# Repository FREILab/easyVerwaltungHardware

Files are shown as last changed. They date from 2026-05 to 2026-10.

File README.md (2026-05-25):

# easyVerwaltung Hardware

Firmware und Dokumentation für die **easyVerwaltung**-Hardware des FREILab. Das System steuert Maschinenzugang, Nutzungsprotokollierung und Sicherheit via RFID-Authentifizierung gegen das easyVerwaltung-Backend.

---

## Hardware-Übersicht

### RFID-Box — Maschinenfreigabe

| Projekt | Hardware | API | Status |
|---|---|---|---|
| [RFID_BOX_legacy](firmware/projects/RFID_BOX_legacy/) | ESP32 Dev1 | Legacy | Stabil — [v1.0.0](https://github.com/FREILab/easyVerwaltungHardware/releases/tag/rfid-box-legacy%2Fv1.0.0) |
| [RFID_BOX_easyVerwaltung](firmware/projects/RFID_BOX_easyVerwaltung/) | ESP32 Dev1 | easyVerwaltung | Getestet — Server noch nicht in Production |

### Tür-Steuerung

| Projekt | Hardware | API | Status |
|---|---|---|---|
| [DOOR_legacy](firmware/projects/DOOR_legacy/) | Arduino UNO R4 WiFi | Legacy | Scheduled for Deletion |
| [DOOR_legacy_ESPArdu](firmware/projects/DOOR_legacy_ESPArdu/) | RobotDyn UNO+WiFi R3 (ATmega328P + ESP8266) | Legacy | Stabil — [v1.0.0](https://github.com/FREILab/easyVerwaltungHardware/releases/tag/door-legacy-espardu%2Fv1.0.0) |
| [DOOR_easyVerwaltung](firmware/projects/DOOR_easyVerwaltung/) | Arduino UNO R4 WiFi | easyVerwaltung | In Entwicklung |

### Lasersaur HMI

| Projekt | Hardware | API | Status |
|---|---|---|---|
| [LASERSAUR_HMI_legacy](firmware/projects/LASERSAUR_HMI_legacy/) | Arduino Mega + Ethernet-Shield | Legacy | Stabil (nicht mit neuem Server getestet) — wird durch ESPArdu ersetzt |
| [LASERSAUR_HMI_ESPArdu](firmware/projects/LASERSAUR_HMI_ESPArdu/) | Mega2560 WiFi R3 (ATmega2560 + ESP8266) | Legacy | Implementiert, noch nicht getestet |
| [LASERSAUR_HMI_easyVerwaltung](firmware/projects/LASERSAUR_HMI_easyVerwaltung/) | Arduino Giga R1 | easyVerwaltung | In Entwicklung |

### Machine Node

| Projekt | Hardware | API | Status |
|---|---|---|---|
| [MachineNode_legacy](firmware/projects/MachineNode_legacy/) | ESP32-S3-WROOM-1-N16R8 | Legacy | Stabil |
| [MachineNode_easyVerwaltung](firmware/projects/MachineNode_easyVerwaltung/) | ESP32-S3-WROOM-1-N16R8 | easyVerwaltung | Geplant |

---

## Repository-Struktur

```
firmware/
  projects/          # Firmware-Targets (je ein PlatformIO-Projekt)
  shared/
    easyAPI/         # Gemeinsame Backend-Kommunikation (HTTP/JSON)
```

Jedes Projekt in `projects/` enthält eine eigene `README.md` mit Hardware-Details, DIP-Belegung, Flash-Anleitung und Debugging-Hinweisen.

---

## Einrichtung

### Voraussetzungen

- Python ≥ 3.8
- PlatformIO Core (`pip install platformio`)

### Credentials

Jedes Projekt benötigt eine `platformio.secrets.ini` (nicht in Git). Vorlage liegt als `.example`-Datei bei:

```bash
cp platformio.secrets.ini.example platformio.secrets.ini
# Datei befüllen, dann:
pio run
```

Details zu den Feldern stehen in der jeweiligen Projekt-README.

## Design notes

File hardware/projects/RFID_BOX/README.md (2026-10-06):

# Machine Node / RFID_BOX

> **Sicherheit geht vor Kosten, Baugröße und Bauteilzahl.** Das Gerät
> schaltet Netzspannung in einer Werkstatt, in der ungeschulte Personen
> daneben stehen. Wo Ziele kollidieren, gewinnt die Sicherheit.
>
> Vier Festlegungen sind bindend und werden nicht aufgeweicht:
>
> - Die Barriere Netz ↔ SELV beträgt **8 mm Luft- und Kriechstrecke** und
>   wird nicht auf den Normwert von 5 mm reduziert. Maßgeblich sind die
>   Bauteile, die sie queren, nicht das Minimum der Norm.
> - Bauteile über der Barriere brauchen **verstärkte oder doppelte
>   Isolierung** bei 250 V Arbeitsspannung. Eine hohe Prüfspannung in kV
>   allein genügt nicht — sie sagt über die Isolationsklasse nichts aus.
> - **Ein Einzelfehler darf nicht nach außen wirken.** Neue Schaltungsteile
>   werden gegen die [FMEA](#fmea) geprüft, bevor sie ins Layout gehen.
> - **Beim geöffneten Gerät ist nichts Netzführendes berührbar.** Feste
>   Abdeckplatten über dem I/O-Board geben nur die Feldterminals und den
>   Sicherungshalter frei. MCU- und RFID-Board führen kein 230 V und dürfen
>   angefasst werden. Siehe [Aufbau](#aufbau).
>
> Die Auslegung dazu steht in
> [Leiterbahnbreiten und Abstände](#leiterbahnbreiten-und-abstände).

## Einleitung

Dies ist der **RFID Node**: ein kompaktes Steuergerät, das elektrische
Geräte und Maschinen in der Werkstatt (z.B. Standfräse, Drehmaschine, FKS)
per RFID-Karte freischaltet. Er prüft die RFID-Karte einer Nutzerin oder
eines Nutzers gegen easyVerwaltung, gibt bei gültiger Berechtigung die
Maschine frei und schaltet sie beim Stopp oder bei Kartenentzug wieder ab.

Technisch ist der Node als Stack aus mehreren kompakten Platinen aufgebaut
(Netzteil/Schaltausgang, Controller mit Bedienoberfläche, RFID-Frontend),
ergänzt um optionale Erweiterungsboards für Maschinen mit zusätzlichem
Bedarf (z.B. NAMUR-I/O oder eine Notaus-/Bremsschleife). Die konkrete
Aufteilung und Auslegung folgt in den weiteren Kapiteln dieses Dokuments.

Die Anforderungen, aus denen diese Auslegung abgeleitet ist, stehen separat
in [Anforderungen.md](Anforderungen.md).

## Aufbau

Das Gehäuse ist 3D-gedruckt und staubdicht ausgeführt. Display und LED-Ring
sind von aussen sichtbar und durch eine Plexiglasscheibe geschützt; der
LED-Ring selbst sitzt dabei innerhalb des Gehäuses. Der Stopp-Knopf ist von
aussen erreichbar.

Alle Kabel werden einseitig über Kabeldurchführungen ins Gehäuse geführt, von
links nach rechts:

1. Netz-Eingang 230 V
2. Schaltausgang: geschaltete 230 V oder Steuerleitung für ein externes
   Schütz
3. Optionale Notaus-Schleife
4. Optionales Extension-I/O (NAMUR oder Digital-I/O)

Nicht verwendete Durchführungen werden verschlossen.

Die Boards werden über Board-to-Board-Stecker als Stack gesteckt und
geklipst — keine Kabelverbindungen zwischen den Platinen.

### Berührschutz

Das Gerät wird im Servicefall geöffnet, während es unter Umständen noch am
Netz hängt. Deshalb:

- Über dem I/O-Board sitzen **fest installierte, 3D-gedruckte
  Abdeckplatten**. Sie geben nur die Feldterminals und den Sicherungshalter
  frei — beide sind berührsichere Bauformen (WAGO Hebelklemme, WR-FSH mit
  Shocksafe PC2/IP20). Alles andere Netzführende bleibt abgedeckt.
- Die Platten sind kein Deckel, der beim Öffnen mitkommt: sie bleiben am
  Board bzw. am Gehäuseunterteil und lassen sich nur mit Werkzeug lösen.
- **MCU- und RFID-Board führen kein 230 V** und dürfen im geöffneten Zustand
  berührt werden. Das ist eine bindende Randbedingung, keine Momentaufnahme
  — es darf kein netzführendes Netz auf diese Boards wandern.

Zusätzlich werden alle Boards **lackiert** (Schutzlack), um den IP-Schutz
über die Lebensdauer zu stützen: Sägemehl und Feuchtigkeit sollen auf
Dauer keine Kriechpfade bilden. Vom Lack ausgenommen bleiben Feldterminals,
Sicherungskontakte und die Board-to-Board-Stecker.

Der Lack ersetzt keine Abstände: Kriech- und Luftstrecken werden weiterhin
nach [Leiterbahnbreiten und Abstände](#leiterbahnbreiten-und-abstände)
bemessen, als wäre kein Lack vorhanden.

## Elektronik

Das Gerät ist als Platinenstack aufgebaut:

- **Oberste PCB (RFID-Board):** RFID-Antenne, ggf. Display und LED-Ring.
- **Mittlere PCB (MCU-Board):** Mikrocontroller (ESP32), Buzzer und
  Peripherie.
- **Unterste PCB (I/O-Board):** 230-V-Netz und Schaltausgang, dazu die
  Extension-Header für das E-Stop Extension Board und das Extension Board.
  Hiervon gibt es **zwei getrennte Boards mit eigenem Layout**, von denen
  pro Gerät genau eines bestückt wird:
  - **I/O-Board 230V** — Lastrelais und Lastmessung zum direkten Schalten
    von Lasten bis 8 A.
  - **I/O-Board 24V** — potentialfreier Kontakt für ein externes Schütz.
    Ohne Lastpfad und Lastmessung; dadurch deutlich einfacher,
    rund 33 € günstiger und ohne Bedarf an 70 µm Kupfer.

  Beide haben denselben Formfaktor und denselben Board-to-Board-Stecker zum
  MCU-Board.

## Architektur

Neben dem festen Dreier-Stack (I/O-, MCU-, RFID-Board) gibt es zwei
optionale, steckbare Erweiterungsboards, die auf das I/O-Board gesteckt
werden:

- **Extension Board:** generisches Zusatzboard mit zwei Bestückvarianten —
  **NAMUR** (zwei optoisolierte NAMUR-Ausgänge, ein galvanisch getrennter
  NAMUR-Eingang) oder **Digital-I/O** (einfache digitale Ein-/Ausgänge, noch
  nicht spezifiziert). Ein Node trägt höchstens eine Variante.
- **E-Stop Extension Board:** einfaches Relais (24 V / 100 mA), dessen Kontakt
  in die Notaus-/Interlock-Schleife bzw. Bremsversorgung der Maschine
  eingeschleift wird. Fail-safe: stromlos = Notaus-Schleife unterbrochen;
  öffnet bei Stopp/Kartenentzug sofort, während die Hauptversorgung erst
  nach der Nachlaufzeit trennt (Details siehe
  [Anforderungen.md](Anforderungen.md)).

## Blockdiagramm

```mermaid
flowchart TB
    subgraph IO["I/O-Board — eines von beiden"]
        direction LR
        NETZ([Terminal: Netz-Eingang 230V])
        OUT([Terminal: Schaltausgang])
        REL["Lastrelais 8A<br/>(I/O-Board 230V)"]
        POTFREI["Potentialfreier Kontakt 24V 100mA<br/>(I/O-Board 24V)"]
        MESS["Lastmessung<br/>(nur I/O-Board 230V)"]

        NETZ --> MESS --> REL --> OUT
        NETZ --> POTFREI --> OUT

        subgraph ESTOP["E-Stop Extension Board (optional)"]
            direction LR
            K3[Notaus-Kontakt 24V 100mA]
            ESTOP_T([Terminal: Notaus-Schleife])
            K3 --- ESTOP_T
        end

        subgraph EXT["Extension Board (optional)"]
            direction LR
            EXTIO[NAMUR ODER Digital-I/O]
            IO_T([Terminal: Extension-I/O])
            EXTIO --- IO_T
        end
        
    end

    subgraph MCU["MCU-Board"]
        direction LR
        ESP[ESP32]
        BUZ[Buzzer]
        STOP[Stopp-Taster]
        USB([USB-C: Erstprogrammierung/Debug])

        ESP ~~~ USB
        BUZ ~~~ STOP

        ESP --- USB
    end

    subgraph RFID["RFID-Board"]
        direction LR
        NFC[NFC-Controller PN532]
        ANT[RFID-Antenne]
        DISP["Display (ggf.)"]
        RING["LED-Ring (ggf.)"]

        NFC --- ANT

        DISP ~~~ RING
    end

    RFID --- MCU
    MCU --- IO

    classDef term230 fill:#1565c0,color:#fff,stroke:#0d47a1
    classDef termSELV fill:#90caf9,color:#000,stroke:#1565c0
    classDef part230 fill:#ff9800,color:#000,stroke:#e65100
    classDef partSELV fill:#81c784,color:#000,stroke:#2e7d32

    class NETZ,OUT term230
    class ESTOP_T,IO_T,USB termSELV
    class REL,MESS part230
    class POTFREI,K3,EXTIO,ESP,BUZ,STOP,NFC,ANT,DISP,RING partSELV
```

Die Form kennzeichnet die Art des Elements, die Farbe die Spannungsebene:

- Formen: abgerundet = Terminal/Steckverbinder, eckig = Funktionsblock; als
  "(optional)" markierte Boards sind steckbare Erweiterungen im I/O-Board.
- Farben: blau = 230-V-Terminal, hellblau = Kleinspannungs-Terminal,
  orange = 230-V-führender Schaltungsteil, grün = Kleinspannungs-
  Schaltungsteil.

## Power Distribution

Die gesamte Versorgung kommt aus dem Netz-Eingang 230 V auf dem I/O-Board
und teilt sich dort in zwei Pfade:

- **Lastpfad (nur I/O-Board 230V):** Netz-Eingang → Ausgangssicherung (F300)
  → Lastrelais (K300) → Schaltausgang. Der Shunt (R300) liegt im
  **N-Rückweg**, vor dem Relais, damit die Messung unabhängig vom
  Schaltzustand versorgt und betriebsbereit bleibt.
- **Steuerpfad:** Netz-Eingang → Sicherung Steuerzweig (F302) →
  Gleichtaktdrossel (L300) → Y-Kondensatorpaar (C309, C310, Mittelabgriff
  an PE) → isoliertes AC/DC-Wandlermodul Mean Well IRM-10-24 (U301, 24 V,
  isoliert) → Regler auf 5 V (U306, Modul mit Unterspannungs- und
  Kurzschlussschutz) → 3,3 V auf dem MCU-Board für ESP32 und
  NFC-Controller. Die 24-V-Schiene aus dem IRM-10-24 versorgt zusätzlich
  die Lastrelais-Spule. LED-Ring und Buzzer laufen direkt auf 5 V.
- **ISO-Insel:** Die Lastmessung liegt auf Netzpotential. Versorgung und
  UART laufen über den Digitalisolator U300 (ISOW7721) mit integriertem
  DC-DC-Wandler, gespeist aus der SELV-Seite. Die Insel führt damit keinen
  eigenen Netzzweig. PGA-Einstellung von U302: Gain 16 am Stromkanal,
  Gain 1 am Spannungskanal. Über `ISO_EN` (U300 Pin 5, Pull-up R318 nach VDD)
  nimmt die Firmware der Insel die Versorgung und startet U302 damit neu.
  Details siehe [Leiterbahnbreiten und Abstände](#leiterbahnbreiten-und-abstände).

Die Erweiterungsboards (Extension Board, E-Stop Extension Board) werden über
den Stack aus dem Steuerpfad versorgt; ihre Feldseite (NAMUR-Kanäle,
Notaus-Schleife) bleibt galvanisch getrennt und wird extern gespeist.

Die Lastausgangssicherung (F300) ist gesockelt und nach dem Öffnen des
Gehäuses ohne Löten tauschbar; eine Ersatzsicherung wird im Gehäuse
mitgeführt. Die Gerätesicherung (F302) ist als dokumentierte Ausnahme fest
verlötet (siehe [Anforderungen.md](Anforderungen.md), S5).

Am Netz-Eingang liegen RV300 als Überspannungsschutz und C300 als
X2-Kondensator, beide als Parallelelemente gegen den Netzknoten. Das
Gleichtaktfilter aus L300 und C309/C310 sitzt im Steuerzweig direkt vor
U301, also an der Störquelle; damit sind Netz-Eingang und Schaltausgang
gleichermaßen abgedeckt. Der Lastpfad trägt kein Filterbauteil.

Eine Kontakt-Schutzbeschaltung am Lastrelais gibt es nicht: der Node ist
Lastschalter, das Entkoppeln der Lastgeräte vom Netz ist nicht seine Aufgabe.
Eine Einschaltstrombegrenzung im Lastpfad gibt es bewusst nicht: den Anlauf
tragen die träge Ausgangssicherung F300 und das Einschaltvermögen von K300
(30 A, AgCdO-Kontakte). Das Lastrelais (K300) trennt L und
N gemeinsam (2-polig), da die
N/L-Zuordnung an der Werkstatt-Steckdose nicht garantiert eindeutig ist.
PE wird unverändert vom
Netz-Eingang zum Schaltausgang durchgeschleift und trägt zusätzlich den
Mittelabgriff von C309/C310; da das Gehäuse aus Kunststoff besteht, gibt es
keine Verbindung zu einer Gehäusemasse.

```mermaid
flowchart TB
    NETZ([Netz-Eingang<br/>230V 8A])
    EMV["EMV-Maßnahmen<br/>Überspannungsschutz + X2-Kondensator"]
    FLAST["Ausgangssicherung F300<br/>230V 10A träge"]
    MESS["Lastmessung<br/>Shunt im N-Rückweg"]
    REL["Lastrelais<br/>Spule 24V / Kontakt 230V 8A"]
    OUT([Schaltausgang <br/>230V 8A])
    PE([PE / Schutzleiter<br/>durchgeschleift])

    FSTEUER["Sicherung F302<br/>Steuerzweig<br/>230V 500mA"]
    FILT["EMV-Filter<br/>Gleichtaktdrossel + Y-Kondensatoren"]
    ACDC["AC/DC-Wandler<br/>Mean Well IRM-10-24<br/>→ 24V, isoliert"]
    REG5V["Regler 5V<br/>(Modul mit UV-/Kurzschlussschutz)"]
    V5[5V: LED-Ring, Buzzer, Erweiterungsboards]
    V33[3V3-Regler]
    LOGIK[ESP32, NFC-Controller]
    ISO["Digitalisolator<br/>mit isoliertem DC-DC<br/>→ 3V3, netzbezogen"]

    NETZ -->|"[PIN_L]"| EMV
    EMV -->|"[PIN_L]"| FLAST
    FLAST -->|"[PIN_FUSED_L]"| REL
    NETZ -->|"[PIN_N]"| MESS
    MESS --> REL
    REL -->|"[PIN_*_SWITCHED]"| OUT
    EMV -->|"[PIN_L]"| FSTEUER
    FSTEUER --> FILT
    FILT -->|"[PIN_CTRL_L/N]"| ACDC
    FILT -.- PE
    ACDC -->|"[+24V]"| REG5V
    ACDC -->|"[+24V]"| REL
    REG5V -->|"[+5V]"| V5
    REG5V -->|"[+5V]"| V33
    V33 -->|"[+3V3]"| LOGIK
    V33 -->|"[+3V3]"| ISO
    ISO -->|"[+3V3_ISO]"| MESS
    NETZ -->|"[PIN_PE]"| PE
    PE -->|"[PIN_PE]"| OUT

    linkStyle 0,1,6 stroke:#b71c1c,stroke-width:2px
    linkStyle 2,3,4 stroke:#e53935,stroke-width:2px
    linkStyle 5 stroke:#ef6c00,stroke-width:2px
    linkStyle 9 stroke:#757575,stroke-width:1.5px,stroke-dasharray:3 3
    linkStyle 7 stroke:#f4511e,stroke-width:2px
    linkStyle 8 stroke:#c62828,stroke-width:2px
    linkStyle 10,11 stroke:#fdd835,stroke-width:2px
    linkStyle 12,13 stroke:#2e7d32,stroke-width:2px
    linkStyle 14,15 stroke:#00897b,stroke-width:2px
    linkStyle 16 stroke:#8e24aa,stroke-width:2px
    linkStyle 17,18 stroke:#43a047,stroke-width:2px

    classDef term230 fill:#1565c0,color:#fff,stroke:#0d47a1
    classDef part230 fill:#ff9800,color:#000,stroke:#e65100
    classDef partSELV fill:#81c784,color:#000,stroke:#2e7d32
    classDef pe fill:#e8f5e9,color:#1b5e20,stroke:#43a047

    class NETZ,OUT term230
    class EMV,FLAST,MESS,REL,FSTEUER,FILT part230
    class ACDC,REG5V,V5,V33,LOGIK,ISO partSELV
    class PE pe
```

| Netz | Bedeutung |
|---|---|
| `[PIN_L]` | Netzknoten, ungesichert; hier liegen RV300 und C300 parallel |
| `[PIN_FUSED_L]` | Lastpfad nach Ausgangssicherung, bis zum Lastrelais |
| `[PIN_N]` | N-Rückweg vom Eingangsterminal bis zum Shunt; das Stück Shunt → Lastrelais trägt kein eigenes Label |
| `[PIN_L_SWITCHED]`, `[PIN_N_SWITCHED]` | Geschaltete Phase und geschalteter N hinter dem Lastrelais |
| `[PIN_CTRL_L]`, `[PIN_CTRL_N]` | Steuerzweig nach L300, speist U301; hier liegt das Y-Paar C309/C310 gegen PE. Das Stück F302 → L300 trägt kein eigenes Label |
| `[+24V]` | Geregelte 24-V-Schiene aus dem AC/DC-Wandler IRM-10-24 (U301), versorgt die Lastrelais-Spule und den Eingang des 5V-Reglers |
| `[+5V]` | 5-V-Schiene (Schutz durch integrierten Modulschutz des Reglers) |
| `[+3V3_ISO]` | Netzbezogene 3,3-V-Versorgung der Lastmessung (U302) aus dem Digitalisolator (U300) |
| `[GND_ISO]` | Messreferenz der ISO-Insel, hart am Shunt-Knoten |
| `[GND2_ISO]` | Rückweg des isolierten DC-DC-Wandlers, von `GND_ISO` durch einen Ferrit getrennt |
| `[+3V3]` | Logikversorgung |
| `[PIN_PE]` | Schutzleiter, unverändert durchgeschleift, trägt den Mittelabgriff von C309/C310, kein Bezug zum Kunststoffgehäuse |

Bemessung des Gleichtaktfilters: im Gleichtakt liegen die Y-Kondensatoren
parallel, `C_CM = 2 · Cy`, und mit `f₀ = 1 / (2π · √(L · C))` steigt die
Dämpfung oberhalb f₀ mit 40 dB/Dekade. Auslegungspunkt ist 150 kHz, Ziel
20 dB. Gerechnet wird mit dem Toleranz-Worst-Case der Drossel (−30 %) und
dem Temperaturgang des Y5U-Dielektrikums, nicht mit den Nennwerten.

Drei Grenzen der Auslegung:

- Der Mittelabgriff nach PE ist zwingend — ohne ihn hat der
  Gleichtaktstrom im Kunststoffgehäuse keinen Rückweg, und die Drossel
  wirkt nur noch über ihre Streuinduktivität.
- Cy ist nach oben durch den Ableitstrom begrenzt; mehrere Nodes hängen am
  selben FI-Kreis.
- L nominal im Fenster 3–10 mH: nach unten setzt die Eckfrequenz die
  Grenze, nach oben die Eigenresonanz der Drossel.

Zwei Abschnitte tragen im Schaltplan kein eigenes Netzlabel: F302 → L300 und
Shunt → Lastrelais.

## Signalfluss

Analog zur Power Distribution beginnt auch der Signalfluss am Eingang
(RFID-Karte) und endet am Schaltausgang — hier geht es aber nicht um die
Leistungs-, sondern um die Steuersignale, die entscheiden, ob der
Schaltausgang aktiv ist.

Der Stopp-Taster wirkt auf den ESP32 (Firmware-Status `STOPPED`); dieser
schaltet, falls bestückt, das E-Stop Relais aus. Es gibt keinen separaten
hardwareseitigen Bypass am E-Stop Relais, der unabhängig von der Firmware
wirkt. Der Relaistreiber der Hauptversorgung bekommt **keinen** direkten
Hardware-Interlock vom Stopp-Taster: die Hauptversorgung wird
ausschliesslich vom ESP32 nach Ablauf der Nachlaufzeit abgeschaltet (siehe
Power Distribution und Anforderungen.md). Das Enable bleibt vollständig auf
der SELV-Seite: die Relaisspule hängt an der 24-V-Schiene aus dem isolierten
IRM-10-24 und wird von **zwei Schaltern in Reihe** geführt — einem
Low-Side-NMOS (Q300) und einem High-Side-PMOS (Q301) an getrennten GPIOs.
Beide gehen im Ruhezustand über Pulldown bzw. Pull-up sicher auf, und ein
durchlegierter Schalter lässt sich über den anderen noch abschalten (siehe
FMEA). Die Isolationsbarriere quert nur die UART der Lastmessung, über den
Digitalisolator U300 — er führt zugleich die Versorgung der Insel
hinüber.

```mermaid
flowchart TB
    Antenne([RFID-Antenne])
    NFC["NFC-Controller PN532<br/>[3V3]"]
    ESP["ESP32<br/>[3V3]"]
    STOP["Stopp-Taster<br/>[3V3]"]
    TREIBER["Relaistreiber<br/>Low-Side NMOS + High-Side PMOS<br/>Gate [3V3] / Spule [24V]"]
    REL["Lastrelais<br/>Spule [24V] / Kontakt [230V]"]
    OUT([Terminal: Schaltausgang])

    MESS["Lastmessung<br/>Steuerseite<br/>Signal [3V3_ISO], netzbezogen"]
    OPTO_FB["Digitalisolator<br/>UART und Versorgung der Insel"]

    EXT["Extension Board<br/>[5V]"]
    ESTOP["E-Stop Relais<br/>[5V]"]
    OLED["OLED (ggf.)<br/>[3V3]"]

    Antenne -->|RF-Feld| NFC
    NFC -->|SPI| ESP
    ESP -->|Enable| TREIBER
    TREIBER -->|Ansteuerung| REL
    REL --> OUT

    STOP -->|I/O| ESP

    MESS <-->|UART| OPTO_FB
    OPTO_FB <-->|UART, isoliert| ESP

    ESP -->|I/O| EXT
    ESP -->|Enable| ESTOP
    ESP -->|I2C| OLED

    classDef term230 fill:#1565c0,color:#fff,stroke:#0d47a1
    classDef part230 fill:#ff9800,color:#000,stroke:#e65100
    classDef partSELV fill:#81c784,color:#000,stroke:#2e7d32
    classDef iso fill:#fff,color:#000,stroke:#6a1b9a,stroke-width:3px
    classDef touch230 fill:#fdd835,color:#000,stroke:#f57f17

    class OUT term230
    class REL part230
    class Antenne,NFC,ESP,STOP,EXT,ESTOP,OLED,TREIBER partSELV
    class MESS touch230
    class OPTO_FB iso
```

Formen und Farben wie im Blockdiagramm (abgerundet = Terminal/Eingabe,
eckig = Funktionsblock); zusätzlich: weiss mit violettem Rahmen =
Optokoppler / Isolationsbarriere, gelb = Signalpegel isoliert/SELV, aber
das Bauteil selbst berührt die 230-V-Seite (z.B. Lastmessung). Die
Spannungsangabe `[…]` in den Blöcken zeigt den jeweiligen Signalpegel,
analog zu den Netznamen im Power-Distribution-Diagramm.

## Bauteilauswahl

Bereits festgelegte Bauteile für die in den vorherigen Kapiteln gezeigten
Funktionsblöcke. Preise sind Einzelstückpreise, sofern nicht anders
angegeben (z.B. "@10 Stk"); wo kein Distributorpreis vorliegt, ist der Wert
geschätzt (·). Lieferant/Bestellnummer sind nur eingetragen, wo bereits
konkret geprüft; "*offen*" heisst nicht unbekannt/unmöglich, sondern noch
nicht recherchiert.

Die Liste umfasst beide I/O-Boards. Nur auf dem **I/O-Board 230V** sitzen
K300, U302, R300, der Digitalisolator U300 mit seinen Ferriten und
Abblockkondensatoren sowie F301 mit Halter F300 und Ersatzsicherung —
zusammen rund 40 €. Nur auf dem **I/O-Board 24V** sitzen K2 und seine Polyfuse,
zusammen rund 2 €. Alles Übrige ist auf beiden Boards identisch oder gehört
zu MCU- und RFID-Board.

### ICs & Module

| Funktion | Hersteller / Teilenummer | Beschreibung | Lieferant / Bestellnummer | Preis |
|---|---|---|---|---:|
| Mikrocontroller | Espressif<br>ESP32-S3-WROOM-1-N16R8 | MCU-Modul mit WLAN/BLE, 16MB Flash, 8MB PSRAM | Mouser<br>356-ESP32S3WRM1N16R8 | 4,82 € @25 Stk |
| Leistungsmessung (U302) | Microchip<br>MCP39F511A-E/MQ | AC/DC-Energiemess-IC, UART-Schnittstelle, 28-QFN | Digikey<br>MCP39F511A-E/MQ-ND | 2,5684 € @25 Stk |
| RFID-Controller | NXP<br>PN5321A3HN/C106 | NFC-Frontend-IC (ISO14443), SPI-Schnittstelle | Mouser<br>771-PN5321A3HN10 | 11,25 € @1 Stk |
| AC/DC-Wandler 24V (Steuerpfad, U301) | Mean Well<br>IRM-10-24 | 10W isoliert, 24V/0,42A, 4,2kVac I/P-O/P, Isolationsklasse II, PCB-Mount | Digikey<br>1866-3030-ND | 5,650 € @25 Stk |
| Regler 5V (Steuerpfad, U306) | RECOM<br>R-78K5.0-2.0 | DC/DC-Wandler 24V→5V, 2A, SIP3/TO-220-kompatibel | Digikey<br>945-R-78K5.0-2.0-ND | 4,71 € @25 Stk |
| 3V3-Regler (nicht isoliert, ESP32/NFC) | Diodes<br>AP2114H-3.3TRG1 | LDO 3,3V/1A, SOT-223-3, Ruhestrom 65µA, Dropout 450mV @1A, PSRR 65dB, Fold-back-Strombegrenzung, θJA 128°C/W | Digikey<br>AP2114H-3.3TRG1DICT-ND | 0,1652 € @25 Stk |
| Digitalisolator + isolierter DC-DC (U300) | Texas Instruments<br>ISOW7721DFMR | 2 Kanäle (1 hin, 1 zurück), integrierter DC-DC 3,3V/60mA, verstärkte Isolierung VDE 0884-17, Luft-/Kriechstrecke >8mm, SOIC-20 wide | Digikey<br>296-ISOW7721DFMRCT-ND | 5,4308 € @25 Stk |
| Relaistreiber Low-Side (Q300) | Nexperia<br>2N7002NXAKR | NMOS 60V/190mA, SOT-23, Rds(on) 4,5Ω max @Vgs 10V; in der Spulenrückleitung nach GND | Digikey<br>1727-8643-1-ND | 0,0522 € @50 Stk |
| Relaistreiber High-Side (Q301) | Nexperia<br>BSS84AK,215 | PMOS 50V/180mA, SOT-23, Rds(on) 7,5Ω max @Vgs −10V, Vgs ±20V; in der 24V-Zuleitung der Spule — redundanter zweiter Schalter (siehe FMEA) | Digikey<br>1727-1144-1-ND | 0,063 € @50 Stk |
| Pegelwandler High-Side (Q302) | Nexperia<br>2N7002NXAKR | zieht den Fusspunkt des Gate-Teilers von Q301 nach GND, Drain sieht 24V | Digikey<br>1727-8643-1-ND | 0,0522 € @50 Stk |
| Freilaufdiode Relaisspule (D305) | onsemi<br>BAS16LT1G | 100V/200mA, SOT-23, VF ~1,1V @76mA; über der Spule, wirkt unabhängig davon welcher Schalter öffnet | Digikey<br>BAS16LT1GOSCT-ND | 0,0408 € @50 Stk |
| Pegelwandler LED-Ring (3V3→5V) | diverse<br>74AHCT125 | Quad-Buffer/Levelshifter 3,3V→5V | *offen* | ca. 0,30 € · |

### Widerstände

| Funktion | Hersteller / Teilenummer | Beschreibung | Lieferant / Bestellnummer | Preis |
|---|---|---|---|---:|
| Shunt (Leistungsmessung, R300) | Bourns<br>CRF2010-FZ-R002ELF | 2mOhm ±1%, ±50ppm/°C, 1,5W, 2010, Metallband, therm. EMK <3µV/°C, <5nH | Mouser<br>652-CRF2010FZR002ELF | 0,28 € @25 Stk |
| Relaistreiber (R312–R318) | *offen* | 0603, 1%: R313/R314 je 47k (Gate-Teiler Q301), R312/R315 je 1k (Gate-Vorwiderstände), R316/R317 je 47k (Gate-Pulldowns Q300 und Q302), R318 47k (Pull-up ISO_EN an U300 Pin 5) | *offen* | ca. 0,07 € · |

### Kondensatoren

| Funktion | Hersteller / Teilenummer | Beschreibung | Lieferant / Bestellnummer | Preis |
|---|---|---|---|---:|
| X2-Kondensator (EMV, C300) | Würth Elektronik<br>890334023023CS | Funkentstörkondensator X2 (MKP), 100nF, 310VAC/560VDC, Rastermaß 10mm | Digikey<br>732-5733-ND | 0,35 € @1 Stk |
| Y-Kondensatoren (EMV, C309/C310) | Vishay BCcomponents<br>VY2472M49Y5US63L7 | Funkentstörkondensator Y2 (Keramikscheibe), 4,7nF ±20%, X1 440VAC / Y2 300VAC, Y5U, ⌀12,5×5,0mm, Rastermaß 7,5mm, IEC 60384-14 / VDE / UL, 2× je Board | Digikey<br>VY2472M49Y5US63L7-ND | 0,208 € @50 Stk |
| Ausgangs-Stützkondensator (U301) | Murata<br>GCM155R71H104KE02J | 100nF/50V, 0805 (C301) | Mouser<br>81-GCM155R71H104KE2J | 0,021 € @10 Stk |
| Ausgangs-Elko (U301) | Würth Elektronik<br>860010673012 | 47µF/50V (C302) | Mouser<br>710-860010673012 | 0,129 € @1 Stk |
| Ausgangs-MLCC (U306) | Murata<br>GRM21BR71A106KA73K | 10µF/10V, 0805 (C303); derselbe Typ auch als Ein- und Ausgangskondensator des 3V3-Reglers (min. 4,7µF gefordert, Derating bei 5V prüfen) | Mouser<br>81-GRM21BR71A106KA3K | 0,04 € @10 Stk |
| Abblockung Isolator (C304–C308, C311–C317) | *offen* | je Versorgungspin 10nF + 1µF + 10µF, vier Gruppen für VIO, VDD, VISOIN, VISOOUT; die 10nF < 1mm vom Pin, Baugröße 0603 (kleinste auf dem Board verwendete) | *offen* | ca. 0,30 € · |

### Induktivitäten

| Funktion | Hersteller / Teilenummer | Beschreibung | Lieferant / Bestellnummer | Preis |
|---|---|---|---|---:|
| Gleichtaktdrossel (EMV, L300) | TE Connectivity Schaffner<br>RN102-1-02-3M0 | Stromkompensierte Drossel, 3,0mH, 1A @40°C, 300VAC, DCR 210mΩ, Hipot 1500VAC/60s, IEC/EN 60938-1 + UL 1283, ENEC/VDE, UL 94 V-0, Körper 10×10×9mm, Rastermaß 4mm, bedrahtet | Digikey<br>817-2084-ND | 1,662 € @10 Stk |
| Ferrite Isolator (FB303, FB304, FB306, FB307) | Murata<br>BLM15EX331SN1D | 330 Ohm @100MHz, 0402 — Typ vom Isolator-Datenblatt vorgegeben; an VISOOUT→VISOIN, GND2_ISO→GND_ISO sowie in den Zuleitungen VIO und VDD | Digikey<br>490-18371-1-ND | 0,089 € @25 Stk |
| Ferrite Messabgriffe (FB300–FB302) | Bourns<br>MH2029-601Y | 600 Ohm @100MHz, 0805 — im Abgriff des HV-Teilers und in den beiden Shunt-Sense-Leitungen | Mouser<br>652-MH2029-601Y | 0,05 € @25 Stk |

### Relais & Schutzbeschaltung

| Funktion | Hersteller / Teilenummer | Beschreibung | Lieferant / Bestellnummer | Preis |
|---|---|---|---|---:|
| Lastrelais (K300) | TE Connectivity<br>T92S11D12-24 (9-1393211-0) | 2-polig (N+L), 2 Form C, AgCdO, 30A/40A NO, verstärkte Isolation Spule/Kontakt 8mm/9,5mm/4kVrms, Höhe 30,7mm | Digikey<br>PB352-ND | 27,46 € @30 Stk |
| Potentialfreier Kontakt (K2) | Omron<br>G5V-1-2 DC24 | 100mA/24V, Spule 24V | Digikey<br>Z11621-ND | 1,9556 € @25 Stk |
| Polyfuse (K2) | Yageo<br>SMD1812B020TF-J | PTC-Rückstellsicherung, Hold 0,2A, Trip 0,4A, 60V, SMD | Mouser<br>603-SMD1812B020TF-J | 0,095 € @10 Stk |
| E-Stop-Relais (K3) | Omron<br>G5V-1-2 DC24 | 100mA/24V, Spule 24V | Digikey<br>Z11621-ND | 1,9556 € @25 Stk |
| Polyfuse (K3) | Yageo<br>SMD1812B020TF-J | PTC-Rückstellsicherung, Hold 0,2A, Trip 0,4A, 60V, SMD | Mouser<br>603-SMD1812B020TF-J | 0,095 € @10 Stk |
| Überspannungsschutz (EMV, RV300) | TDK<br>B72210S0271K101 (SIOV-S10K275) | Metalloxid-Varistor, 275VAC/430V, 2500A Stoßstrom, bedrahtet Ø12,5mm | Digikey<br>495-3786-ND | 0,186 € @25 Stk |
| Gerätesicherung (F302) | Bel Fuse<br>MRT 500-BULK | 500mA/250VAC träge, IEC 60127-3 Sheet 4, Schmelz-I²t 1,5A²s, ENEC/cULus/CCC, THT radial RM 5,08mm, fest verlötet (Abweichung von S5, siehe Anforderungen.md) | Digikey<br>5923-MRT500-BULK-ND | 0,402 € @10 Stk |
| Lastausgangssicherung (F301, Einsatz in Halter F300) | Schurter<br>0034.3127 (FST 5x20) | 10A/250V träge | Digikey<br>486-1226-ND | 0,414 € @50 Stk |
| Sicherungshalter (F300) | Würth<br>WR-FSH 696309001002 | VDE 10A, Berührschutz Shocksafe PC2/IP20, THT stehend | Digikey<br>732-11383-ND | 1,30 € @10 Stk |
| Ersatzsicherung (im Gehäuse) | Schurter<br>0034.3127 (FST 5x20) | Reserve wie F301, im Gehäuse mitgeführt | Digikey<br>486-1226-ND | 0,414 € @50 Stk |

### Steckverbinder & Bedienelemente

| Funktion | Hersteller / Teilenummer | Beschreibung | Lieferant / Bestellnummer | Preis |
|---|---|---|---|---:|
| Netz-Eingang / Schaltausgang (Terminal, J300) | WAGO<br>2604-1103 | 3-pol. Hebelklemme, Rastermaß 5mm | Digikey<br>2946-2604-1103-ND | 2,95 € @50 Stk |
| USB-C-Buchse (Service) | *offen*<br>USB4105-GF-A | THT | *offen* | ca. 0,30 € · |
| Stopp-Taster | *offen* | Panelmontage, IP65, 12mm | *offen* | ca. 1,50 € · |

### Anzeige & Akustik

| Funktion | Hersteller / Teilenummer | Beschreibung | Lieferant / Bestellnummer | Preis |
|---|---|---|---|---:|
| OLED | Displaytech<br>DT010ATFT | 1" IPS-LCD mit integriertem Controller, I2C-Ansteuerung | Mouser<br>758-DT010ATFT | 10,92 € @10 Stk |
| LED-Ring | Inolux<br>IN-PI20TATPRPGPB | 12x, 2020-Gehäuse, adressierbar über Single-Wire-Protokoll (WS2812B-kompatibel) | Digikey<br>1830-IN-PI20TATPRPGPBCT-ND | 0,2225 € @100 Stk |
| Buzzer | TDK<br>PS1240P02BT | Piezo-Buzzer ohne Oszillator, Pin-Terminal (THT), externe Ansteuerung (Resonanz ~4kHz) | Digikey<br>445-2525-1-ND | 0,3844 € @25 Stk |

### Sonstige

| Funktion | Hersteller / Teilenummer | Beschreibung | Lieferant / Bestellnummer | Preis |
|---|---|---|---|---:|
| Extension Board (NAMUR/Digital-I/O) | *offen (eigenes Board, kein Einzelbauteil)* | | | — |

**Summe: ca. 89,00 €** (1× je Zeile über alle Kategorien, ohne Mengen und
ohne Extension Board). Die Summe zählt jede Zeile einfach (auch wo "/Stk"
steht, z.B. LED-Ring, Sicherungen); sie berücksichtigt keine tatsächlich
benötigten Stückzahlen pro Board (z.B. 12× LED, mehrere
Sicherungen/Terminals) und ist daher kein vollständiger BOM-Preis, sondern
ein grober erster Anhaltspunkt.

## Leiterbahnbreiten und Abstände

### 1. Fertigungsbasis

| Board | Lagen | Kupfer |
|---|---|---|
| I/O-Board 230V | 2 | **70 µm (2 oz)** |
| I/O-Board 24V | 2 | 35 µm |
| MCU-Board | **4** | 35 µm außen, 17,5 µm innen |
| RFID-Board | 2 | 35 µm |

Nur das I/O-Board 230V braucht 70 µm: dort läuft der 8-A-Lastpfad. Auf dem
I/O-Board 24V fliesst nur der Eigenverbrauch des Geräts.

Alle FR4, 1,6 mm. Fertigungsuntergrenzen: 0,2 mm Bahn/Abstand, 0,3 mm
Bohrung, 0,5 mm Via, 0,5 mm Kupfer zur Boardkante, 1,0 mm Fräsnut.

Ein Punkt, der leicht übersehen wird: die Innenlagen sind nur 17,5 µm, und
IPC-2221 rechnet für sie mit halbem Faktor (k = 0,024). Eine Innenlagenbahn
braucht damit rund das Fünffache der Außenlagenbreite — 2 A dort 6,2 mm
statt 1,2 mm.

### 2. Leiterbahnbreiten

Grundlage IPC-2221 für Außenlagen, `A = (I / (k · ΔT^0,44))^(1/0,725)` mit
k = 0,048 (außen) bzw. 0,024 (innen), **ΔT = 5 K**. Unterhalb von ~2 A sind
die Breiten nicht thermisch bestimmt, sondern durch Spannungsabfall und
mechanische Robustheit — die Spalte "rechnerisch" liegt dort deutlich unter
dem Designwert.

Via-Größen als Referenz, Restring ≥ 0,125 mm je Seite. Belastbarkeit nach
derselben Formel über den Barrel-Querschnitt `A = π · d · t`, t = 20 µm
Galvanik:

| Bohrung | Pad | Aspect Ratio | Barrel-Querschnitt | je Via @ ΔT 5 K | Verwendung |
|---:|---:|---:|---:|---:|---|
| **⌀0,2 mm** | 0,45 mm | 8:1 | 0,013 mm² | 0,8 A | enge Bereiche mit Kleinstströmen |
| **⌀0,3 mm** | 0,6 mm | 5,3:1 | 0,019 mm² | 1,1 A | Signale, GND-Stitching |
| **⌀0,6 mm** | 1,0 mm | 2,7:1 | 0,038 mm² | 1,9 A | Versorgungsschienen |
| **⌀1,0 mm** | 1,4 mm | 1,6:1 | 0,063 mm² | 2,7 A | Lastpfad |

Stückzahlen in den Tabellen mit Faktor 0,7 für eng gesetzte Via-Felder
gerechnet.

#### 2.1 I/O-Board 230V — 2 Lagen, 70 µm

**P:** = Primärseite, Netzpotential · **S:** = Sekundärseite, SELV. Innerhalb
jeder Gruppe von hoher zu niedriger Spannung; die ISO-Insel schliesst die
P-Gruppe ab, weil sie trotz 3,3-V-Pegeln zur Primärseite gehört.

| Klasse | Netze | Bemessung | Rechnerisch | Breite | Vias |
|---|---|---|---:|---:|---|
| **P:** 230 V Lastpfad | `PIN_L`, `PIN_N`, `PIN_FUSED_L`, `PIN_L_SWITCHED`, `PIN_N_SWITCHED` | 8 A → ≥ 0,28 mm² | 4,03 mm | **4,0 mm** / Polygon | kein Lagenwechsel; unvermeidbar: **5 × ⌀1,0 mm** oder **8 × ⌀0,6 mm** |
| **P:** PE | `PIN_PE` | 8 A → ≥ 0,28 mm² | 4,03 mm | **4,0 mm** | wie Lastpfad; die Stichleitung zum Y-Paar ist kurz und direkt zum PE-Terminal zu führen, nicht über den Lastpfad |
| **P:** 230 V Steuerzweig | F302 → L300 (ohne Label), `PIN_CTRL_L/N` (L300 → U301, mit C309/C310 gegen PE) | ≤ 500 mA (F302; real ~50 mA) | 0,09 mm | **1,0 mm** | **1 × ⌀0,6 mm** |
| **P:** Signale ISO-Insel | `+3V3_ISO` (U300 → U302), `GND_ISO`, `GND2_ISO`, UART U302 ↔ U300, Shunt-Sense von R300 | ≤ 20 mA | < 0,05 mm | **0,4 mm** | **1 × ⌀0,2 mm** |
| **P:** GND ISO-Insel | `GND_ISO` | — | — | eigene Massefläche | Stitching ⌀0,2 mm |
| **S:** 24 V | `+24V` (Spule K300, Eingang U306) | ≤ 500 mA | 0,09 mm | **0,8 mm** | **1 × ⌀0,6 mm** |
| **S:** 5 V | `+5V` (Erzeugung + Weitergabe in den Stack) | ≤ 2 A | 0,59 mm | **1,0 mm** | **2 × ⌀0,6 mm** |
| **S:** 3,3 V | `+3V3` (U307 → Stack und U300) | ~285 mA Mittel, ~630 mA Spitze | 0,12 mm | **0,5 mm** | **1 × ⌀0,3 mm** |
| **S:** Signale | Enable zum Relaistreiber, `ISO_EN`, UART von U300, Stack-Signale | < 100 mA | < 0,05 mm | **0,3 mm** | **1 × ⌀0,3 mm** |
| **S:** GND | `GND` | — | — | Massefläche | Stitching ⌀0,3 mm, Raster ≤ 10 mm |

- Lastpfad als Polygon, ohne Lagenwechsel. Untergrenze an unvermeidbaren
  Engstellen 2,65 mm (ΔT 10 K); Bauteilpads ausgenommen (R300 als 2010
  schnürt auf ~2,5 mm ein und liegt damit auf der 10-K-Schwelle).
- R300 in Kelvin-Anbindung, Sense-Abgriffe direkt an den Pads.
- Die Netzklassen im KiCad-Projekt tragen noch keine Breiten und Abstände;
  eine Klasse `3V3` fehlt, `+3V3` hängt derzeit in `Signals`.

#### 2.2 I/O-Board 24V — 2 Lagen, 35 µm

Ohne Lastpfad und Lastmessung. Der Netz-Eingang speist nur
noch den Steuerzweig, also den Eigenverbrauch des Geräts — es gibt auf
diesem Board nirgends 8 A. Das EMV-Filter aus L300 und C309/C310 sitzt wie
beim I/O-Board 230V vor U301 und wird unverändert übernommen; RV300 und
C300 bleiben am Eingang. **F:** = Feldseite, extern gespeist.

| Klasse | Netze | Bemessung | Rechnerisch | Breite | Vias |
|---|---|---|---:|---:|---|
| **P:** 230 V Eingang + Steuerzweig | `PIN_L`, `PIN_N`, `PIN_CTRL_L/N` | ≤ 500 mA (F302; real ~50 mA) | 0,13 mm | **1,0 mm** | **1 × ⌀0,6 mm** |
| **P:** PE | `PIN_PE` | kein Laststrom, endet am Eingangsterminal, trägt den Mittelabgriff von C309/C310 | — | **1,0 mm** | — |
| **S:** 24 V | `+24V` (Spule K2, Eingang U306) | ≤ 500 mA | 0,13 mm | **0,8 mm** | **1 × ⌀0,6 mm** |
| **S:** 5 V | `+5V` (Erzeugung + Weitergabe in den Stack) | ≤ 2 A | 1,19 mm | **1,3 mm** | **2 × ⌀0,6 mm** |
| **S:** Signale | Enable zum Relaistreiber, Stack-Signale | < 100 mA | < 0,05 mm | **0,3 mm** | **1 × ⌀0,3 mm** |
| **S:** GND | `GND` | — | — | Massefläche | Stitching ⌀0,3 mm, Raster ≤ 10 mm |
| **F:** Kontakt K2 | `C`, `NO`, `NC` zum Feldterminal | ≤ 100 mA, extern gespeist | < 0,05 mm | **0,5 mm** | **1 × ⌀0,3 mm** |

- Die Barriere Netz ↔ SELV gilt unverändert mit 8 mm, auch ohne Lastpfad.
  Sie verläuft hier nur um den Eingangsbereich und U301 herum.
- Keine ISO-Insel: `GND_ISO` und die Messdomäne entfallen komplett.
- Der Relaistreiber ist wie beim I/O-Board 230V redundant aus Q300 und Q301
  aufgebaut, nur mit der kleineren Spule von K2.

#### 2.3 MCU-Board — 4 Lagen, 35 µm außen / 17,5 µm innen

Lagenaufbau: **L1** Signal + Bauteile · **L2** GND durchgehend ·
**L3** Flächen `+3V3` / `+5V` · **L4** Signal + Stack-Stecker.

| Klasse | Netze | Bemessung | Rechnerisch (L1/L4) | Breite | Vias |
|---|---|---|---:|---:|---|
| 5 V | `+5V` (LED-Ring, Buzzer, Weitergabe) | ≤ 2 A | 1,19 mm | **1,3 mm** | **2 × ⌀0,6 mm** |
| 3,3 V | `+3V3` (ESP32-S3, OLED, PN532 über Stack, U300) | ~285 mA Mittel, ~630 mA Spitze | 0,46 mm | **0,5 mm** | **2 × ⌀0,3 mm** |
| LED-Daten | Single-Wire nach 74AHCT125, 5 V | < 100 mA | < 0,05 mm | **0,25 mm** | **1 × ⌀0,3 mm** |
| Signale | SPI, I2C, UART, GPIO, Stopp-Taster | < 100 mA | < 0,05 mm | **0,25 mm** | **1 × ⌀0,3 mm** |
| USB D+/D− | Service-Buchse J4 | Full Speed | impedanzbestimmt | **0,25 mm**, eng gekoppelt | **keine** im Paar |
| GND | `GND` | — | — | durchgehende Lage L2 | Stitching ⌀0,3 mm, ≤ 5 mm am Modulrand |

- Strom auf L2/L3 nur als Fläche, nie als Bahn (2 A bräuchten dort 6,2 mm).
- L2 nicht aufschneiden; Signalwechsel L1↔L4 mit GND-Via daneben.
- Antennen-Keepout des WROOM-Moduls gilt auf **allen vier** Lagen.
- **Kupferfläche am Tab des 3V3-Reglers**, mindestens 100 mm². Der Tab liegt
  auf VOUT, die Fläche ist also die 3,3-V-Fläche. Ohne sie erreicht die
  Sperrschicht bei Lastspitzen die Abschaltschwelle.

Stromabschätzung der 3,3-V-Schiene — Grundlage für die Bemessung oben:

| Verbraucher | Mittel | Spitze | Grundlage |
|---|---:|---:|---|
| ESP32-S3-WROOM-1 | 120 mA | 400 mA | Schätzung, WLAN assoziiert / TX-Burst |
| PN5321 inkl. Antennentreiber | 80 mA | 120 mA | Schätzung, hängt an der Antennengüte |
| OLED inkl. Backlight | 30 mA | 30 mA | Schätzung |
| ISOW7721 (U300) | 44 mA | 67 mA | Datenblatt 5.10, interpoliert für 17 mA Insellast |
| Pull-ups, Sonstiges | 10 mA | 10 mA | Schätzung |
| **Summe** | **~285 mA** | **~630 mA** | |
- USB ist Full Speed, keine Impedanzkontrolle nötig: symmetrisch, < 50 mm,
  durchgehend über L2, keine Stubs.

#### 2.4 RFID-Board — 2 Lagen, 35 µm

| Klasse | Netze | Bemessung | Rechnerisch | Breite | Vias |
|---|---|---|---:|---:|---|
| 3,3 V | `+3V3` (PN5321) | ≤ 300 mA | 0,09 mm | **0,5 mm** | **1 × ⌀0,6 mm** |
| Antennentreiber | TX1/TX2 → Matching → Antenne | HF, ~200 mA | — | **≥ 0,8 mm**, symmetrisch | **keine**; unvermeidbar: 2 × ⌀0,6 mm parallel |
| Antennenschleife | — | HF | — | nach Antennenauslegung, typ. 0,5–1,5 mm | **keine** |
| Signale | SPI zum Stack, IRQ, RST | < 100 mA | < 0,05 mm | **0,25 mm** | **1 × ⌀0,3 mm** |
| GND | `GND` | — | — | Massefläche, **unter der Antenne ausgespart** | Stitching ⌀0,3 mm, nicht unter der Antenne |

- Kein Kupfer unter der Antennenschleife, auf beiden Lagen.
- TX1/TX2 symmetrisch und gleich lang, Matching dicht am PN5321, keine Vias
  im TX-Pfad.
- Antennenabstimmung gilt erst am vollständigen Stack — das MCU-Board sitzt
  direkt darunter.

### 3. Domänen und Abstände

Betrifft nur das I/O-Board; MCU- und RFID-Board liegen vollständig in SELV
(0,2 mm durchgehend). Vier Domänen:

- **NETZ** — alles vor/hinter dem Relais auf Netzpotential (beide Pole, PE).
  PE ist über die Y-Kondensatoren C309/C310 gewollt mit dem Steuerzweig
  gekoppelt; die Kondensatoren tragen als einzige Bauteile Netzpotential
  gegen PE und sind deshalb zwingend Y2-Klasse.
- **ISO-Insel** — `+3V3_ISO`, `GND_ISO`, `GND2_ISO`, die UART zur Seite 2
  von U300 und der Shunt-Sense. „ISO" heisst isoliert **gegen SELV**, nicht
  berührsicher: die Insel hängt über R300 am Lastpfad und bekommt deshalb
  keine SELV-Abstände. Einen eigenen Netzzweig führt sie nicht mehr —
  Versorgung und UART kommen über U300 aus der SELV-Seite.
  `GND2_ISO` ist der Rückweg des isolierten Wandlers, `GND_ISO` die
  Messreferenz am Shunt; ein Ferrit trennt beide innerhalb der Insel.
- **SELV** — 24 V / 5 V / 3,3 V / alle Logiksignale, Relaistreiber, gesamtes
  MCU- und RFID-Board.
- **FELD** — extern gespeiste Seite der Erweiterungsboards (NAMUR-Kanäle,
  Notaus-Schleife), galvanisch getrennt laut X2 und BR1.

Normbasis: IEC 60664-1, 250 V AC Arbeitsspannung, Überspannungskategorie II,
Verschmutzungsgrad 2 (zulässig, weil das IP64-Gehäuse staubdicht ist),
Werkstoffgruppe IIIa.

Abstandsmatrix (Luft- **und** Kriechstrecke, Designwerte):

| | NETZ gl. Pol | NETZ Gegenpol | ISO-Insel | SELV | FELD |
|---|---:|---:|---:|---:|---:|
| **NETZ gl. Pol** | 0,5 mm | 3,0 mm | 0,5 mm | 8,0 mm | 8,0 mm |
| **NETZ Gegenpol** | | 0,5 mm | 3,0 mm | 8,0 mm | 8,0 mm |
| **ISO-Insel** | | | 0,3 mm | 8,0 mm | 8,0 mm |
| **SELV** | | | | 0,2 mm | 2,0 mm |

- Die 8,0 mm liegen bewusst über der Norm (3,0 / 5,0 mm) und kommen von den
  Bauteilen: K300 8 mm / 9,5 mm / 4 kVrms, U300 (ISOW7721) > 8 mm Luft- und
  Kriechstrecke mit einem auf 8,1 mm ausgelegten Land Pattern. Nicht auf
  5 mm reduzieren.
- L300 trennt die beiden Wicklungen bauteilseitig nur über das Rastermaß
  von 4,0 mm ±0,5. Das erfüllt die 3,0 mm für NETZ Gegenpol, lässt aber
  wenig Spielraum — bei einem Typwechsel gegenprüfen.
- `GND_ISO` und `GND` sind getrennte Flächen; ihre gegenüberliegenden Kanten
  sind die längste Strecke der Barriere und brauchen einen definierten
  Umriss statt freier Füllung.
- Die ISO-Insel wird komplett von der Barriere umschlossen, auch wo auf ihr
  nur 3,3 V liegen.
- Netzkupfer inkl. ISO-Insel ≥ 2,0 mm zu Kante, Bohrungen, Fräsungen;
  SELV ≥ 0,5 mm.
- Lötstopplack, Bestückungsdruck und Schutzlack zählen nicht zur
  Kriechstrecke. Der Schutzlack würde erst nach einer Qualifizierung gemäß
  IEC 60664-3 anrechenbar; die ist hier nicht vorgesehen.
- Fräsnuten ≥ 1,0 mm breit, sonst bei Verschmutzungsgrad 2 als überbrückt
  gewertet.
- Keine Vias in der Barriere — die 8 mm gelten auf beiden Lagen.
- Die 8 mm gelten auch vertikal gegen die Unterseite des MCU-Boards:
  entweder Stackhöhe ≥ 8 mm oder Netzzone dort kupferfrei. Randbedingung für
  den Board-to-Board-Stecker.
- **Kein Kupfer im Umkreis von 4 mm um VISOOUT und GND2 von U300** (Vorgabe
  des Datenblatts, Bedingung für CISPR 32 Class B).
- `GND2_ISO` (Rückweg des Wandlers) und `GND_ISO` (Messreferenz) über einen
  Ferrit trennen, damit der getaktete Strom nicht über die Referenz des
  2-mΩ-Shunts läuft; `GND_ISO` in Kelvin-Anbindung hart am Shunt-Knoten.

## TODO

- RV300 liegt vor F300 und F302 und ist damit ungesichert. Ein Varistor am
  Lebensdauerende versagt niederohmig; vorgelagert wirkt nur der
  Leitungsschutzschalter im Werkstattverteiler. Thermisch geschützten
  Varistor (ThermoFuse) prüfen. Vorbestehend, nicht durch die Verlegung des
  EMV-Filters verursacht.
- **Auftrennbare Netzbrücken** an ausgewählten Stellen der Niederspannung
  vorsehen, damit sich Zweige zur Inbetriebnahme einzeln zuschalten lassen.
- **Testpunkte** für die Inbetriebnahme vorsehen. In der Netzdomäne und auf
  der ISO-Insel nur berührgeschützt zugänglich (U8, U9).

## FMEA

Betrachtet werden Einzelfehler, die nach aussen wirken — Brandgefahr,
Netzspannung auf berührbaren Teilen oder ein Schaltausgang, der sich nicht
mehr abschalten lässt. Reiner Funktionsverlust ohne Gefährdung ist nicht
aufgeführt.

| Bauteil | Fehlerart | Auswirkung ohne Maßnahme | Maßnahme |
|---|---|---|---|
| C309/C310 (Y2) | Kurzschluss | Netzspannung auf PE → FI löst aus, Gerät und Maschine sind freigeschaltet | Y2-Klasse: für Netz gegen PE zugelassen (IEC 60384-14) und bauartbedingt offen versagend. Keine berührbaren Teile betroffen, da PE geerdet ist |
| U300 (ISOW7721) | Isolationsdurchschlag | Netzpotential auf der SELV-Seite | verstärkte Isolierung (VDE 0884-17, 5 kVrms nach UL 1577) **und** 8 mm Barriere auf der Leiterplatte — zwei unabhängige Ebenen |
| Relaistreiber | ein Schalter durchlegiert | Relais dauerhaft angezogen, Firmware kann nicht mehr abschalten | **Zwei Schalter in Reihe in der Spule:** High-Side-PMOS (Q301) und Low-Side-NMOS (Q300), an getrennten GPIOs. Ein durchlegierter Schalter lässt sich über den anderen abschalten |
| Relaistreiber | beide Schalter durchlegiert | wie oben | Doppelfehler, nicht abgedeckt — Erkennung über die Lastmessung |
| K300 | Kontakt verschweisst | Schaltausgang bleibt aktiv | Lastmessung als Plausibilitätsprüfung: Strom bei kommandiertem AUS ist ein Fehler. Abschalten nicht möglich, siehe unten |
| Gate-Pulldown/Pull-up | offen | Gate floatet bei Reset/Boot, Relaiszustand undefiniert | Pulldown R316 an Q300 und R317 an Q302, Pull-up R313 an Q301, alle nahe am Gate; Prüfpunkt im Abnahmetest |

Die Erkennung über die Lastmessung funktioniert, weil R300 **vor** dem
Relais sitzt und in Reihe dazu liegt: bei offenem Relais fliesst kein Strom.
Ein gemessener Strom im Zustand AUS ist damit eindeutig ein Fehler.

Beim Treiber kann die Firmware darauf reagieren — sie öffnet den jeweils
anderen Schalter, und das Relais fällt ab. Beim verschweissten Kontakt kann
sie nur melden: K300 lässt sich dann nur extern freischalten. Ein zweites
Lastrelais in Reihe wäre die Lösung, ist aber auf 100x100 mm nicht
unterzubringen und steht zurück — wie der fehlende Hardware-Bypass am
E-Stop-Relais (BR3).

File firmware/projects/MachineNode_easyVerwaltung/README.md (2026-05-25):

# Machine Node — easyVerwaltung

ESP32-S3-Firmware für NFC-basierte Maschinenfreigabe mit easyVerwaltung-Backend-Integration.

> **Status: Geplant.** Basis ist `MachineNode_legacy` — Legacy-API wird durch den easyVerwaltung-Login-Contract ersetzt.

## Hardware

| Komponente | Detail |
|---|---|
| Mikrocontroller | ESP32-S3-WROOM-1-N16R8 (16 MB Flash) |
| NFC-Leser | Adafruit PN532 (SPI) |
| Ausgabe | Relais (Maschinenfreigabe), LEDs |
| Stromsensor (onboard) | Für kleine Lasten (z.B. 3D-Drucker) — direkt auf der Platine |
| Stromsensor (extern) | Interface für Remote-Sensor — für 400V-Geräte (Drehstrom) |

### Stromsensor-Varianten

Der Node erfasst Maschinenstunden über Strommessung. Je nach Maschinentyp kommt eine von zwei Varianten zum Einsatz:

- **Onboard** (kleine Lasten, 230V, z.B. 3D-Drucker): Stromsensor direkt auf der Platine integriert.
- **Extern** (400V-Geräte, Drehstrom): Steckbares Interface für einen externen Stromsensor (z.B. Stromwandler), der an der Maschine montiert wird und per Kabel zum Node führt.

## Funktion

Das Gerät liest NFC-Karten und fragt beim easyVerwaltung-Server an, ob der Nutzer die Maschine benutzen darf. Die Freigabe erfolgt über ein Relais. Zwei Betriebsmodi (pro Gerät zur Build-Zeit festgelegt):

- **Heartbeat-Modus** (`auth_permanent`): Karte muss dauerhaft aufliegen, Session wird periodisch verlängert.
- **Einmal-Modus** (`auth_onetime`): Einmalige Anmeldung, Maschine läuft bis zum manuellen Stop.

## Abgrenzung

Nachfolge von `MachineNode_legacy` (alte API). Im Unterschied zu `RFID_BOX_easyVerwaltung` verwendet der Machine Node einen **PN532-NFC-Leser** statt MFRC522 und läuft auf dem **ESP32-S3** statt dem klassischen ESP32.

## Konfiguration

Credentials kommen aus `platformio.secrets.ini` (nicht in Git):

```ini
[secrets]
wifi_ssid     = ...
wifi_password = ...
server_ip     = dashboard.intern
auth_token    = ...
```

## API

Kommuniziert über `shared/easyAPI` mit dem easyVerwaltung-Backend:

- `POST /api/service/health` — Startup-Check
- `POST /api/service/machine/login` — Kartenanmeldung
- `POST /api/service/machine/heartbeat` — Session-Verlängerung (nur `auth_permanent`)

## Abhängigkeiten

- `adafruit/Adafruit PN532`
- `thijse/ArduinoLog`
- `shared/easyAPI` (lokal, transport-agnostisch)

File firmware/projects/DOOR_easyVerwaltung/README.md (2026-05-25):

# DOOR — easyVerwaltung

Arduino-Firmware für RFID-gesteuerte Türverriegelung mit easyVerwaltung-Backend-Integration.

> **Status: In Entwicklung.** Basis ist `DOOR_legacy` — die Legacy-API wird durch den easyVerwaltung-Login-Contract ersetzt.

## Hardware

| Komponente | Detail |
|---|---|
| Mikrocontroller | Arduino UNO R4 WiFi |
| RFID-Leser | MFRC522 (SPI) |
| Antrieb | Schrittmotor via A4988/DRV8825 |
| Shift-Register | 74HC595 — LEDs, Buzzer, Motor-Enable |
| Sensoren | Reed-Kontakt, Endschalter |

## Konfiguration

Credentials kommen aus `platformio.secrets.ini` (nicht in Git):

```ini
[secrets]
wifi_ssid     = ...
wifi_password = ...
server_ip     = dashboard.intern
auth_token    = ...
```

## Flashen

```bash
# Erstmaliges Flashen per USB
pio run -e door_01_usb --target upload

# OTA (danach immer so, kein USB nötig)
pio run -e door_01_ota --target upload
```

OTA läuft via mDNS-Hostname `tuer-01.local`. Für Tür 02: `door_02_*`.

## Debugging

```bash
# Serial Monitor (USB, 115200 Baud)
pio device monitor -e door_01_usb
```

## API

Wird kommunizieren über `shared/easyAPI` mit:

- `POST /api/service/health`
- `POST /api/service/machine/login`
- `POST /api/service/machine/heartbeat`

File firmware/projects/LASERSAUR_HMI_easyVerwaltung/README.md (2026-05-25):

# LASERSAUR HMI — easyVerwaltung

Arduino-Firmware für das HMI-Board des Lasersaur-Laserplotters mit easyVerwaltung-Backend-Integration.

> **Status: In Entwicklung.** Basis ist `LASERSAUR_HMI_legacy` — Ethernet-Shield entfällt, WiFi (Giga R1 onboard), API wird auf den easyVerwaltung-Contract migriert.

## Hardware

| Komponente | Detail |
|---|---|
| Mikrocontroller | Arduino Giga R1 (onboard WiFi) |
| Temperatursensoren | MCP9808 (I2C, 4×) |
| Drucksensoren | MPL3115A2 (I2C) |
| Display | LCD 20×4 via I2C-Mux (LiquidCrystal_I2C) |
| Netzwerk | WiFi (onboard, kein Shield) |

## Abgrenzung

Dieses Projekt ist die Nachfolge von `LASERSAUR_HMI_legacy` (Mega + Ethernet-Shield, statische IP). Wesentliche Änderungen:

- Ethernet → WiFi (onboard Giga R1)
- Statische IP → DHCP + mDNS (`lasersaur-hmi.local`)
- Alte HTTP-POST-API → easyVerwaltung-Contract
- ArduinoJson v5 → v7

## Konfiguration

Credentials kommen aus `platformio.secrets.ini` (nicht in Git):

```ini
[secrets]
server_host   = dashboard.intern
service_token = ...
wifi_ssid     = ...
wifi_password = ...
```

Vorlage: `platformio.secrets.ini.example`

## Flashen

```bash
# Erstmaliges Flashen per USB
pio run -e lasersaur_hmi_usb --target upload

# OTA (danach immer so)
pio run -e lasersaur_hmi_ota --target upload
```

OTA läuft über mDNS-Hostname `lasersaur-hmi.local`.

## Debugging

```bash
pio device monitor -e lasersaur_hmi_usb   # Serial 115200 Baud
```

## Abhängigkeiten

- `adafruit/Adafruit MPL3115A2 Library`
- `adafruit/Adafruit MCP9808 Library`
- `marcoschwartz/LiquidCrystal_I2C`
- `bblanchon/ArduinoJson @ ^7`

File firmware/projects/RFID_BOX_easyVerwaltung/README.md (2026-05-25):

# RFID_BOX — easyVerwaltung

ESP32-Firmware für RFID-basierte Maschinenfreigabe mit easyVerwaltung-Backend-Integration.

## Hardware

| Komponente | Detail |
|---|---|
| Mikrocontroller | ESP32 Dev1 |
| RFID-Leser | MFRC522 (SPI) |
| Ausgabe | Relais (Maschinenfreigabe), 3 LEDs (rot/gelb/grün) |
| Eingabe | RFID-Karten-Button, Stop-Taster |

## Funktion

Das Gerät liest RFID-Karten und fragt beim easyVerwaltung-Server an, ob der Nutzer die Maschine benutzen darf. Die Freigabe erfolgt über ein Relais. Zwei Betriebsmodi:

- **Heartbeat-Modus** (`auth_permanent`): Karte muss dauerhaft aufliegen, Server wird alle N Sekunden (vom Server vorgegeben) erneut gefragt.
- **Einmal-Modus** (`auth_onetime`): Einmalige Anmeldung, danach läuft die Maschine bis zum manuellen Stop.

## Konfiguration

Credentials kommen aus `platformio.secrets.ini` (nicht in Git):

```ini
[secrets]
wifi_ssid     = ...
wifi_password = ...
server_ip     = dashboard.intern
auth_token    = ...
```

Maschinen-ID und -Name werden pro Environment in `platformio.ini` gesetzt.

## Flashen

```bash
# Erstmaliges Flashen per USB
pio run -e xtool_usb --target upload

# OTA-Update (kein USB nötig)
pio run -e xtool_ota --target upload
```

OTA läuft via mDNS-Hostname (z.B. `xtool-01.local`). Für andere Geräte: `<machine>_usb` / `<machine>_ota`.

## Debugging

```bash
# Serial Monitor (USB, 115200 Baud)
pio device monitor -e xtool_usb
```

Kein Telnet — Serial Monitor nur per USB.

## API

Kommuniziert über `shared/easyAPI` mit dem easyVerwaltung-Backend:

- `POST /api/service/health` — Startup-Check
- `POST /api/service/machine/login` — Kartenanmeldung
- `POST /api/service/machine/heartbeat` — Session-Verlängerung

## Abhängigkeiten

- `miguelbalboa/MFRC522`
- `thijse/ArduinoLog`
- `shared/easyAPI` (lokal, transport-agnostisch)

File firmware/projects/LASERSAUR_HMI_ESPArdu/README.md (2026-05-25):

# LASERSAUR_HMI_ESPArdu

Lasersaur HMI-Firmware für **Mega2560 WiFi R3** (ATmega2560 + ESP8266 auf einer Platine).

Architektur: **ATmega2560 = Gehirn** (Sensoren, Display, Relais, Fehlerlogik), **ESP8266 = WiFi-Modem** (HTTP POST, Telnet-Debug, OTA).

Portierung von `LASERSAUR_HMI_legacy` (Mega2560 + Ethernet-Shield).

---

## Hardware

- **Board:** Mega2560 WiFi R3 (ATmega2560 + ESP8266, USB-TTL CH340)
- **Schalter 2** muss einmalig physisch auf **RXD3/TXD3** gestellt werden  
  → verbindet ESP8266 mit ATmega Serial3 (Pins 14/15) statt Serial0

## DIP-Schalter

| Modus | 1 | 2 | 3 | 4 | 5 | 6 | 7 |
|---|---|---|---|---|---|---|---|
| **Normalbetrieb** | EIN | EIN | EIN | EIN | AUS | AUS | AUS |
| ATmega flashen | AUS | AUS | EIN | EIN | AUS | AUS | AUS |
| ESP flashen | AUS | AUS | AUS | AUS | EIN | EIN | EIN |

Im Normalbetrieb: Serial0 → USB-Debug, Serial3 → ESP — kein Konflikt.

---

## Einrichtung

**1. Secrets anlegen (nicht in Git):**

```bash
cp include/secret.h.example include/secret.h
cp platformio.secrets.ini.example platformio.secrets.ini
```

`include/secret.h` → WiFi-SSID und Passwort eintragen  
`platformio.secrets.ini` → Server-Host und Auth-Token eintragen

**2. ATmega flashen** (DIP 3+4 ON):
```bash
pio run -e laser_hmi_atmega_usb --target upload
```

**3. ESP flashen** (DIP 5+6+7 ON, einmalig):
```bash
pio run -e laser_hmi_esp_usb --target upload
```

**4. DIP auf Normalbetrieb** (1+2+3+4 ON)

**ESP danach per OTA updaten** (kein DIP-Wechsel nötig):
```bash
pio run -e laser_hmi_esp_ota --target upload
```

---

## Debugging

- **ATmega:** Serial Monitor 115200 Baud (`pio device monitor -e laser_hmi_atmega_usb`)
- **ESP:** Telnet auf `laser-hmi.local` Port 23 (`pio device monitor -e laser_hmi_esp_ota`)

---

## Protokoll ATmega ↔ ESP (Serial3, 9600 Baud)

| Richtung | Nachricht | Bedeutung |
|---|---|---|
| ATmega → ESP | `POST:{json}\n` | HTTP POST ausführen |
| ATmega → ESP | `PONG\n` | Heartbeat-Antwort |
| ESP → ATmega | `ACK:200\n` | POST erfolgreich |
| ESP → ATmega | `NACK:WIFI\n` | Kein WiFi |
| ESP → ATmega | `NACK:503\n` | Server nicht erreichbar |
| ESP → ATmega | `NACK:TIMEOUT\n` | Keine Antwort vom Server |
| ESP → ATmega | `PING\n` | Heartbeat (alle 5 s) |

---

## Pin-Mapping ATmega2560

| Pin | Signal | Richtung |
|-----|---|---|
| 2 | Kompressor-Relais | Output |
| 3 | Treiber-Relais | Output |
| 4 | Kompressor-Taster | Input |
| 5 | Abluft-Sensor | Input |
| 6 | Switch Enable | Output |
| 7 | Wasserpfad Enable | Output |
| 8 | Wasserfluss RPM (ICP) | Input |
| 9 | RFID Enable | Input |
| 13 | Status-LED (OnBoard) | Output |
| 14/15 | Serial3 → ESP8266 | UART |
| 20/21 | I2C (SDA/SCL) | I2C |
| 62 (A8) | EEPROM Reset | Input |
| A1 | Wassertemperatur After | ADC |
| A2 | Wassertemperatur Before | ADC |
| A3 | Linsentemperatur | ADC |

**I2C-Mux TCA9548A (0x70):**

| Kanal | Gerät |
|---|---|
| 0 | MPL3115A2 Drucksensor 1 |
| 1 | MPL3115A2 Drucksensor 2 |
| 2 | MCP9808 Temp CH2 |
| 3 | MCP9808 Temp CH1 |
| 4 | MPL3115A2 Drucksensor 3 |
| 5 | MPL3115A2 Drucksensor 4 |
| 6 | MCP9808 Temp CH3 + CH4 |
| 7 | LCD 20×4 (0x27) |

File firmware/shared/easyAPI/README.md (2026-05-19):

# easyAPI

`shared/easyAPI` is a small embedded C library for backend communication from firmware projects. It is intended for Pico SDK-style CMake builds and remains transport-agnostic so the core request construction, JSON parsing, validation, and error mapping can be tested on a host without physical hardware.

The current API targets the easyVerwaltung machine-service contract:

- `POST /api/service/health?serviceId=...`
- `POST /api/service/machine/login`
- `POST /api/service/machine/heartbeat`

The library does not own Wi-Fi, TLS, sockets, Pico SDK initialization, RFID reading, relays, UI, logging, or local session scheduling. Those are application responsibilities.

## Public API

Public declarations live in `include/easy_api.h`.

Main types:

- `easy_api_client_t`: configured client instance.
- `easy_api_config_t`: explicit configuration for base URL, service ID, service token, timeouts, buffers, and transport callback.
- `easy_api_transport_fn`: platform callback used to execute HTTP requests.
- `easy_api_status_t`: enum-based status model.
- `easy_api_health_response_t`, `easy_api_login_response_t`, `easy_api_heartbeat_response_t`: parsed response objects.

Main functions:

- `easy_api_init(...)`
- `easy_api_health_check(...)`
- `easy_api_machine_login(...)`
- `easy_api_machine_heartbeat(...)`
- `easy_api_status_string(...)`
- `easy_api_mode_string(...)`

All public functions validate arguments. Network calls are blocking and must be bounded by `easy_api_config_t.timeout_ms`; the transport implementation is responsible for enforcing that timeout.

## Configuration

Example configuration:

```c
static char request_buffer[512];
static char response_buffer[1024];

static easy_api_status_t pico_transport(
    const easy_api_http_request_t *request,
    easy_api_http_response_t *response,
    void *user_context);

static easy_api_client_t client;

void backend_init(void) {
    easy_api_config_t config = {
        .base_url = "https://verwaltung.example.org",
        .service_id = "svc_laser_cutter_01",
        .service_token = service_token_from_secret_store,
        .timeout_ms = 5000u,
        .request_buffer = request_buffer,
        .request_buffer_size = sizeof(request_buffer),
        .response_buffer = response_buffer,
        .response_buffer_size = sizeof(response_buffer),
        .transport = pico_transport,
        .transport_context = NULL,
    };

    (void)easy_api_init(&client, &config);
}
```

Keep `service_token` secret. Do not log it. Do not log raw RFID values. Do not place tokens in URLs.

## Transport boundary

The transport callback receives a complete HTTP request description:

- method, currently `POST`
- URL
- headers, including `X-Service-Token`, `Content-Type`, and `Accept`
- JSON body and body length
- timeout in milliseconds

The callback fills:

- `response->http_status`
- `response->body`
- `response->body_len`

Return `EASY_API_ERR_TIMEOUT` for timeout, `EASY_API_ERR_NETWORK` for network/TLS failures, and `EASY_API_ERR_BUFFER_TOO_SMALL` if the response buffer cannot hold the body.

This keeps Pico SDK, lwIP, TLS, Arduino HTTP clients, or any other network implementation outside the reusable core.

## Pico SDK integration

From a Pico SDK CMake project, add the module and link it:

```cmake
add_subdirectory(${CMAKE_CURRENT_LIST_DIR}/../../shared/easyAPI easyAPI_build)

target_link_libraries(my_firmware_target
    PRIVATE
        easyAPI::easyAPI
        pico_stdlib
        pico_cyw43_arch_lwip_threadsafe_background
)
```

Only the application transport should link Pico networking libraries. `easyAPI` itself links no Pico SDK libraries.

## Examples

Example programs live under `examples/` and use mocked transports, so they can run on a host without Pico hardware. They demonstrate API usage only. Real firmware still owns Wi-Fi, TLS, RFID, relays, display, and scheduling. Shared demo values are defined in `examples/easy_api_example_config.h`:

```c
#define EASY_API_EXAMPLE_SERVICE_TOKEN "demo-service-token-aa00"
#define EASY_API_EXAMPLE_SERVICE_ID    "svc_inst_001"
#define EASY_API_EXAMPLE_RFID          "CARD-1001"
#define EASY_API_EXAMPLE_PIN           "1234"
```

The demo token, RFID, and PIN are intentionally hard-coded only in examples. Production firmware must load them from protected runtime configuration and must not log raw token or RFID values.

| Example | Purpose |
| --- | --- |
| `basic_health_check` | Startup presence check against `/api/service/health`. |
| `login_single_mode` | One-shot authorization flow with optional PIN. |
| `login_heartbeat_mode` | Login plus repeated heartbeat calls using backend-owned session data. |
| `full_machine_flow` | Minimal fail-closed state-machine example for an embedded machine controller. |
| `service_layer_mocked_flow` | Non-blocking service-layer login flow with a mocked executor. |

Build examples on a host:

```bash
cd firmware/shared/easyAPI
cmake -S . -B build-examples -DEASY_API_BUILD_EXAMPLES=ON
cmake --build build-examples
./build-examples/easyAPI_example_basic_health_check
./build-examples/easyAPI_example_login_single_mode
./build-examples/easyAPI_example_login_heartbeat_mode
./build-examples/easyAPI_example_full_machine_flow
./build-examples/easyAPI_example_service_layer_mocked_flow
```

Typical heartbeat login usage:

```c
easy_api_login_response_t login;
easy_api_status_t status = easy_api_machine_login(
    &client,
    EASY_API_EXAMPLE_RFID,
    EASY_API_MODE_HEARTBEAT,
    EASY_API_EXAMPLE_PIN,
    &login);

if (status == EASY_API_OK && login.authorized) {
    // Store login.session_id only in volatile local session state.
    // Schedule the next heartbeat using login.heartbeat_interval_seconds.
} else {
    // Fail closed. Do not start local machine access.
}
```

Heartbeat:

```c
easy_api_heartbeat_response_t heartbeat;
easy_api_status_t status = easy_api_machine_heartbeat(
    &client,
    session_id,
    current_rfid,
    &heartbeat);

if (status != EASY_API_OK) {
    // End local access and clear volatile session state.
}
```

## Build

Host build of the module:

```bash
cd firmware/shared/easyAPI
cmake -S . -B build
cmake --build build
```

## Tests

The tests are host-based and use a mocked transport. They do not require Pico hardware.

```bash
cd firmware/shared/easyAPI
cmake -S . -B build-tests -DEASY_API_BUILD_TESTS=ON
cmake --build build-tests
ctest --test-dir build-tests --output-on-failure
```

Covered scenarios include:

- health check success and inactive service
- authorized single login
- authorized heartbeat login
- denied login
- heartbeat accepted and rejected
- invalid arguments
- timeout and network errors
- HTTP error envelope parsing
- malformed or incomplete JSON
- request-buffer-too-small handling
- JSON string escaping

## Coverage

With GCC or Clang and `gcov`/`lcov` installed:

```bash
cd firmware/shared/easyAPI
cmake -S . -B build-coverage -DEASY_API_BUILD_TESTS=ON -DEASY_API_ENABLE_COVERAGE=ON -DCMAKE_BUILD_TYPE=Debug
cmake --build build-coverage
ctest --test-dir build-coverage --output-on-failure
lcov --capture --directory build-coverage --output-file build-coverage/coverage.info
lcov --remove build-coverage/coverage.info '*/tests/*' --output-file build-coverage/coverage.filtered.info
genhtml build-coverage/coverage.filtered.info --output-directory build-coverage/html
```

A simpler line-coverage check with `gcovr`:

```bash
gcovr -r . build-coverage --filter 'src/easy_api.c' --html --html-details -o build-coverage/coverage.html
```

The included tests are designed to exceed 90% line coverage for `src/easy_api.c` when run with standard GCC/Clang coverage tooling.

## Error model

`easy_api_status_t` contains:

- `EASY_API_OK`
- `EASY_API_ERR_INVALID_ARG`
- `EASY_API_ERR_TIMEOUT`
- `EASY_API_ERR_NETWORK`
- `EASY_API_ERR_HTTP_STATUS`
- `EASY_API_ERR_JSON_PARSE`
- `EASY_API_ERR_BUFFER_TOO_SMALL`
- `EASY_API_ERR_BACKEND_DENIED`
- `EASY_API_ERR_SERVICE_INACTIVE`

For non-2xx backend responses, the parsed backend error code, correlation ID, and HTTP status are stored in the response error object when present.

## Assumptions and limitations

- `easyAPI` implements the machine-service contract documented for easyVerwaltung service endpoints.
- The transport callback enforces the configured timeout.
- The library intentionally uses a small bounded parser for the known backend response fields instead of adding a JSON dependency to the reusable core.
- The parser is not a general-purpose JSON parser.
- URL encoding for `serviceId` in the health query is not implemented; use service IDs that are already URL-safe.
- TLS certificate validation, DNS, Wi-Fi state, retry/backoff policy, token rotation, and local fail-closed hardware control belong to the firmware application layer.
- Heartbeat scheduling and local session state are intentionally not hidden inside the library.

## Non-blocking Service Layer

`easy_api_service` is an optional job/event layer above the blocking easyAPI core. It is intended for firmware that has UI, RFID readers, displays, relays, watchdogs, or other work that must continue while backend communication is in progress.

The service layer itself does not open sockets or perform HTTP. Instead, it owns:

- queued job state
- bounded request copies
- deadline and timeout handling
- cancellation
- event mapping
- fail-closed result propagation

The application provides a non-blocking executor through three callbacks:

```c
easy_api_service_executor_start_fn executor_start;
easy_api_service_executor_poll_fn  executor_poll;
easy_api_service_executor_cancel_fn executor_cancel;
```

Typical executor implementations:

- RTOS worker task wrapping the blocking `easy_api_*` calls
- cooperative non-blocking HTTP transport
- host-side mock executor for tests and simulation

Do not call the blocking easyAPI core directly from UI code or from interrupt handlers. Interrupt handlers should only enqueue local events, set flags, or wake a task.

### Service Layer State Model

```text
IDLE -> QUEUED -> RUNNING -> IDLE
              \-> CANCELLING -> IDLE
```

`easy_api_service_poll()` is designed to be called from the main loop:

```c
while (1) {
    ui_update();
    rfid_update();
    machine_update();
    easy_api_service_poll(&api_service);
}
```

When a job completes, times out, fails, or is cancelled, the configured event callback receives one of:

- `EASY_API_SERVICE_EVENT_HEALTH_OK`
- `EASY_API_SERVICE_EVENT_HEALTH_FAILED`
- `EASY_API_SERVICE_EVENT_LOGIN_GRANTED`
- `EASY_API_SERVICE_EVENT_LOGIN_DENIED`
- `EASY_API_SERVICE_EVENT_HEARTBEAT_OK`
- `EASY_API_SERVICE_EVENT_HEARTBEAT_REJECTED`
- `EASY_API_SERVICE_EVENT_TIMEOUT`
- `EASY_API_SERVICE_EVENT_CANCELLED`
- `EASY_API_SERVICE_EVENT_ERROR`

### Service Layer Example

See:

```text
examples/service_layer_mocked_flow/main.c
```

This example demonstrates a non-blocking login flow with a mocked executor. In a Pico/RTOS application, replace the mock executor with a worker task or cooperative transport implementation.

### Important Limitation

The service layer can only be non-blocking if the configured executor is non-blocking. A blocking executor will still block during `executor_start()` or `executor_poll()`.

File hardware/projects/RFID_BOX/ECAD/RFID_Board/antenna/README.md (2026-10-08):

# Antennen-Footprints RFID-Board

Kandidaten für die 13,56-MHz-Leseschleife, erzeugt mit
[KiCoil](https://jaseg.de/projects/kicoil). `./generate.sh` baut alle vier neu.

## Varianten

Alle mit denselben Wicklungsparametern: **3 Windungen, 1,0 mm Leiterbreite,
0,5 mm Abstand, einlagig, 3 mm Keepout-Rand**.

| Footprint | Kontur | Induktivität |
|---|---|---:|
| `NFC_Loop_78x78_3T` | Rechteck 78 × 78, scharfe Ecken | 1,175 µH |
| `NFC_Loop_rr` | Rechteck 78 × 78, Eckradius 12 | 1,134 µH |
| `NFC_Loop_el` | Ellipse 78 × 58 | 0,756 µH |
| `NFC_Loop_st` | Racetrack 78 × 48 | 0,579 µH |

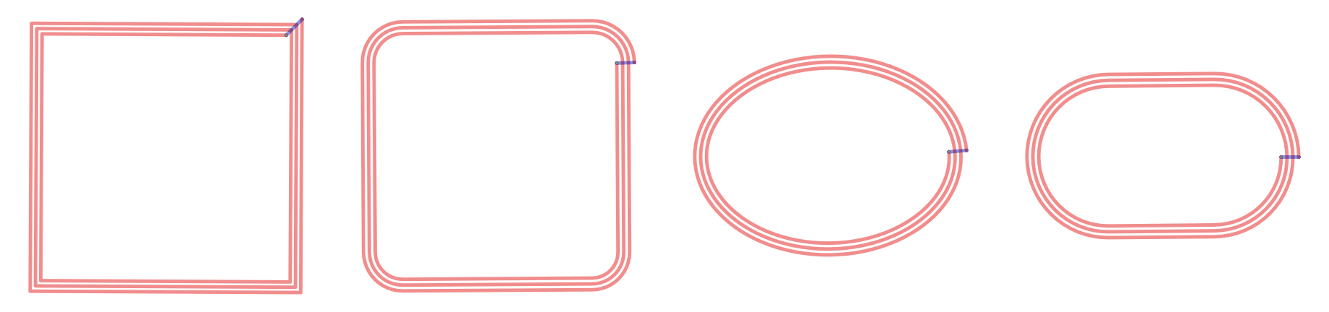
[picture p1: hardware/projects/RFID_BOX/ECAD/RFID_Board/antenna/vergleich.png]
Vergleich


Die Induktivität rechnet KiCoil selbst und schreibt sie in die
Footprint-Beschreibung. Alle vier liegen im brauchbaren Fenster für den
PN5321 (etwa 0,5 bis 3 µH). Es sind Rechenwerte — sie gelten für die freie
Platine, nicht für den fertigen Stack.

Das Außenmaß von 78 mm folgt der Karte, nicht dem Gehäuse: eine ID-1-Karte
(85,6 × 54 mm) trägt ihre Spule rund 78 × 46 mm innerhalb des Kartenrands.

## Anschlüsse

Jeder Footprint hat drei Pads:

| Pad | Art | Bedeutung |
|---|---|---|
| `1` | SMD auf F.Cu | äußeres Ende der Schleife |
| `2` | SMD auf B.Cu, **gleiche Koordinate wie Pad 1** | inneres Ende, über die Rückseite herausgeführt |
| `NC` | Durchkontaktierung | Übergang der innersten Windung auf die Rückseite |

Die Spirale läuft auf F.Cu von außen nach innen, fällt über die
Durchkontaktierung auf B.Cu und kehrt dort auf kurzem, schrägem Weg zum
Einspeisepunkt zurück. Dieser Rückweg ist das einzige Kupfer unter der
Schleife und quert die äußeren Windungen rechtwinklig.

Für das Matching heißt das: ein Zweig kommt von vorn an Pad 1, der andere von
hinten an Pad 2. Beide liegen übereinander in derselben Ecke.

## Was das Werkzeug nicht kann

KiCoils SVG-Import liest nur das erste `<path>` und versteht darin
ausschließlich `M x y L x y … Z` — keine Bögen, keine `H`/`V`-Kurzformen,
keine Kommas als Koordinatentrenner. Runde Konturen müssen vorher in
Strecken aufgelöst werden; das macht `shape_svg.py` mit einer Pfeilhöhe von
0,03 mm. `rounded-rect`, `ellipse` und `stadium` sind dort angelegt, weitere
Konturen kommen als Funktion dazu.

Die Warnung „Polygon looks not centered" beim Lauf ist ein Fehler in KiCoils
Prüfung der Bounding-Box (sie vergleicht x- mit y-Grenzen). Der berechnete
Schwerpunkt ist (0, 0), es wird nichts verschoben.

## Umgebung

KiCoil fordert Python ≥ 3.13; KiCads mitgelieferter Interpreter ist 3.9.
`generate.sh` legt deshalb beim ersten Aufruf eine eigene Umgebung unter
`~/.cache/kicoil-venv` an. Das Plugin in KiCad bleibt davon unberührt — es
erscheint erst, wenn der API-Interpreter in den Einstellungen auf
`/opt/homebrew/bin/python3.13` zeigt.

## Offen

- Abstimmung gilt erst am vollständigen Stack: das MCU-Board unter der
  Antenne verstimmt sie und entzieht ihr Energie.
- Matching nach NXP AN1445 aus gemessenem L und R, nicht aus diesen
  Rechenwerten.
- Kondensatoren als bestückbare Bank vorsehen, damit nach der ersten Messung
  umbestückt statt neu gefertigt wird.

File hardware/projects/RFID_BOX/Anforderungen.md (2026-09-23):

# Machine Node / RFID_BOX – Anforderungen

**Dokumentrevision: 1.8**

Arbeitsplanung für den kompakten Machine Node. Dieses Dokument ist die
Anforderungsbasis, aus der Schaltplan, PCB-Stack, Gehäuse und erste
Bestellung abgeleitet werden. Die konkrete technische Auslegung
(Architekturentscheidung, Blockdiagramm, Teileliste, Schnittstellen,
Layout-Regeln, Firmware-Zustände, Abnahmetests) steht in
[README.md](README.md).

## Changelog

- **1.8** – **Gerätesicherung F1 von 1 A auf 500 mA träge** reduziert. Das
  EMV-Filter sitzt jetzt im Steuerzweig statt am Netzeingang; F1 ist auf
  die dortige Gleichtaktdrossel gestaffelt, die bei 60 °C 0,87 A trägt.
  Ausserdem ist das SMD-Zielbild aufgeweicht: THT wird eingesetzt, wo die
  Bauteile es erfordern.
- **1.7** – **Die beiden Bestückvarianten des I/O-Boards werden zu zwei
  getrennten Boards** mit eigenem Layout: **I/O-Board 230V** und
  **I/O-Board 24V**. Das gemeinsame PCB ist nicht mehr haltbar — der
  8-A-Lastpfad und die 8-mm-Isolationsbarriere lassen auf 100x100 mm keinen
  Platz für einen zweiten, im jeweiligen Gerät ungenutzten Schaltpfad. Als
  eigenes Board kommt das I/O-Board 24V ohne Lastpfad, Lastmessung und
  Messnetzteil aus, spart rund 33 € Bauteile und braucht statt 70 µm nur
  35 µm Kupfer. Formfaktor und Board-to-Board-Stecker bleiben bei beiden
  identisch, damit der Rest des Stacks unverändert bleibt.
- **1.6** – **U8 (Berührschutz im geöffneten Gerät)** und **U9
  (Schutzlack)** ergänzt. Das Gerät wird im Servicefall geöffnet, während es
  noch am Netz hängen kann; feste Abdeckplatten über dem I/O-Board geben nur
  die berührsicheren Feldterminals und den Sicherungshalter frei. Dass MCU-
  und RFID-Board kein 230 V führen, ist damit eine bindende Randbedingung
  und keine Momentaufnahme mehr. Der Schutzlack stützt den IP-Schutz
  langfristig, wird aber ausdrücklich nicht auf Kriech- und Luftstrecken
  angerechnet (dafür wäre eine Qualifizierung nach IEC 60664-3 nötig).
- **1.5** – Vier Korrekturen am I/O-Board, entstanden beim Durchrechnen von
  Thermik und Isolationsbarriere für die Layout-Regeln (neues Kapitel
  „Leiterbahnbreiten und Abstände" in [README.md](README.md)). **NTC zur
  Einschaltstrombegrenzung (RT300) entfällt ersatzlos:** er lag dauerhaft im
  8-A-Lastpfad, setzte dort rund 3 W um und wurde damit zum heissesten
  Bauteil im unbelüfteten IP64-Gehäuse; begrenzt hätte er ohnehin nur kalt,
  beim schnellen Wiedereinschalten also praktisch nicht. Den Anlauf tragen
  die träge F300 und das Einschaltvermögen von K300 (30 A, AgCdO).
  **Lastmessung sitzt jetzt vor dem Relais** statt dahinter, damit sie
  unabhängig vom Schaltzustand versorgt bleibt und `LAST_AUS` gemessen statt
  aus dem Relaiszustand gefolgert wird. **Versorgung der Messinsel auf ein
  netzseitiges Kondensatornetzteil umgestellt:** die isolierten Regler U302
  (RFB-0505S) und U300 entfallen. Der RFB-0505S war mit 500 VAC nur
  funktional isoliert und damit das schwächste Glied einer sonst verstärkt
  isolierten Barriere; verstärkt isolierte 1-W-Module kosten ~16 € gegen
  ~1,50 € für das Kondensatornetzteil. **Optokoppler U304 entfällt:** die
  Relaisspule hängt an der 24-V-Schiene aus dem isolierten IRM-10-24, liegt
  also auf SELV — U304 hätte zwei SELV-Domänen getrennt. Der Relaistreiber
  wird ein Logic-Level-NMOS mit Gate-Pulldown (E2: Ausgang nach Reset AUS).
  Über die Isolationsbarriere quert damit nur noch U305.
- **1.4** – I/O-Board-Footprint auf 100x100mm optimiert: AC/AC-Trafo
  (14A-10R-24) + Gleichrichter (RTT410-13) + DC/DC-Wandler (REC6K-2424SAW)
  durch ein isoliertes AC/DC-Modul (Mean Well IRM-10-24, 10W, 4,2kVac
  I/P-O/P) ersetzt. Lastrelais Q1 von Finder 62.22 (49mm hoch, einpolig)
  auf TE Connectivity T92S11D12-24 (30,7mm hoch, 2-polig N+L) gewechselt —
  adressiert zusätzlich die nicht garantiert eindeutige N/L-Zuordnung an
  der Werkstatt-Steckdose. **S5 präzisiert:** Nur noch die
  Lastausgangssicherung F2 ist gesockelt gefordert; die Gerätesicherung F1
  (1A) ist als dokumentierte Ausnahme fest verlötet, abgesichert durch den
  vorgelagerten Leitungsschutzschalter im Werkstattverteiler. F3
  (Sekundärsicherung 24VAC) entfällt komplett, da die Trafo-Sekundärseite
  mit dem neuen AC/DC-Modul wegfällt.
- **1.3** – E4 und BR1 von 24 V DC / 1 A auf **24 V DC / 100 mA**
  reduziert: Die tatsächlich benötigte Kontaktbelastung des potentialfreien
  Ausgangs (K2) und des E-Stop-Relais (K3) liegt bei ca. 100 mA (Ansteuerung
  eines externen Schütz- bzw. Relais-Steuereingangs, keine direkte
  Leistungslast). Die Bauteilauswahl (Relaiswahl, Polyfuse-Dimensionierung)
  ist entsprechend auf 100 mA statt 1 A ausgelegt. Gehäusebeschriftung
  entsprechend angepasst. **BR3 präzisiert:** Das E-Stop-Relais öffnet
  sofort und unabhängig von der konfigurierten Nachlaufzeit, aber über den
  ESP32 — es gibt aktuell keinen zusätzlichen, von der Firmware
  unabhängigen Hardware-Bypass. Eine echte hardwareseitige (z.B.
  latchende) Lösung wäre für ein noch höheres Sicherheitsniveau denkbar,
  ist aber mit vertretbarem Aufwand aktuell nicht umsetzbar und daher
  bewusst zurückgestellt.
- **1.2** – I4 (Lastmessung) von optional auf Standard bei der Variante 230V
  umgestellt, auf Basis von Team-Feedback zur Revision 1.1: schafft die
  Grundlage für spätere nutzungsbasierte Abrechnung/Limits, macht den
  tatsächlichen Verbrauch nachvollziehbar und hilft bei der Dimensionierung
  neuer Standorte.
- **1.1** – Boards auf MCU/I/O/RFID umbenannt, UI-Peripherie (OLED, LED-Ring,
  Summer, Stopp-Taster) vom RFID- auf das MCU-Board verlagert; I/O-Board in
  zwei exklusive Bestückvarianten (230V-Direktschaltung / potentialfrei 24V
  für externes Schütz) aufgeteilt; NAMUR-I/O als Bestückvariante eines neuen,
  generischen Extension Boards ausgelagert; Sicherungen auf gesockelte,
  werkzeuglos tauschbare Bauform umgestellt. Neues, eigenständiges **E-Stop
  Extension Board** (optional) ergänzt: einfaches Relais zur Bremsversorgung
  für Maschinen, deren Bremse dauerhaft Strom zum Lösen braucht
  (power-to-release, fail-safe stromlos = Bremse aktiv); trotz des Namens
  kein zertifiziertes Not-Aus-/Not-Halt-Bauteil und unabhängig vom
  generischen Extension Board (NAMUR/Digital-I/O). Q1 (Bestückvariante 230V)
  als elektromechanisches **Relais** festgelegt statt SMD-Schalter. Neues
  Übersichts-Blockdiagramm am Anfang von "Anforderungen aus Blackbox-Sicht"
  ergänzt (Boards mit groben Inhalten, gestrichelte Linien zu den optionalen
  Erweiterungsboards). Zielschutzart von IP34 auf **IP64** angehoben: Gehäuse
  muss staubdicht sein (nicht nur Schutz gegen Fremdkörper ab 2,5 mm), da der
  Einsatzort eine Holzwerkstatt mit Sägemehl ist; U6 präzisiert, dass der
  Kartenkanal mechanisch vom staubdichten Innenraum getrennt ist (RFID-
  Erkennung ist berührungslos) und eindringender Staub nach unten ausgeführt
  statt in den Elektronikraum geleitet wird. Ausserdem "beide FKS" auf "FKS"
  korrigiert, da nur eine Maschine dieses Typs vorhanden ist. **Sicherheits-
  relevante Korrektur der Stopp-Reihenfolge:** Das E-Stop Extension Board
  (K3) unterbricht bei Stopp/Kartenentzug immer sofort die Notaus-/
  Interlock-Schleife der Maschine, unabhängig vom Nachlaufprofil — die
  Hauptversorgung (Q1/K2 auf dem I/O-Board) wird dagegen **nie** hart und
  sofort getrennt, sondern immer erst nach Ablauf der konfigurierten
  Nachlaufzeit abgeschaltet, auch nicht durch den Stopp-Taster. Die vorherige
  Fassung beschrieb das genau umgekehrt (harter Stopp-Taster öffnet die
  Versorgung sofort); dieses Verhalten hat in der Praxis bereits zu einem
  Maschinenschaden geführt, weil der Maschine dann die Energie für ihre
  eigene kontrollierte Bremsung fehlte. E6, B3, B7, Nachlaufprofile, BR2/BR3,
  Blockdiagramm, Teileliste, Layout-Regeln, Schnittstellentabelle und
  Abnahmetests (T3, T20, T21) entsprechend korrigiert. K3-Relais des E-Stop
  Extension Boards mit **24 V DC / 1 A** Kontaktbelastung spezifiziert.
  Programmierweg präzisiert: laufende Firmware-Updates primär per OTA über
  WLAN, der interne USB-C-Anschluss J4 dient nur der Erstprogrammierung und
  dem Debug/Service.
- **1.0** – Erste Fassung: kompakter Machine Node mit PCB-A (Controller),
  PCB-B (Power, inkl. 230V-Ausgang, potentialfreiem Kontakt und NAMUR-I/O)
  und PCB-C (RFID/UI) als gemeinsamem Stack.

## Ziel

Eine kompakte Box aus einem bis drei direkt übereinander montierten PCBs
(plus optionalen Erweiterungsboards), die eine Maschine per RFID freischaltet
und den Zustand der Last an die easyVerwaltung meldet.

- RFID-Anmeldung am PN532
- WLAN-Kommunikation; Firmware-Programmierung primär per OTA über WLAN, nur
  die Erstprogrammierung erfolgt über den internen USB-C-Anschluss (J4)
- sichere Freigabe einer 230-V-Last oder eines potentialfreien 24-V-Signals
  für ein externes Schütz
- Erkennung, ob die Maschine tatsächlich läuft
- definierter Aus-Zustand bei Reset oder Firmware-Fehler; Verhalten bei
  Kommunikationsverlust ist pro Maschinenprofil festgelegt
- möglichst weitgehend SMD-bestückte Funktionsboards, damit eine externe
  Bestückung einfach bleibt; THT wird dort eingesetzt, wo es die Bauteile
  erfordern
- keine interne Handverkabelung und keine handverlöteten Module
- einheitliche Board-to-Board-Stecker zwischen den Boards
- gemeinsamer Grundaufbau (I/O-Board) für zwei exklusive Schaltvarianten
  sowie ein optionales, generisches Extension Board für zusätzliche I/O

## Anforderungen aus Blackbox-Sicht

Die folgenden Anforderungen beschreiben das Verhalten und die Eigenschaften
des fertigen Geräts. Interne PCB-Aufteilung und konkrete Bauteile sind keine
Anforderungen, sondern daraus abgeleitete Designentscheidungen. Zur groben
Orientierung vorab die Boards, auf die sich die Anforderungen unten beziehen:

```mermaid
flowchart LR
    IO["I/O-Board<br/>Netzeingang, Sicherungen,<br/>230V-Relais 8A/1,84kW<br/>ODER<br/>potentialfreier Kontakt 24V 100mA"]
    MCU["MCU-Board<br/>ESP32-S3, OLED, LED-Ring,<br/>Stopp-Taster, Summer"]
    RFID["RFID-Board<br/>PN532, Antenne"]
    EXT["Extension Board (optional)<br/>NAMUR-<br/>ODER<br/>I/O-Board (3V3)"]
    ESTOP["E-Stop Extension Board (optional)"]

    IO --- MCU
    MCU --- RFID
    IO -.- EXT
    IO -.- ESTOP
```

### 1. Energie und Schalten

Es gibt **zwei getrennte I/O-Boards** mit eigenem Layout: das **I/O-Board
230V** mit Lastrelais und Lastmessung und das **I/O-Board 24V** mit
potentialfreiem Kontakt für ein externes Schütz. Pro Gerät ist genau eines
bestückt. Beide haben denselben Formfaktor, denselben Board-to-Board-Stecker
zum MCU-Board und dieselbe Versorgung aus dem Netz-Eingang; alles ab dem
Schaltpfad unterscheidet sich.

Frühere Fassungen sahen ein gemeinsames PCB mit zwei Bestückvarianten vor.
Das ist aufgegeben: der 8-A-Lastpfad und die 8-mm-Isolationsbarriere lassen
auf 100x100 mm keinen Platz für einen zweiten, ungenutzten Schaltpfad. Als
getrenntes Board kommt das I/O-Board 24V ohne Lastpfad, Lastmessung und
Messnetzteil aus, spart rund 33 € Bauteile und braucht keine 70 µm Kupfer.

| ID | Muss-Anforderung | Abnahmekriterium |
|---|---|---|
| E1 | Das Gerät wird mit 230 V AC versorgt. | Das Gerät hat einen eindeutig beschrifteten Netz-Eingang und startet nach dem Einschalten definiert. Gilt für beide I/O-Boards, auch wenn nur das I/O-Board 230V die Netzspannung weiterschaltet. |
| E2 | **I/O-Board 230V:** Das Gerät schaltet einen 230-V-Ausgang aus derselben Versorgung. | Nach Start, Reset und Fehlerzustand ist der Ausgang AUS. Bei Kommunikationsverlust gilt das konfigurierte Maschinenprofil. |
| E3 | **I/O-Board 230V:** Der 230-V-Ausgang ist für eine definierte Last abgesichert. | Die aktuelle Auslegung zielt auf 8 A Dauerlast; Sicherung, Lastrelais, Leiterbahnen, Klemmen und Thermik werden gemeinsam am Prototyp geprüft. |
| E4 | **I/O-Board 24V:** Das Gerät besitzt einen potentialfreien Schaltausgang **C / NO / NC** für **24 V DC / 100 mA**. | Ein extern eingespeistes 24-V-Signal kann mit maximal 100 mA geschaltet werden, ohne elektrische Verbindung zum Netz oder zur internen Kleinspannung. Der Kontakt erzeugt selbst keine 24-V-Versorgung. |
| E5 | Es gibt keinen Not-Aus- oder Not-Halt-Schalter am Machine Node. | Der vorhandene Stopp-Taster wird in UI, Firmware und Dokumentation eindeutig als normaler Stopp bezeichnet. |
| E6 | Ein normaler Stopp beendet die Arbeitsfreigabe und startet bei Bedarf eine Nachlaufsequenz. | Der Stopp wird sofort als `STOPPED` angezeigt und löst, falls ein E-Stop Extension Board bestückt ist, sofort dessen Notaus-Kontakt aus. Die eigentliche Versorgung (Schaltausgang des I/O-Boards) wird **nicht** hart und sofort getrennt, sondern erst nach Ablauf der je Maschinenprofil konfigurierten Nachlaufzeit abgeschaltet — auch nicht durch den Stopp-Taster. Beispiele: Laser-Abluft 60 Sekunden, Bremse 10 Sekunden für FKS. Ein vorzeitiges hartes Abschalten der Versorgung kann die Maschine an einer eigenen kontrollierten Bremsung hindern und zu Schäden führen. |
| E7 | Kommunikationsverlust hat ein definiertes, konfigurierbares Verhalten. | Eine laufende Freigabe darf je nach Maschinenprofil und Timeout weiterlaufen; eine neue Freigabe ohne Serverbestätigung ist nie möglich. |

Die früheren NAMUR-Ausgänge (vormals E8) sind kein Bestandteil des I/O-Boards
mehr; sie sind eine Bestückvariante des optionalen **Extension Board**, siehe
Abschnitt "Extension Board (optional)".

### Lastklasse des I/O-Boards 230V

Für den direkten 230-V-Ausgang wird **8 A Dauerlast bei 230 V AC** als
Auslegungsziel festgelegt. Das entspricht ungefähr 1,84 kW. 16 A ist die
übliche Nennklasse einer Schuko-Versorgung, wird für diesen kompakten Node aber
nicht als direkte Dauerlast zugesagt: Motoren können beim Einschalten ein
Mehrfaches ihres Nennstroms ziehen.

| Beispiel-Last | Typischer Betriebsbereich | Bewertung der aktuellen Auslegung |
|---|---:|---|
| 3D-Drucker | ca. 0,5-2 A | Direkt geeignet |
| Desktop-CNC | ca. 2-6 A | Direkt geeignet, Anlaufstrom prüfen |
| Standfräse, ca. 800 W | ca. 3,5 A Nennstrom, höherer Anlaufstrom | Zielanwendung, Anlaufstrom und Dauerbetrieb prüfen |
| Kleine Drehmaschine, ca. 800 W | ca. 3,5 A Nennstrom, höherer Anlaufstrom | Zielanwendung, Anlaufstrom und Dauerbetrieb prüfen |
| Kleine Bandsäge | ca. 4-8 A Nennstrom, deutlich höherer Anlaufstrom | Nur nach Prüfung, besser externes Schütz (I/O-Board 24V) |
| Kleine Kreissäge | ca. 6-10 A Nennstrom, hoher Anlaufstrom | Nicht direkt zusagen, I/O-Board 24V mit externem Schütz bevorzugt |

Die konkrete Lastklasse muss mit Typenschild, Einschaltstrom und thermischer
Prüfung des fertigen I/O-Boards bestätigt werden. Standfräsen und kleine
Drehmaschinen bis etwa 800 W sind ausdrücklich als direkte Zielanwendungen
des I/O-Boards 230V vorgesehen, sofern ihr Anlaufstrom innerhalb der geprüften
Schaltgrenze liegt. Für Lasten bis 16 A oder für Motoren mit höherem
Anlaufstrom wird die I/O-Board 24V bestückt: der Node schaltet
dann nur das Steuersignal eines externen, passend dimensionierten Schützes.

### 2. Authentifizierung und Bedienung

| ID | Muss-Anforderung | Abnahmekriterium |
|---|---|---|
| B1 | Nutzer können sich per RFID authentifizieren. | Eine gültige Karte kann lokal gelesen und eine ungültige Karte abgewiesen werden. |
| B2 | Die Freigabe wird gegen ein konfiguriertes Backend bestätigt. | Während der Übergangsphase darf das Gerät gegen easyVerwaltung oder das Legacy-System validieren. Ohne gültige Antwort des konfigurierten Systems wird keine Lastfreigabe erteilt. |
| B3 | Der Stopp-Taster ist von aussen erreichbar. | Der Taster kann ohne Gehäuseöffnung betätigt werden, beendet die Arbeitsfreigabe sofort (inkl. sofortigem Notaus-Kontakt, falls E-Stop Extension Board bestückt) und löst die konfigurierte Nachlaufsequenz aus, bevor die Versorgung tatsächlich getrennt wird. |
| B4 | Das Gerät reagiert lokal auch bei Netzwerklast. | RFID, Stopp und lokale Rückmeldung bleiben bedienbar; der Stopp hat Vorrang vor Netzwerkverarbeitung. |
| B5 | Während der Freigabe wird der Name des verantwortlichen Nutzers angezeigt. | Nach erfolgreicher Authentifizierung erscheint der Klarname, zum Beispiel „Max Mustermann“, auf dem OLED und bleibt bis zum Ende der Freigabe beziehungsweise des Nachlaufs sichtbar. |
| B6 | Das Gerät besitzt einen Always-on-Modus für eingesteckte RFID-Karten. | In diesem Modus bleibt die Maschine freigegeben, solange die autorisierte Karte im geschützten Kartenfach erkannt wird. |
| B7 | Die Kartenpräsenz wird ohne mechanischen Präsenzschalter verifiziert. | Das Gerät prüft die Karte zyklisch über den RFID-Leser; eine entfernte oder nicht mehr gültige Karte beendet die Freigabe nach der definierten Reaktionszeit und folgt derselben Sequenz wie ein Stopp (sofortiger Notaus-Kontakt, Versorgungstrennung erst nach Nachlaufzeit). |

### 3. Anzeige und Rückmeldung

| ID | Muss-Anforderung | Abnahmekriterium |
|---|---|---|
| A1 | Das Gerät besitzt einen LED-Ring mit 12 adressierbaren RGB-LEDs. | Betriebs-, Authentifizierungs-, Freigabe-, Fehler- und Stoppzustände sind am Ring unterscheidbar. |
| A2 | Das Gerät besitzt ein OLED. | Versorgung, Netzwerk, Authentifizierung, Freigabe, Stopp und Fehler können lokal angezeigt werden; die Darstellung bleibt für die montierte Orientierung lesbar. |
| A3 | Das Gerät besitzt einen Summer. | Erfolg, Warnung, Fehler und Stopp erzeugen unterscheidbare akustische Rückmeldungen. |
| A4 | Die lokale Rückmeldung ist responsiv. | Anzeige und Summer reagieren innerhalb von 100 ms auf lokale Ereignisse. |
| A5 | Die Anzeige macht die Verantwortlichkeit sichtbar. | Im aktiven Freigabezustand ist der Klarname des verantwortlichen Nutzers eindeutig und lesbar dargestellt. |
| A6 | Der Always-on-Modus zeigt eine aktive Kartenprüfung. | Der LED-Ring zeigt ein dynamisches, wiederkehrendes Muster, solange die Karte zyklisch gelesen und akzeptiert wird; ein statisches Freigabe-Licht allein ist nicht ausreichend. Das OLED zeigt zusätzlich den Always-on-Zustand und den verantwortlichen Klarnamen. |

### Nachlaufprofile

Nach dem Stopp darf ein Gerät nur dann weiterlaufen, wenn dies als Nachlauf
für das Maschinenprofil vorgesehen ist. Die eigentliche Arbeitsfreigabe ist
bereits beendet.

| Anwendung | Nachlauf | Systemanforderung |
|---|---:|---|
| Laser-Abluft | 60 Sekunden | Abluft muss unabhängig von der Laserfreigabe geschaltet werden können. |
| Bremse, FKS | 10 Sekunden | Bremsfunktion muss über den vorgesehenen Schaltkanal kontrolliert nachlaufen. |

Bei nur einem gemeinsamen Schaltausgang (230V oder potentialfrei) bleiben
alle daran angeschlossenen Verbraucher während des Nachlaufs gemeinsam
eingeschaltet. Unabhängiger Nachlauf von Abluft, Bremse und Maschine
erfordert zusätzliche Schaltkanäle oder ein externes Nachlaufrelais.

> **Wichtig, Reihenfolge bei Stopp/Kartenentzug (z.B. FKS):** Erst wird —
> falls ein E-Stop Extension Board bestückt ist — sofort (per Firmware)
> dessen Notaus-Kontakt geöffnet, der in die Notaus-/Interlock-Schleife der
> Maschine eingeschleift ist. Die Maschine leitet dadurch ihre eigene
> kontrollierte Bremsung ein. Die eigentliche Versorgung (Schaltausgang des
> I/O-Boards, z.B. der potentialfreie Kontakt zum externen 400-V-Schütz bei
> der FKS) bleibt dabei bestehen und wird erst **nach Ablauf der
> Nachlaufzeit** abgeschaltet. Diese Reihenfolge gilt sowohl bei Betätigung
> des Stopp-Tasters als auch bei Kartenentzug im Always-on-Modus. Ein zu
> frühes, hartes Trennen der Versorgung hat in der Vergangenheit zu einem
> Maschinenschaden geführt, weil der Maschine dann die Energie für ihre
> eigene kontrollierte Bremsung fehlte.

### 4. Anschlüsse und Lastmessung

| ID | Muss-Anforderung | Abnahmekriterium |
|---|---|---|
| I1 | Netz-Eingang und der jeweils bestückte Schaltausgang (230-V-Ausgang oder potentialfreier Kontakt) besitzen definierte Kabeldurchführungen. | Kabel können durch die geschützten Durchführungen in das Gehäuse geführt werden; die eigentlichen Terminals sind erst nach dem Öffnen erreichbar. |
| I2 | Federklemmen sind der bevorzugte Feldanschluss. | Betätigbare Push-in-Klemmen können mit vorgesehenen Leitern ohne Spezialwerkzeug angeschlossen werden. |
| I3 | Schraubklemmen sind als zweite Anschlussvariante möglich. | Die Alternative passt in dasselbe Anschluss- und Gehäusekonzept. |
| I4 | Bei des I/O-Boards 230V ist eine einfache Lastmessung standardmäßig vorgesehen (kein optionales Feature mehr). | Ein galvanisch getrennter Sensor erkennt `LAST_AKTIV` und `LAST_AUS`, ohne Energieabrechnung zu versprechen, und ist bei des I/O-Boards 230V regulär bestückt. Bei der I/O-Board 24V nicht relevant, da kein Lastkreis über den Node läuft. |

Diese Umstufung von optional auf Standard geht auf Team-Feedback zur
Revision 1.1 zurück: Lastmessung schafft die Grundlage für spätere
nutzungsbasierte Abrechnung/Limits, macht den tatsächlichen Verbrauch
nachvollziehbar und hilft bei der Dimensionierung neuer Standorte.

Die früheren NAMUR-Anforderungen (vormals I5/I6) sind Teil des Extension
Boards, siehe folgender Abschnitt.

### Extension Board (optional)

Zusätzliche galvanisch getrennte I/O wird nicht auf jedem Node vorgehalten,
sondern über ein **generisches, optionales Extension Board** nachgerüstet,
das per Board-to-Board-Stecker auf das I/O-Board gesteckt wird. Ein Node
trägt höchstens ein Extension Board. I/O-Board und Extension Board sind
unabhängig voneinander bestellbar und bestückbar.

| ID | Muss-Anforderung | Abnahmekriterium |
|---|---|---|
| X1 | Das Extension Board ist ein steckbares Zusatzboard mit mehreren möglichen Bestückvarianten. | Mechanisch identischer Formfaktor und Board-to-Board-Stecker für alle Varianten; ein unbestücktes I/O-Board funktioniert ohne Extension Board vollständig gemäß Abschnitt 1-4. |
| X2 | **Bestückvariante NAMUR:** Das Extension Board besitzt zwei zusätzliche galvanisch optoisolierte NAMUR-Ausgänge und einen galvanisch getrennten NAMUR-Eingang. | Jeder Ausgang arbeitet als 24-V-DC-/4-mA-Schnittstelle für sonstige Zwecke; beide Ausgänge sind voneinander und von der Gerätesteuerung galvanisch getrennt. `OUT_A+/-` und `OUT_B+/-` liefern die 24-V-DC-/4-mA-Schnittstelle; `IN_NAMUR+/-` verarbeitet ein potentialfreies externes Signal als 24-V-NAMUR-kompatible Schnittstelle. |
| X3 | **Bestückvariante Digital-I/O:** Das Extension Board kann alternativ mit einfachen digitalen Ein-/Ausgängen ohne NAMUR-Anforderung bestückt werden. | Konkrete Beschaltung, Kanalzahl und Pegel werden vor dem Schaltplan dieser Variante festgelegt; hier zunächst nur als benannte, noch nicht spezifizierte zweite Bestückoption geführt. |

Die NAMUR-Variante wird für schätzungsweise 2 von 20 Nodes benötigt und ist
deshalb bewusst nicht Teil des Standard-I/O-Boards.

### E-Stop Extension Board (optional)

Manche Maschinen (z.B. FKS) haben eine eigene Notaus-/Interlock-Schleife,
die sofort unterbrochen werden muss, damit die Maschine ihre eigene
kontrollierte Bremsung einleitet — sowie oft eine elektromagnetisch gelöste
Bremse, die dauerhaft Strom braucht, um gelöst zu bleiben ("power-to-release
Bremse"): fällt die Spannung weg, fällt die Bremse fail-safe ein. Dafür gibt
es ein **eigenständiges, optionales E-Stop Extension Board** mit einem
einfachen Relais, dessen Kontakt in die Notaus-/Interlock-Schleife der
Maschine eingeschleift wird. Es steckt unabhängig vom generischen Extension
Board (NAMUR/Digital-I/O) über einen eigenen Board-to-Board-Stecker auf den
Stack.

**Wichtig:** Das E-Stop Extension Board unterbricht bei Stopp oder
Kartenentzug immer **sofort** die Notaus-Schleife — unabhängig vom
Nachlaufprofil. Die eigentliche Versorgung der Maschine (Schaltausgang des
I/O-Boards) ist davon getrennt zu betrachten und wird immer erst **nach**
Ablauf der Nachlaufzeit abgeschaltet, siehe Warnhinweis unter
"Nachlaufprofile". Diese Trennung ist zentral: nur so hat die Maschine
während ihrer eigenen kontrollierten Bremsung noch Energie zur Verfügung.

> **Hinweis zur Namensgebung:** Trotz des Namens "E-Stop" ist dieses Modul
> **kein** zertifiziertes Not-Aus- oder Not-Halt-Bauteil im Sinne von E5. Es
> unterbricht ausschliesslich die Notaus-/Interlock-Schleife bzw. die
> Bremsversorgung der externen Maschine, nicht die Hauptversorgung selbst.

| ID | Muss-Anforderung | Abnahmekriterium |
|---|---|---|
| BR1 | Das E-Stop Extension Board schaltet ein einfaches Relais mit **24 V DC / 100 mA** Kontaktbelastung, dessen Kontakt in die Notaus-/Interlock-Schleife bzw. Bremsversorgung der externen Maschine eingeschleift wird. | Ein extern eingespeister 24-V-DC-Stromkreis kann mit maximal 100 mA über das Relais durchgeschaltet werden, galvanisch getrennt von Netz und Gerätesteuerung. |
| BR2 | Die Schaltlogik ist fail-safe: stromlos = Notaus-Schleife unterbrochen / Bremse aktiv. | Das Relais ist im Ruhezustand (Coil stromlos) offen; die Notaus-Schleife ist dann unterbrochen bzw. die Bremse fällt ein. Erst ein aktives Freigabesignal der Steuerung schliesst das Relais. |
| BR3 | Das Relais öffnet bei Stopp oder Kartenentzug immer sofort, unabhängig vom Nachlaufprofil. | Bei Stopp-Taster **und** bei Kartenentzug im Always-on-Modus öffnet das Relais sofort (<100 ms) über den ESP32, unabhängig von der konfigurierten Nachlaufzeit. Es gibt aktuell keinen zusätzlichen, von der Firmware unabhängigen Hardware-Bypass. Die Versorgung der Maschine (I/O-Board-Ausgang) folgt **nicht** diesem sofortigen Öffnen, sondern bleibt bis zum Ende der Nachlaufzeit bestehen. |
| BR4 | Das Modul ist klar als Nicht-Not-Aus-Bauteil gekennzeichnet. | Beschriftung und Dokumentation verweisen eindeutig darauf, dass dieses Relais kein Personenschutz- oder Not-Halt-Bauteil ist. |

### 5. Umwelt und Montage

| ID | Muss-Anforderung | Abnahmekriterium |
|---|---|---|
| U1 | Das Gerät ist staubdicht und bietet Schutz gegen Berührung und Spritzwasser. | Zielgehäuse IP64: vollständig staubdicht (kein Eindringen von Staub, relevant für den Einsatz in der Holzwerkstatt) und Schutz gegen Spritzwasser aus allen Richtungen. Das Gehäuse ist nicht für Strahlwasser ausgelegt. |
| U2 | Das Gerät kann aufrecht, liegend oder in einem beliebigen Winkel dazwischen montiert werden. | Die Elektronik arbeitet in jeder vorgesehenen Einbaulage; die OLED-Anzeige wird über das Montageprofil so ausgerichtet, dass Texte lesbar bleiben. |
| U3 | Das Gerät ist kompakt und besteht aus einem bis vier PCBs (I/O-Board, MCU-Board, RFID-Board, optional Extension Board). | Die Standardbauweise bleibt als Stack realisierbar; MCU und RFID dürfen für eine kompakte Variante zu einem Board zusammengelegt werden. |
| U4 | Die interne Montage ist weitgehend schraubenlos. | Ausser den äusseren Gehäuseschrauben werden PCBs, Frontfenster und Führungen gesteckt oder geklipst. |
| U5 | Das Gehäuse trägt eindeutige Sicherheitshinweise und elektrische Kennwerte. | Die Hinweise sind dauerhaft lesbar, von aussen sichtbar und ohne Gehäuseöffnung verständlich. |
| U6 | Der Kartenkanal für eingesteckte RFID-Karten ist mechanisch vom staubdichten Geräteinnenraum getrennt. | Da die RFID-Erkennung berührungslos erfolgt, muss der Kartenkanal nicht selbst staubdicht sein: Staub/Sägemehl darf in den Kanal eindringen, wird aber nach unten ausgeführt (Drainage) statt sich anzusammeln oder in den Elektronikraum vorzudringen. Die Karte kann eingeführt und entnommen werden, ohne einen offenen Taster oder eine Öffnung in den staubdichten Innenraum zu benötigen. |
| U7 | Das Gehäuse muss von allen Seiten ausser der Display-Front befestigbar sein. | Je nach Einbausituation ist eine Verschraubung von hinten, seitlich, unten oder oben möglich, ohne den PCB-Stack zu verändern oder die Display-Front zu verdecken. |
| U8 | Im geöffneten Gerät ist kein netzführendes Teil berührbar. | Fest installierte, nur mit Werkzeug lösbare Abdeckplatten über dem I/O-Board geben ausschliesslich die Feldterminals und den Sicherungshalter frei; beide sind berührsichere Bauformen. MCU- und RFID-Board führen kein 230 V und dürfen berührt werden. Gilt auch dann, wenn das Gerät beim Öffnen noch am Netz hängt. |
| U9 | Die Boards sind gegen Staub und Feuchtigkeit beschichtet. | Alle Boards sind lackiert; Feldterminals, Sicherungskontakte und Board-to-Board-Stecker bleiben ausgespart. Der Lack stützt den IP-Schutz über die Lebensdauer, wird aber nicht auf Kriech- und Luftstrecken angerechnet. |

### 6. Service und Fertigung

| ID | Muss-Anforderung | Abnahmekriterium |
|---|---|---|
| S1 | Die Feldterminals sind nach dem Öffnen mit normalem Werkzeug erreichbar. | Nach dem Lösen der äusseren Gehäuseschrauben sind die Terminals sichtbar und bedienbar, ohne den Stack zu zerlegen. |
| S2 | Die interne Verdrahtung ist minimal. | Keine losen Litzen, keine Handverkabelung und keine handverlöteten Module im Serienaufbau. |
| S3 | Die Schaltfunktion des I/O-Boards ist wartbar. | Das I/O-Board kann ohne Löten getauscht werden; alternativ ist sein kompletter Austausch wirtschaftlich vorgesehen. |
| S4 | Die Baugruppe ist für SMD-Fertigung geeignet. | Bestückung, elektrische Prüfung und Service sind mit geringem Handarbeitsanteil möglich. |
| S5 | Die Lastausgangssicherung ist gesockelt und ohne Löten tauschbar. | F2 steckt in einem Sicherungshalter statt fest verlötet zu sein; nach dem Öffnen des Gehäuses lässt sich F2 mit normalem Werkzeug aus dem Sockel entnehmen und ersetzen, eine Ersatzsicherung wird im Gehäuse mitgeführt. **Dokumentierte Ausnahme:** Die Gerätesicherung F1 (500mA träge, interner Kurzschlussschutz) ist fest verlötet, nicht gesockelt — ein vorgelagerter Leitungsschutzschalter im Werkstattverteiler deckt den Netzkurzschlussfall ab, F1 schützt nur gegen interne Gerätefehler und muss im Feld praktisch nie getauscht werden. |

### Verbindliche Gehäusebeschriftung

Die Beschriftung muss dauerhaft, kontrastreich und abriebfest ausgeführt werden.
Sie darf nicht nur auf einem abnehmbaren Deckel stehen, wenn dadurch die
elektrischen Grenzwerte am Gerät fehlen. Die Beschriftung richtet sich nach
der tatsächlich bestückten I/O-Board-Variante und danach, ob ein Extension
Board bestückt ist.

Mindestens erforderlich:

- **„Bedienung nur nach Einweisung“**
- **„Achtung: 230 V AC“**
- **I/O-Board 230V:** „Direkter 230-V-Ausgang: max. 8 A Dauerlast / ca. 1,84 kW“
  und „Motoren und hohe Einschaltströme nur nach Prüfung oder über externes
  Schütz“
- **I/O-Board 24V:** „Potentialfreier Kontakt: max. 24 V DC / 100 mA“
- **Nur wenn Extension Board Variante NAMUR bestückt ist:**
  „OUT_A+/- / OUT_B+/-: je 24 V DC / 4 mA, optoisolierte NAMUR-Ausgänge“ und
  „IN_NAMUR+/-: galvanisch getrennter 24-V-NAMUR-Eingang“
- **Nur wenn E-Stop Extension Board bestückt ist:** „J18: max. 24 V DC / 100 mA,
  kein Not-Aus/Not-Halt-Bauteil, unterbricht sofort die Notaus-/Interlock-
  Schleife bzw. Bremsversorgung der Maschine; die Hauptversorgung trennt
  erst nach der konfigurierten Nachlaufzeit“
- eindeutige Kennzeichnung von **Netz-Eingang** und der tatsächlich bestückten
  Anschlüsse (**230-V-Ausgang** oder **C / NO / NC**, ggf. **OUT_A**, **OUT_B**,
  **IN_NAMUR** und/oder **J18 Bremsrelais** bei bestückten Erweiterungsboards)
- Hinweis, dass der Stopp-Taster **kein Not-Aus und kein Not-Halt** ist

Die Kennzeichnung wird zusätzlich in der Montage- und Bedienungsdokumentation
übernommen. Angaben zu Spannung, Leistung und Stromstärke müssen auch bei
montiertem Gerät lesbar bleiben.

Es gibt am Machine Node ausdrücklich **keinen Not-Aus- oder Not-Halt-Schalter**.
Der Stopp-Taster ist eine normale Bedienfunktion zum Beenden der Freigabe und
kein Personenschutz. Anforderungen an einen Not-Halt der angeschlossenen
Maschine liegen ausserhalb dieses Geräts und müssen separat gelöst werden.

> **Sicherheit:** Netzspannung darf nur von qualifizierten Personen geplant,
> aufgebaut, gemessen und in Betrieb genommen werden. Für Motoren,
> Frequenzumrichter oder Drehstrom ist eine externe Schütz-/Sensorlösung
> vorzusehen (I/O-Board 24V). Das Lastrelais auf der Platine
> ist kein universeller Motorschalter und keine Personenschutzfunktion.

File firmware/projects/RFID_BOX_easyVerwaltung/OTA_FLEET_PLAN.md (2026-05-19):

# OTA + Fleet Plan

Quelle: OTA/Fleet-Konzept fuer RFIDBOX_PoC.

## Workspace-Bezug
- Workspace-Root: /Users/marius/Github/easyVerwaltungHardware/firmware/projects/RFIDBOX_PoC
- Hauptdatei derzeit: src/main.cpp
- Ziel: Einheitliches Fleet-Deployment-Prinzip fuer RFIDBOX-Knoten.

## Kernziele
- Einheitlicher OTA-Workflow fuer alle RFIDBOX-Nodes
- Per-Device-Config persistent speichern (statt Build-spezifischer Firmware)
- Einmalig-Provisioning neuer Geraete ueber AP-Webinterface
- Zentrale Firmware-Ablage mit Versionierung und Kanalmodell (stable/beta)
- Selektive Updates pro Geraet + Flottenupdate
- Direkte Entwicklung aus VS Code weiterhin moeglich

## Hardware-Generationen
- RFIDBOX v0.1: ESP32 (aktuell)
- RFIDBOX v1.x: zukunftige Revisionen

## Aktueller Stand (2026-05-19, rfid-box/v0.1.0)
- easyAPI integriert: Login (single mode), Heartbeat, Health-Check implementiert
- Erster erfolgreicher Login-Durchlauf auf metal-mill-01 gegen svc_inst_006
- RFID-Lesen, Relay-Schaltung und Kartenziehen-Abmeldung funktionieren
- OTA-Infrastruktur vorbereitet (ArduinoOTA, Hostname per Environment)
- Firmware wird lokal gebaut und per USB/OTA deployed
- Noch kein zentrales Manifest-gesteuertes Pull-OTA aktiv
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

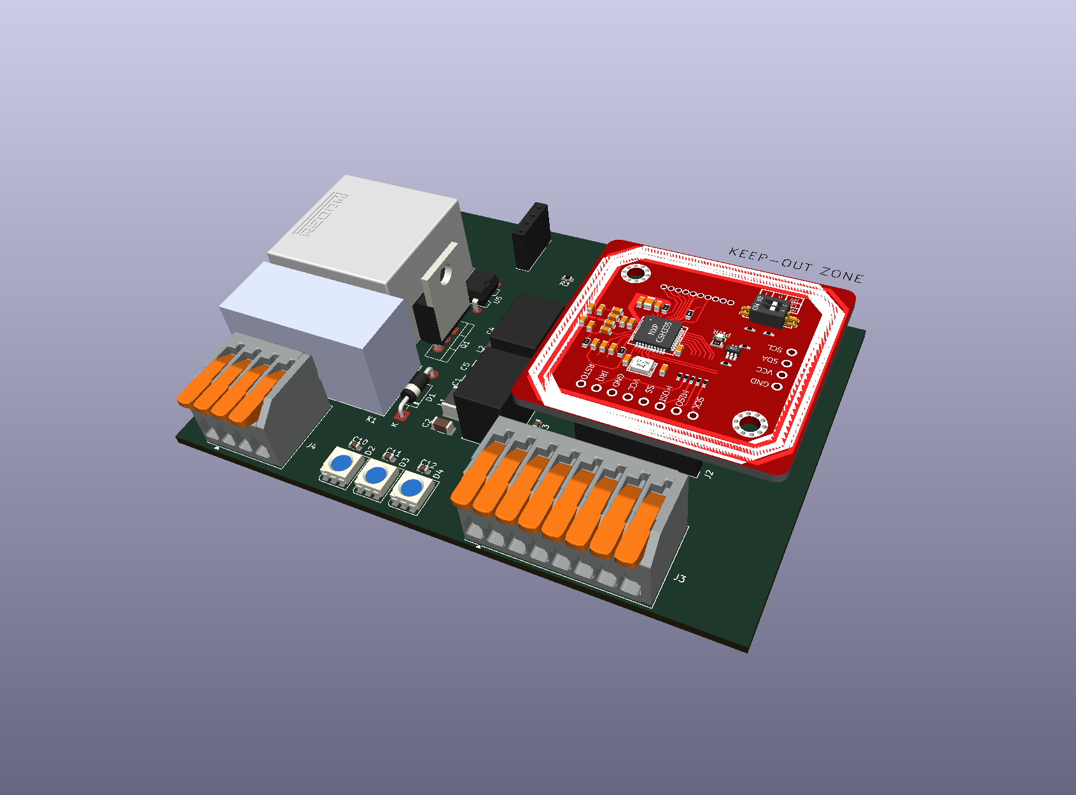
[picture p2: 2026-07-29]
hardware/projects/MicBac/PROJ-FRL-RIFD_Box/Electro/Renders/PNG-FRL-RFiD_Box.png

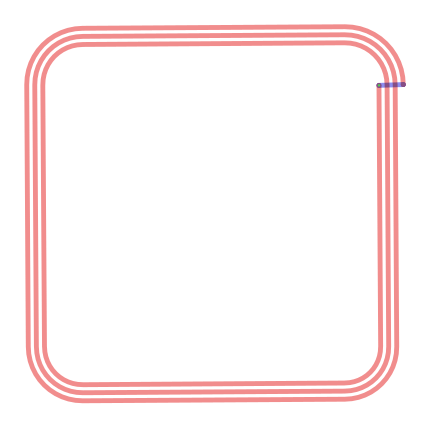
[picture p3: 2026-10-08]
hardware/projects/RFID_BOX/ECAD/RFID_Board/antenna/render_rr.png

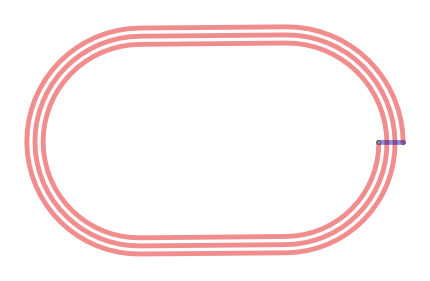
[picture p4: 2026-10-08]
hardware/projects/RFID_BOX/ECAD/RFID_Board/antenna/render_st.png

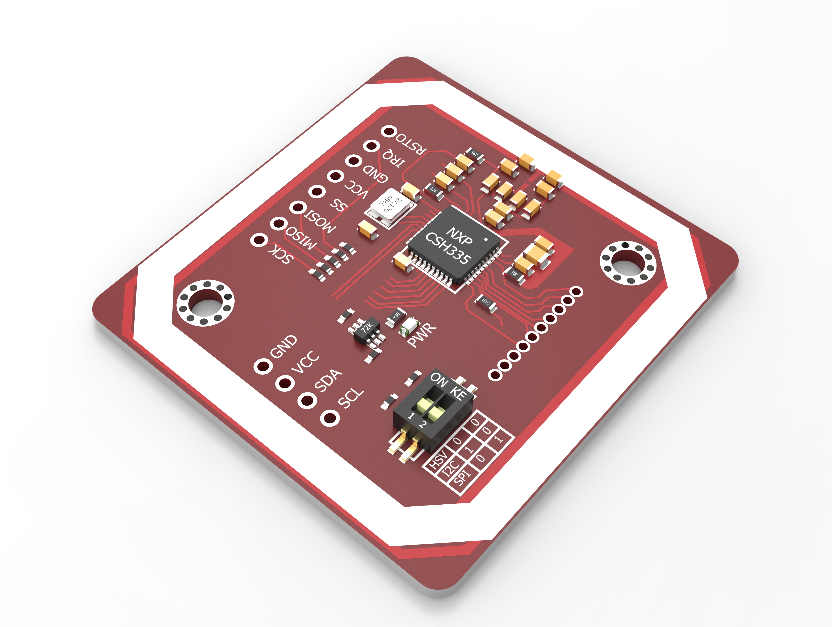
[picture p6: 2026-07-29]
hardware/projects/MicBac/PROJ-FRL-RIFD_Box/Electro/3D/PN532_render.png

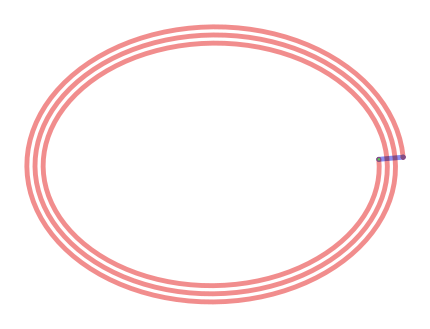
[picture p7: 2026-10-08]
hardware/projects/RFID_BOX/ECAD/RFID_Board/antenna/render_el.png

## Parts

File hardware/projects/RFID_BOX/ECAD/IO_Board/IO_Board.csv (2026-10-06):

Reference | Qty | Value | DNP | Exclude from BOM | Exclude from Board | Exclude from Position Files | Footprint | Distributor 1 | Distributor 1 Order Number | Distributor 2 | Distributor 2 Order Number | Manufacturer | Manufacturer Part Number
C300 | 1 | C_X2_890334023023CS |  |  |  | ${EXCLUDE_FROM_POS_FILES} | aa_MyParts:C_Wurth_WCAP-FTXX-P10L13W7H13 | Mouser | 710-890334023023CS | Digi-Key | 732-5733-ND | Wurth Elektronik | 890334023023CS
C301 | 1 | 100nF 50V |  |  |  | ${EXCLUDE_FROM_POS_FILES} | Capacitor_SMD:C_0603_1608Metric
C302 | 1 | 47uF 50V |  |  |  | ${EXCLUDE_FROM_POS_FILES} | aa_MyParts:CP_Radial_D6.3mm_H11.0mm_P2.50mm | Mouser | 710-860010673012 | Digi-Key | 732-8664-1-ND | Wurth Elektronik | 860010673012
C303,C328 | 2 | 10uF 10V 0805 |  |  |  | ${EXCLUDE_FROM_POS_FILES} | Capacitor_SMD:C_0805_2012Metric
C304,C307,C312,C317 | 4 | 10nF |  |  |  | ${EXCLUDE_FROM_POS_FILES} | Capacitor_SMD:C_0603_1608Metric
C305,C308,C313,C316 | 4 | 1uF |  |  |  | ${EXCLUDE_FROM_POS_FILES} | Capacitor_SMD:C_0603_1608Metric
C306,C311,C314,C315,C325 | 5 | 10uF |  |  |  | ${EXCLUDE_FROM_POS_FILES} | Capacitor_SMD:C_0603_1608Metric
C309,C310 | 2 | VY2472M49Y5US63L7 |  |  |  | ${EXCLUDE_FROM_POS_FILES} | Capacitor_THT:C_Disc_D12.5mm_W5.0mm_P7.50mm | Mouser | 72-VY2472M49Y5US63L7 | Digi-Key | VY2472M49Y5US63L7-ND | Vishay BC Components | VY2472M49Y5US63L7
C318,C319,C320,C321 | 4 | 33nF 50V |  |  |  | ${EXCLUDE_FROM_POS_FILES} | Capacitor_SMD:C_0603_1608Metric
C322 | 1 | 1uF 10V |  |  |  | ${EXCLUDE_FROM_POS_FILES} | Capacitor_SMD:C_0603_1608Metric
C323,C324,C327 | 3 | 100nF 25V |  |  |  | ${EXCLUDE_FROM_POS_FILES} | Capacitor_SMD:C_0603_1608Metric
C326 | 1 | 10uF 10V |  |  |  | ${EXCLUDE_FROM_POS_FILES} | Capacitor_SMD:C_0805_2012Metric
D300 | 1 | D_BAS16LT1G |  |  |  | ${EXCLUDE_FROM_POS_FILES} | Package_TO_SOT_SMD:SOT-23 | Mouser | 863-BAS16LT1G | Digi-Key | BAS16LT1GOSCT-ND | onsemi | BAS16LT1G
F300 | 1 | F_696309001002 |  |  |  | ${EXCLUDE_FROM_POS_FILES} | aa_MyParts:F_Wurth_WR-FSH_696309001002 | Mouser | 710-696309001002 | Digi-Key | 732-11383-ND | Wurth Elektronik | 696309001002
F301 | 1 | 10A 250VAC |  |  | Excluded from board | ${EXCLUDE_FROM_POS_FILES} |  | Mouser | 693-0034.3127 | Digi-Key | 486-1226-ND | SCHURTER Inc. | 0034.3127
F302 | 1 | 500mA 250VAC |  |  |  | ${EXCLUDE_FROM_POS_FILES} | aa_MyParts:F_MRT_BEL | Mouser | 530-MRT500BULKSHORT | Digi-Key | 5923-MRT500-BULK-ND | Bel Fuse | MRT 500-BULK
FB300,FB301,FB302 | 3 | 600R@100MHz |  |  |  | ${EXCLUDE_FROM_POS_FILES} | Inductor_SMD:L_0805_2012Metric | Mouser | 652-MH2029-601Y | Digi-Key | MH2029-601YCT-ND | Bourns | MH2029-601Y
FB303,FB304,FB306,FB307 | 4 | 330R@100MHz |  |  |  | ${EXCLUDE_FROM_POS_FILES} | Inductor_SMD:L_0402_1005Metric | Mouser |  | Digi-Key | 490-18371-1-ND | Murata Electronics | BLM15EX331SN1D
J300,J301 | 2 | J_WAGO_2604-1103 |  |  |  | ${EXCLUDE_FROM_POS_FILES} | aa_MyParts:J_2604-1103_WAG | Mouser | n/A | Digi-Key | 2946-2604-1103-ND | WAGO | 2604-1103
J302 | 1 | Conn_01x10_Pin |  |  |  | ${EXCLUDE_FROM_POS_FILES}
K300 | 1 | T92S11D12-24 |  |  |  | ${EXCLUDE_FROM_POS_FILES} | aa_MyParts:K_T92S11D12-24 | Mouser | 655-T92S11D12-24 | Digi-Key | PB352-ND | TE Connectivity Potter & Brumfield | T92S11D12-24
L300 | 1 | RN102-1-02-3M0 |  |  |  | ${EXCLUDE_FROM_POS_FILES} | aa_MyParts:L_RN102_SCN | Mouser | 631-RN102-1-02-3M0 | Digi-Key | 817-2084-ND | TE Connectivity Schaffner | RN102-1-02-3M0
Q300,Q302 | 2 | 2N7002NXAKR |  |  |  | ${EXCLUDE_FROM_POS_FILES} | Package_TO_SOT_SMD:SOT-23 | Mouser | 771-2N7002NXAKR | Digi-Key | 1727-8643-1-ND | Nexperia USA Inc. | 2N7002NXAKR
Q301 | 1 | BSS84AK |  |  |  | ${EXCLUDE_FROM_POS_FILES} | Package_TO_SOT_SMD:SOT-23 | Mouser | 771-BSS84AK215 | Digi-Key | 1727-1144-1-ND | Nexperia USA Inc. | BSS84AK,215
R300 | 1 | 2mR |  |  |  | ${EXCLUDE_FROM_POS_FILES} | Resistor_SMD:R_2010_5025Metric | Mouser | 652-CRF2010FZR002ELF | Digi-Key | 118-CRF2010-FZ-R002ELFCT-ND | Bourns Inc. | CRF2010-FZ-R002ELF
R301,R302,R306,R312,R315 | 5 | 1k |  |  |  | ${EXCLUDE_FROM_POS_FILES} | Resistor_SMD:R_0603_1608Metric
R303,R304 | 2 | 499k |  |  |  | ${EXCLUDE_FROM_POS_FILES} | Resistor_SMD:R_2010_5025Metric
R307 | 1 | 10R |  |  |  | ${EXCLUDE_FROM_POS_FILES} | Resistor_SMD:R_0603_1608Metric
R308,R309,R311 | 3 | 2k |  |  |  | ${EXCLUDE_FROM_POS_FILES} | Resistor_SMD:R_0603_1608Metric
R313,R314,R316,R317,R318 | 5 | 47k |  |  |  | ${EXCLUDE_FROM_POS_FILES} | Resistor_SMD:R_0603_1608Metric
RV300 | 1 | RVAR_B72210S0271K101 |  |  |  | ${EXCLUDE_FROM_POS_FILES} | Varistor:RV_Disc_D12mm_W5.1mm_P7.5mm | Mouser | 871-B72210S271K101 | Digi-Key | 495-3786-ND | TDK (EPCOS) | B72210S0271K101
U300 | 1 | ISOW7721DFMR |  |  |  | ${EXCLUDE_FROM_POS_FILES} | Package_SO:SOIC-20W_7.5x12.8mm_P1.27mm | Mouser | 595-ISOW7721DFMR | Digi-Key | 296-ISOW7721DFMRCT-ND | Texas Instruments | ISOW7721DFMR
U301 | 1 | IRM-10-24 |  |  |  | ${EXCLUDE_FROM_POS_FILES} | aa_MyParts:IC_IRM-10-24_THT | Mouser | 709-IRM10-24 | Digi-Key | 1866-3030-ND | MEAN WELL | IRM-10-24
U302 | 1 | MCP39F511A-E/MQ |  |  |  | ${EXCLUDE_FROM_POS_FILES} | aa_MyParts:IC_QFN28_MQ_MCH | Mouser | 579-MCP39F511AE/MQ | Digi-Key | MCP39F511A-E/MQ-ND | Microchip Technology | MCP39F511A-E/MQ
U306 | 1 | R-78K5.0-2.0 |  |  |  | ${EXCLUDE_FROM_POS_FILES} | aa_MyParts:IC_CONV_R-78K5.0-2.0 | Mouser | 919-R-78K5.0-2.0 | Digi-Key | 945-R-78K5.0-2.0-ND | Recom Power | R-78K5.0-2.0
U307 | 1 | AP2114H-3.3TRG1 |  |  |  | ${EXCLUDE_FROM_POS_FILES} | Package_TO_SOT_SMD:SOT-223-3_TabPin2 | Mouser | 621-AP2114H-3.3TRG1 | Digi-Key | AP2114H-3.3TRG1DICT-ND | Diodes Incorporated | AP2114H-3.3TRG1

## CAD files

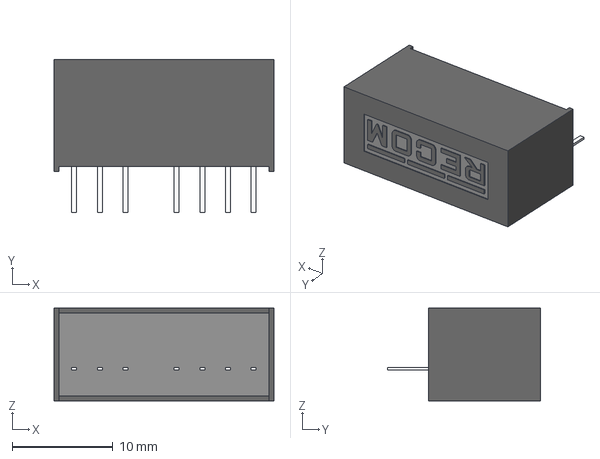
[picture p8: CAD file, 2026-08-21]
hardware/projects/MicBac/PROJ-FRL-RIFD_Box/Electro/3D/RS6-2405S.step
21.8 x 15.2 x 9.20 mm

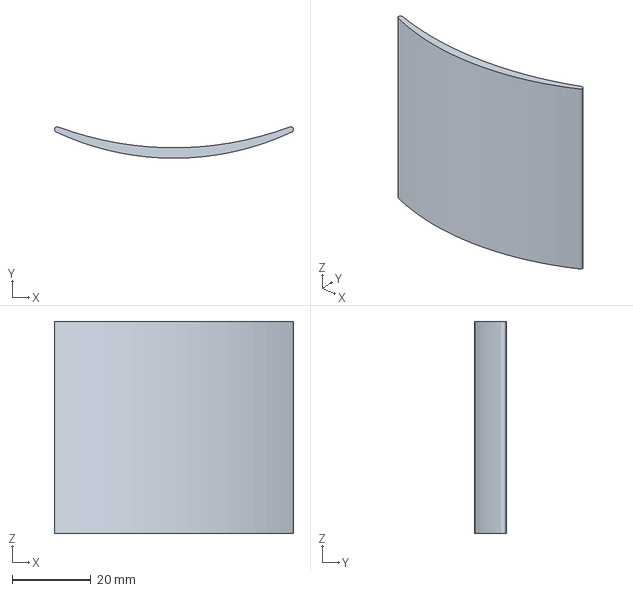
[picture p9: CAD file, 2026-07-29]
hardware/projects/MicBac/PROJ-FRL-RIFD_Box/FRL-RFID_Box-V01-B-Spring.3mf
60.8 x 8.01 x 54.0 mm

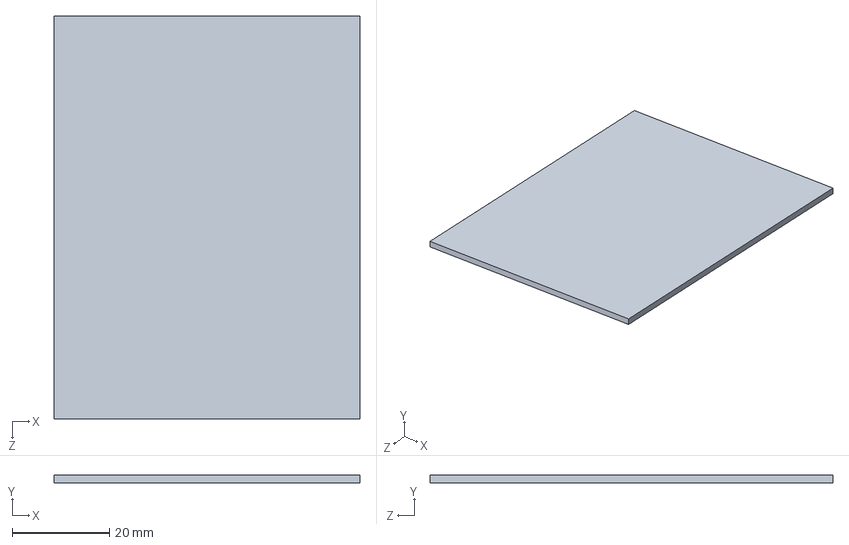
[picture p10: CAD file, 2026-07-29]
hardware/projects/MicBac/PROJ-FRL-RIFD_Box/Mech/CAD/SW/SB-PCB_Top.SLDPRT
63.0 x 1.60 x 83.0 mm

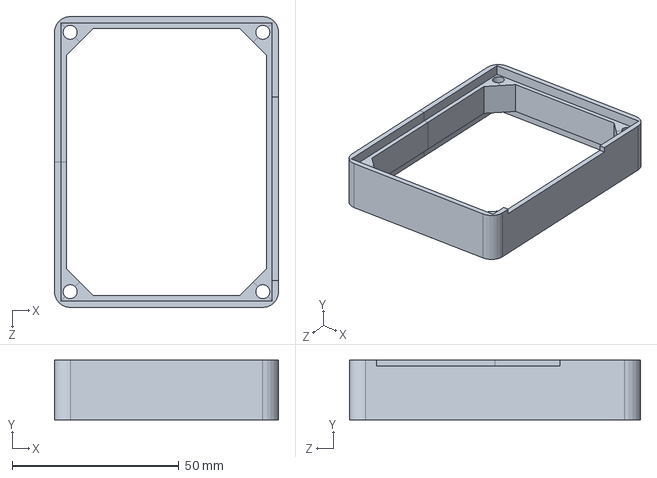
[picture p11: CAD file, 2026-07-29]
hardware/projects/MicBac/PROJ-FRL-RIFD_Box/PROJ-FL-RFiD_Box_SOLIDWORKS/SB-Mid.SLDPRT
67.3 x 17.9 x 87.3 mm

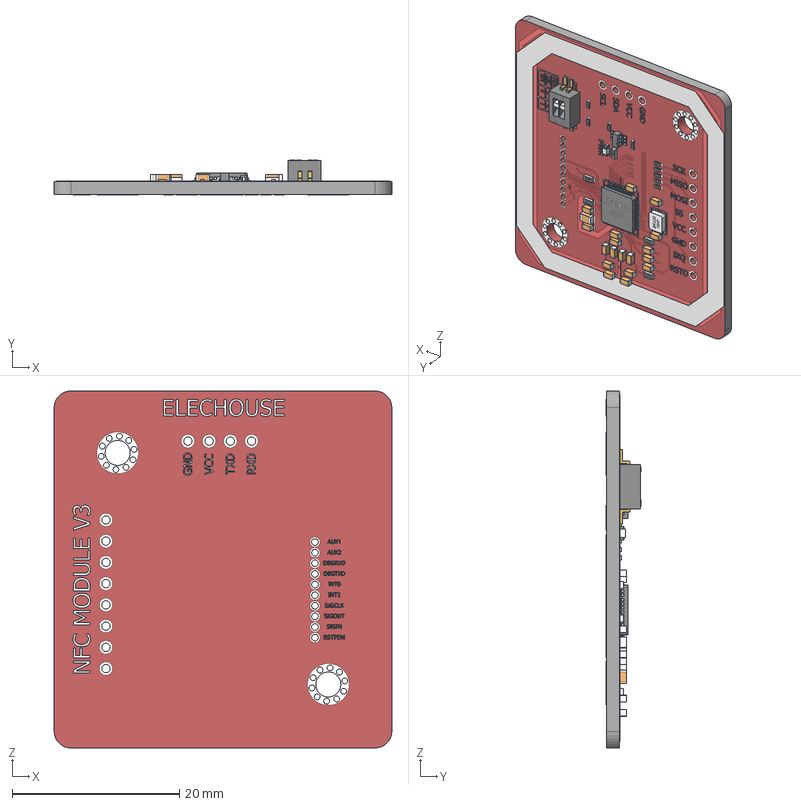
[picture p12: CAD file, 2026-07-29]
hardware/projects/MicBac/PROJ-FRL-RIFD_Box/Electro/3D/PN532.stp
40.4 x 4.13 x 42.7 mm
Board
Capacitor (0805) x 18
Resistor (0603)
Resistor (0603)_3 x 2
Resistor (0603)_1
Resistor (0603)_2
Led
Resistor (0603)_4 x 9
Capacitor (0805)_1
Crystal
Chip
72K
Button

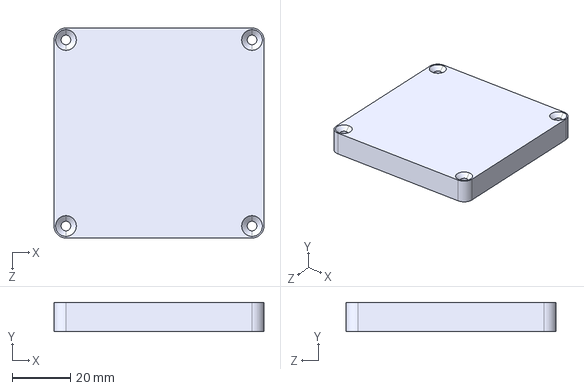
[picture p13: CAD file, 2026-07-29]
hardware/projects/MicBac/PROJ-FRL-RIFD_Box/Mech/CAD/SW/SB-Card_Extension.STEP
72.0 x 10.0 x 72.0 mm

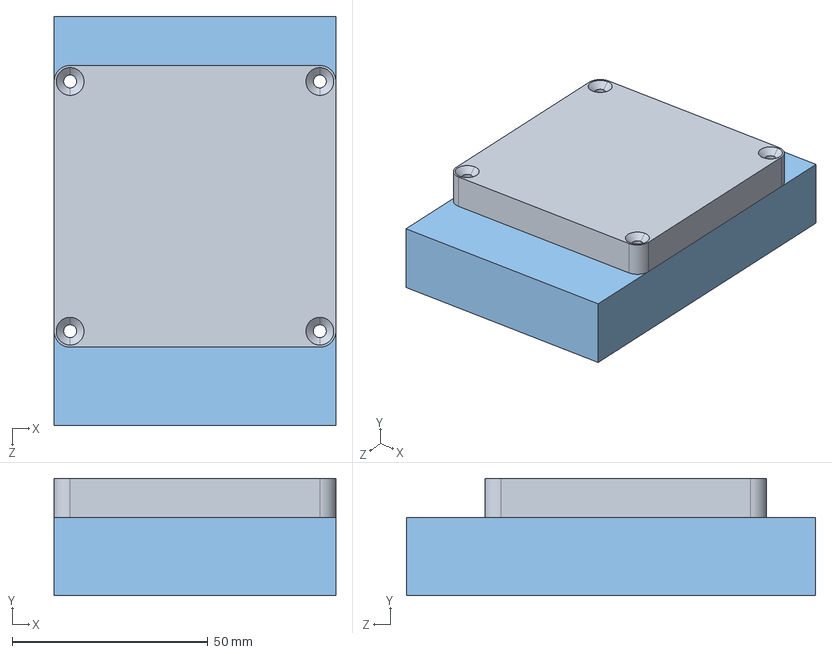
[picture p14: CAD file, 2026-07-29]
hardware/projects/MicBac/PROJ-FRL-RIFD_Box/PROJ-FL-RFiD_Box_SOLIDWORKS/RFID_Box_Card_Extension.STEP
72.0 x 30.0 x 104.5 mm

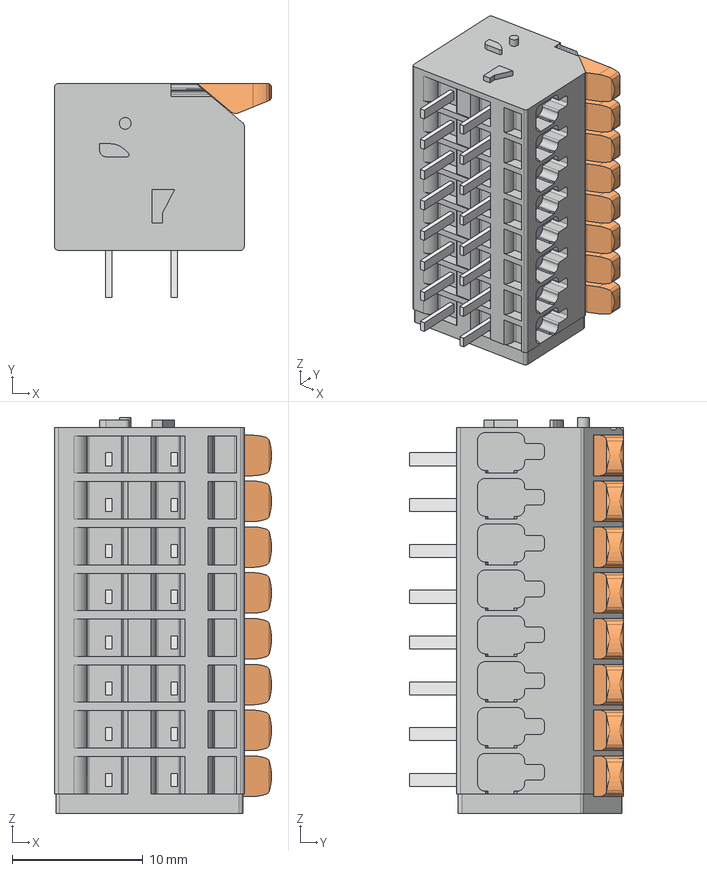
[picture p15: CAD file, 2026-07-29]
hardware/projects/MicBac/PROJ-FRL-RIFD_Box/Electro/3D/2601-1108.stp
16.6 x 16.4 x 30.2 mm

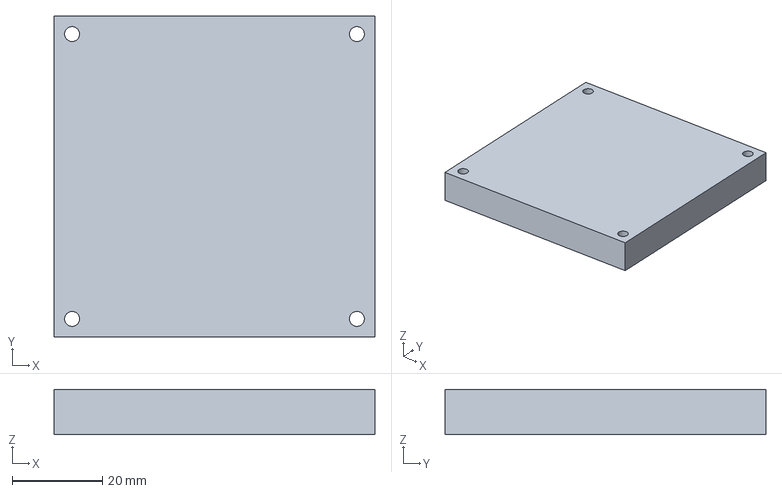
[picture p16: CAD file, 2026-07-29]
hardware/projects/MicBac/PROJ-FRL-RIFD_Box/FRL-RFID_Box-V03.FCStd
71.0 x 71.0 x 10.0 mm

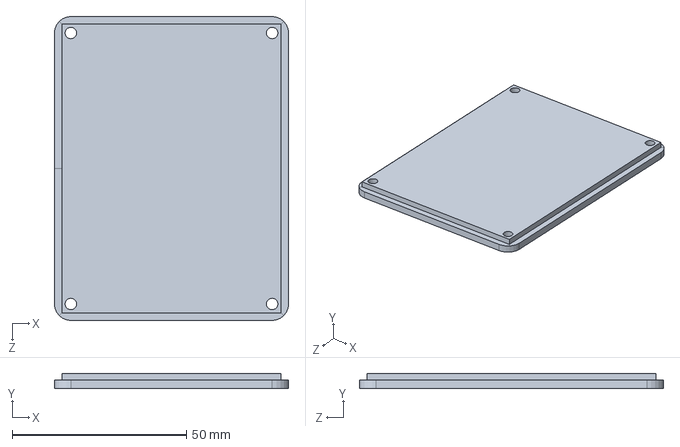
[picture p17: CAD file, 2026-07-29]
hardware/projects/MicBac/PROJ-FRL-RIFD_Box/Mech/CAD/SW/SB-Bot.SLDPRT
67.3 x 4.35 x 87.3 mm

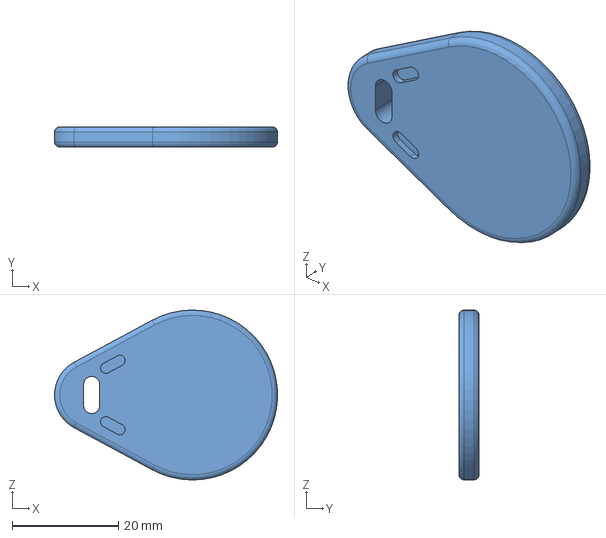
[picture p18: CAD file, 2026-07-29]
hardware/projects/MicBac/PROJ-FRL-RIFD_Box/Electro/3D/Card 2.stp
42.0 x 3.80 x 32.0 mm

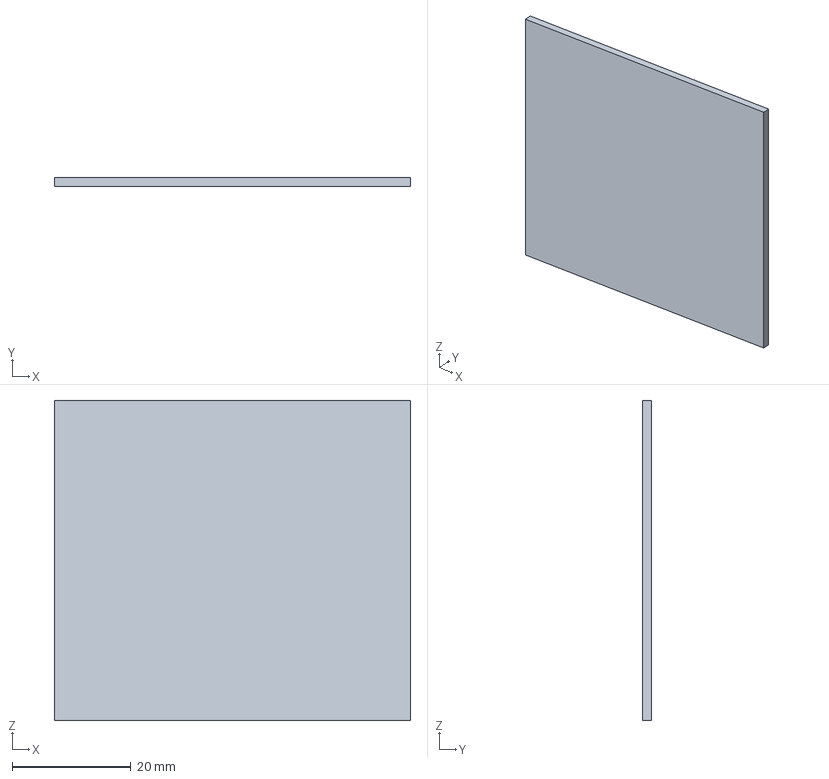
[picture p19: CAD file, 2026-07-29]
hardware/projects/MicBac/PROJ-FRL-RIFD_Box/FRL-RFID_Box-V01-B-PCB.3mf
60.0 x 1.60 x 54.0 mm

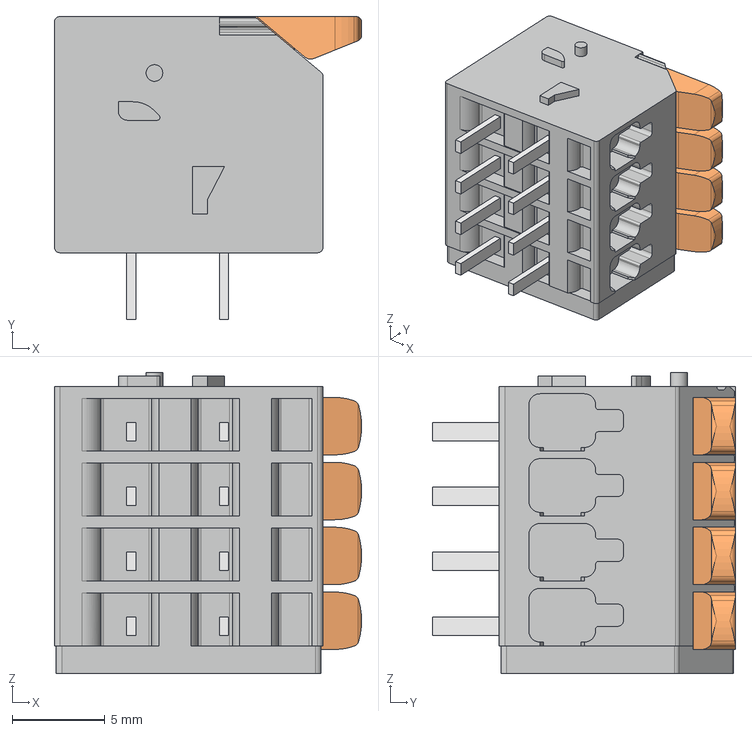
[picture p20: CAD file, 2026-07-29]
hardware/projects/MicBac/PROJ-FRL-RIFD_Box/Electro/3D/2601-1104.stp
16.6 x 16.4 x 16.2 mm

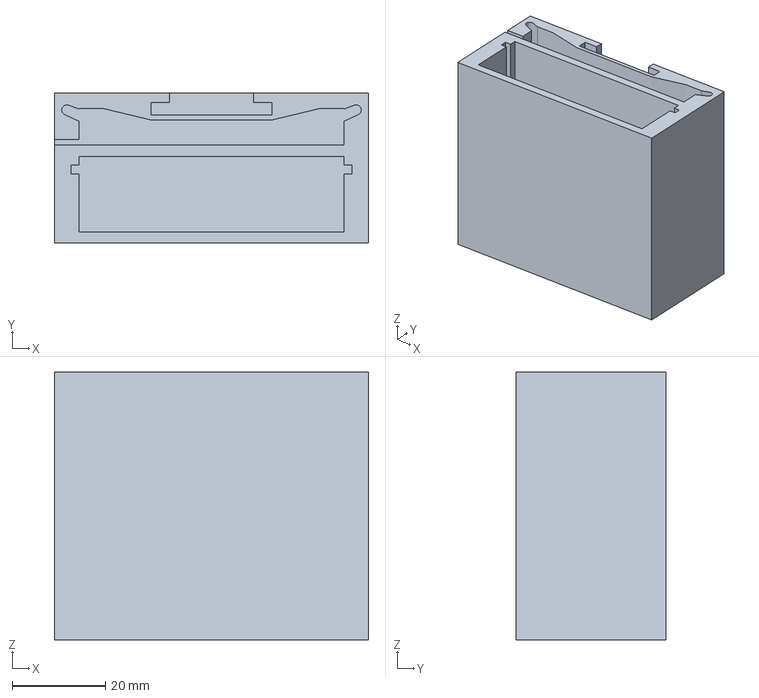
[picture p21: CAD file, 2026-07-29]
hardware/projects/MicBac/PROJ-FRL-RIFD_Box/FRL-RFID_Box-V01-B-Case.3mf
67.3 x 32.2 x 57.4 mm

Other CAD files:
hardware/projects/MicBac/PROJ-FRL-RIFD_Box/PROJ-FL-RFiD_Box_SOLIDWORKS/SB-Top.SLDPRT
hardware/projects/MicBac/PROJ-FRL-RIFD_Box/Mech/CAD/SW/SB-Top.SLDPRT
hardware/projects/MicBac/PROJ-FRL-RIFD_Box/Electro/3D/2601-1104.sldprt
hardware/projects/MicBac/PROJ-FRL-RIFD_Box/Electro/3D/2601-1108.sldprt
hardware/projects/MicBac/PROJ-FRL-RIFD_Box/Electro/3D/Card 1.stp
hardware/projects/MicBac/PROJ-FRL-RIFD_Box/Electro/3D/Finder_41.52.SLDPRT
hardware/projects/MicBac/PROJ-FRL-RIFD_Box/Electro/3D/Finder_41.52.STEP
hardware/projects/MicBac/PROJ-FRL-RIFD_Box/Electro/3D/RAC05-24SK--3DModel-STEP-498702.STEP
hardware/projects/MicBac/PROJ-FRL-RIFD_Box/FRL-RFID_Box-V01.FCStd
hardware/projects/MicBac/PROJ-FRL-RIFD_Box/FRL-RFID_Box-V02.FCStd
hardware/projects/MicBac/PROJ-FRL-RIFD_Box/Mech/CAD/SW/RFID_Box_Card_Extension.SLDPRT
hardware/projects/MicBac/PROJ-FRL-RIFD_Box/Mech/CAD/SW/RFID_Box_Layer_Case.SLDPRT
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

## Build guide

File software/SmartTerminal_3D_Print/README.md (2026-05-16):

# SmartTerminal_3D_Print

Dieses Verzeichnis ist ein Entwicklungsgeruest fuer das Smart Terminal 3D-Print.

Ziel: schneller Entwicklungsstart mit einer lauffaehigen Basis, die die Architektur und den Lifecycle aus der Wiki abbildet.

## Was dieses Geruest bereits abbildet

- Drei Container gemaess Wiki:
  - backend (FastAPI)
  - ui (nginx + statisches Frontend)
  - device-agent (FastAPI als HAL-Scaffold)
- OTA-Skripte und First-Boot-Skripte als Integrationsgeruest
- Dev-Overrides fuer Remote-SSH-Workflow auf dem Pi

## Was bewusst noch Platzhalter ist

- Job-Queue, RFID-Session und Payment-Logik
- Echte PrusaLink-Emulation und Drucker-Forwarding
- Hardware-Ansteuerung fuer RFID, GPIO und I2C
- Produktionsreifer CI/CD-Lifecycle

## Konsistenz zur Wiki

Dieses Geruest folgt den Rollen und Schnittstellen aus:
- Smart Terminal: Dokumentation & Entwicklung
- Smart Terminal - 3D-Print-Server: Dokumentation & Entwicklung
- Deployment & Betrieb: Smart Terminal

Wichtig: In der Entwicklung kann lokal mit `config/printers.dev.json` gearbeitet werden.
Der Produktionspfad fuer Druckerzuordnung bleibt die server-/share-basierte Konfiguration aus der Wiki.

## Lokaler Start (Entwicklung)

1. Beispielkonfiguration kopieren:

   cp config/terminal.example.env config/terminal.env
   cp config/printers.example.json config/printers.dev.json

2. Stack starten:

   docker compose up --build

3. Verfuegbare Endpunkte:

- UI: http://localhost
- Backend Health: http://localhost:8000/api/health
- Printer API Health: http://localhost:8000/api/v1/health
- Device Agent Health: http://localhost:8081/health

## Leitlinie

Solange Features noch fehlen, sollen Stubs explizit "scaffold" markieren statt Produktionsreife zu suggerieren.

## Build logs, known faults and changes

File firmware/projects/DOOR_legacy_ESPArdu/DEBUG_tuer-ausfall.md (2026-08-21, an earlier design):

# Debugging: wiederkehrender Tür-Ausfall (ATmega „verschluckt sich")

Stand: 2026-06-30 · Projekt: `DOOR_legacy_ESPArdu` · Board: RobotDyn UNO+WiFi R3

## Beobachtung (Ausfall vom Morgen 2026-06-30)

- ESP loggte **durchgehend** bis zum Ziehen der SD-Karte → ESP lief stabil.
- Auf der SD-Karte nur „wenige Infos über IP connection des ESP" (vermutlich die
  HB-Heartbeat-Zeilen, die die IP prominent zeigen).
- Tür **reagierte nicht auf RFID-Karte**.
- Keine ATmega-Outputs im Log — aber: der Logger tappt nur die **ESP→ATmega**-Leitung;
  ATmega-Nachrichten sehen wir nur indirekt über die ESP-Spiegelung (`DBG:[ATM] …`).

## Architektur-Kontext (für Wiedereinstieg)

```
[Backend] ←HTTP→ [ESP8266: Logik/State/WiFi/OTA] ←UART 9600→ [ATmega328P: RFID/Motor/LED]
```
- Ein gemeinsamer Hardware-UART, 9600 Baud. SD-Logger hängt am Bus, liest die ESP-TX-Leitung.
- ESP spiegelt Diagnose + ATmega-Events als `DBG:…` auf Bus **und** Telnet
  (`busDbg()`, [src_esp/main.cpp:105](src_esp/main.cpp#L105)).
- ATmega spricht nur bei Events (`RFID:`, `BTN:`, `REED:`, `MOTOR:OK/TIMEOUT`),
  auf `PING` mit `PONG`, und `ATMDBG:BOOT …` beim Start. **Kein eigener Heartbeat.**
- ATmega-Firmware-Update braucht USB + DIP-Wechsel vor Ort (nicht OTA!).
  ESP-Update geht per OTA (`door_01_esp_ota`).

## Diagnose: zwei Fehlerbilder, die gleich aussehen

| | Bild A: ATmega hängt/tot | Bild B: ATmega lebt, nur RFID tot |
|---|---|---|
| `PONG` | hört auf | kommt weiter |
| HB-Feld `atmega=` | `DEAD` | `OK` |
| `DBG:[ATM] …` | keine mehr | keine RFID, aber sonst aktiv |
| LEDs | eingefroren | reagieren auf ESP-Befehle |
| Ursache | Hang / Reset / TX-Draht tot | RC522 weggekippt (SPI/EMI/Brownout) |

RC522-Healthcheck (re-init bei VersionReg 0x00/0xFF) ist bereits drin
([src_atmega/main.cpp:181](src_atmega/main.cpp#L181), Commit 28f77c6).
Da der Fehler **danach** wiederkam: entweder Bild A, oder der RC522 kippt so weg,
dass der VersionReg-Check ihn nicht fängt (liest gültige Version, aber Feld/Antenne tot;
oder `PCD_Init()` heilt den Bus nicht voll).

## SCHRITT 0 (zuerst tun): vorhandenes Log auswerten

Das entscheidende Feld steht **schon im Log**. Jede Heartbeat-Zeile
([src_esp/main.cpp:230](src_esp/main.cpp#L230)) endet mit `atmega=OK|DEAD`:

```
HB up=… wifi=192.168… … state=STANDBY atmega=OK    ← Bild B (ATmega lebt, RFID tot)
HB up=… wifi=192.168… … state=STANDBY atmega=DEAD  ← Bild A (ATmega weg)
```

**Im Log prüfen:**
1. Letzte HB-Zeilen vor dem Kartenziehen: steht da `atmega=OK` oder `DEAD`?
2. Taucht irgendwo `DBG:[ATM] BOOT reason=…` auf? (= ATmega hat rebootet → A,
   `reason` sagt warum: `WDT` Hänger, `BOD` Brownout/Motorstrom, `EXT`/`POR` Strom)
3. HB-Kadenz: alle 5 s? Lücken/Stopp = ESP-Problem; durchgehend = ESP ok (erwartet).

**Achtung False Positive:** `atmega=DEAD` erscheint auch während langer Motorfahrten
(ATmega bis ~42 s blockiert, kein PONG; Timeout 15 s, [src_esp/settings.h:25](src_esp/settings.h#L25)).
Beim stillen Morgen-Ausfall gab's keine Fahrt → hier sauber zu werten.

→ **Ergebnis (2026-06-30):** **Bild B** — laut Auswertung **kein `atmega=DEAD`** im Log.
ATmega lief weiter (PONG kam), nur der RFID-Pfad war tot. → ATmega-Hang vom Tisch,
Verdächtiger ist der **RC522-Leser** (SPI lebendig, RF-Frontend tot). Siehe Abschnitt unten.

---

## Befund 2026-06-30: Bild B → RC522 (verifiziert)

ATmega lebte, nur Karten wurden nicht mehr gelesen. Library-Verhalten geprüft
([MFRC522.cpp:198-242](.pio/libdeps/door_01_atmega_usb/MFRC522/src/MFRC522.cpp#L198-L242)):

- Das `PCD_Init()` (Health-Check + nach jedem Lesen) macht im Betrieb nur einen
  **Soft-Reset** — Hard-Reset nur, wenn RST-Pin LOW gelesen wird (passiert nie im Betrieb).
- `PCD_Init()` ruft am Ende `PCD_AntennaOn()` (TX1/TX2 wieder ein) → ein volles Re-Init
  **heilt** einen weggekippten RF-Frontend.
- **Lücke:** Health-Check ruft `PCD_Init()` **nur bei VersionReg 0x00/0xFF** auf (= totes SPI).
  Den Fall „SPI lebt, RF/Register glitchen" deckt er **nicht** ab → Karten werden stumm ignoriert.

### Vermutete physikalische Ursache
- EMI/Brownout durch **Stepper-Motor** glitcht den RC522. Passt zur Morgen-Timeline:
  letzte Abend-Fahrt hinterlässt geglitchten Leser → sitzt über Nacht tot → erste
  Morgen-Karte schlägt fehl, VersionReg noch gültig → keine Recovery.

### Noch zwei KOSTENLOSE Log-Checks (vor Reflash!)
Beides steht in den ATmega-Reflexionen im vorhandenen Log:
1. **`state=` in den HB-Zeilen durchgehend `STANDBY`?** Falls ESP in `IDENT`/`RESET`
   festhing → **ESP-Bug, per OTA fixbar, kein Reflash nötig**. (Unwahrscheinlich, aber 10 s Suche.)
2. **`DBG:[ATM] … RFID reinit dead` im Log?**
   - **Ja** → VersionReg war tot → SPI weg → Soft-Re-Init heilt nicht → **Hard-Reset/Power-Fix** nötig.
   - **Nein** (und kein `RFID card=`) → Leser still tot bei gültigem VersionReg →
     **„alive-but-not-reading"** → **unbedingtes Re-Init** nötig.

### Fix-Plan (braucht EINEN ATmega-Reflash vor Ort — bündeln!)
Da Confirm + Fix beide einen Reflash brauchen, alles in **einen** Flash packen:

1. **Recovery härten** ([src_atmega/main.cpp:181](src_atmega/main.cpp#L181), `pollRFID` Health-Check):
   - **Unbedingtes volles Re-Init** alle ~5 s im Idle (nicht nur bei VersionReg 0x00/0xFF)
     ODER Register-Drift prüfen (TxControlReg-Antennenbits `0x03`, ModeReg `0x3D`) und bei
     Abweichung re-initen. Heilt „alive-but-not-reading".
   - **Echten Hard-Reset** auf dem Health-Pfad: RST-Pin (Pin 5) ~wenige µs LOW, dann HIGH,
     `delay(50)`, dann `PCD_Init()`. Gründlicher als Soft-Reset bei wedged Chip.
   - **Re-Init nach jeder Motorfahrt** (`runOpenDoor`/`runCloseDoor`) → trifft die EMI-Quelle direkt.
2. **Diagnose mitflashen** (damit nächster Ausfall eindeutig ist):
   - VersionReg **und** TxControlReg periodisch loggen (`ATMDBG:RFID ver=.. tx=..`),
     jedes Re-Init mit Registerwert.
   - ATmega-Selbst-Heartbeat `ATMDBG:ALIVE n=<count>` (siehe Maßnahme 3 oben).
   → Falls es trotzdem wieder ausfällt, zeigen die Logs exakt die Registerwerte.

**Nächster Schritt:** Erst die zwei kostenlosen Log-Checks oben. Dann ein gebündelter
ATmega-Reflash mit gehärteter Recovery + Diagnose + Heartbeat.

---

## Log-Auswertung (echte SD-Logs LOG00013+00014, ~144k Zeilen)

Ausgewertet mit `analyze_log.py`. **Diagnose Bild B jetzt hart bestätigt:**

**Beweise:**
1. **`state=` immer STANDBY** (68463×, kein einziges IDENT/RESET) → ESP war durchgehend
   bereit, kein State-Hänger, kein OTA-Bug. Check 1 negativ.
2. **`RFID reinit dead` = 0** → VersionReg war nie tot, SPI lebte. Check 2 negativ
   → **„alive-but-not-reading"** bestätigt.
3. **Neueste Datei LOG00014 (letzte ~1h40m, up=279523→285573, KEIN Reboot):
   NULL Kartenlesungen**, aber `[ATM] REED=0/REED=1` um „07:51" → Tür wurde **physisch
   benutzt, ohne dass eine Karte gelesen wurde**. ATmega lebte (REED kam durch,
   `atmega=OK` durchgehend), nur der RC522 las nichts. → Lehrbuch-Bild-B.
   Letzte erfolgreiche Lesung noch in LOG00013; RC522 starb um den Übergang 13→14
   und blieb ≥1h40m tot — ohne Reboot, ohne VersionReg-Fehler.

**Die 4× `atmega=DEAD` sind KEINE echten Tode:** alle mit `up=17..33` (kurz nach Reboot)
und geclustert mit 4 `HEALTH restart` (00:40–00:54). Nach `ESP.restart()` ist
`lastPongMs=0` und `setup()` blockiert bis 25s im `connectWiFi()`, bevor das erste
`PING` rausgeht → HB zeigt zwangsläufig kurz DEAD bis zum ersten PONG. Post-Reboot-Artefakt.

### Nebenbefunde (NICHT der Tür-Ausfall, aber echte Reliability-Themen)
- **Schwaches WiFi: RSSI durchgehend −74…−78 dBm.** → 192× `SLOWLOOP` (Loop-Stall,
  max **10,7 s**!), meist WiFi-Reconnect/DHCP-Blockade im Loop.
- **Server nachts zeitweise weg:** 27× `HEALTH fail`, 4× `HEALTH restart` → ESP hat sich
  4× in 13 Min neu gestartet (00:40–00:54). Reboot hilft nicht, wenn nur der *Server*
  weg ist → Threshold/Logik überdenken (nur bei echtem WiFi-Problem rebooten, nicht bei
  Server-Ausfall). ESP-seitig, per OTA fixbar.
- **Bus-Korruption:** 13 Zeilen mit nicht-druckbaren Bytes (`…??OK`) in LOG00013 → EMV/
  Timing-Glitches auf dem UART (selten, ~0,01%). Gleiche Umwelt-Familie wie der RC522-Tod.
- Kein `MOTOR:TIMEOUT` → Motor unauffällig.
- Max. Uptime **~3,3 Tage am Stück** ohne Reboot → ESP-Firmware grundsätzlich stabil.

### ENTSCHIEDENER Fix (Sub-Fall „alive-but-not-reading")
ATmega-Reflash (vor Ort, USB+DIP), gebündelt:
1. **Unbedingtes volles RC522-Re-Init** periodisch im Idle (nicht nur bei VersionReg
   0x00/0xFF) + **Hard-Reset via RST-Pin** (Pin 5 kurz LOW→HIGH) statt nur Soft-Reset.
2. **Re-Init nach jeder Motorfahrt** (EMV-Quelle Stepper).
3. **Register-Diagnose loggen**: `ATMDBG:RFID ver=.. tx=..` (VersionReg + TxControlReg-
   Antennenbits) periodisch → nächster Ausfall zeigt die Frontend-Register direkt.
4. **ATmega-Selbst-Heartbeat** `ATMDBG:ALIVE n=..`.

Optional ESP-seitig (OTA, ohne Reflash): HEALTH-Restart-Logik entschärfen; WiFi-Signal
am Standort verbessern (−78 dBm ist grenzwertig).

---

## UMGESETZT (2026-07-02) — ATmega-Patch, Build OK

Alle vier Punkte im ATmega (`src_atmega/`), kompiliert sauber
(`pio run -e door_01_atmega_usb` → RAM 25,6 %, Flash 42,6 %). **Noch nicht geflasht.**

1. **`rfidHardReset()`** — Hard-Reset über RST-Pin (Pin 5: LOW→HIGH→50ms) + volles
   `PCD_Init()` (alle Register neu, Antenne an). Gründlicher als der bisherige Soft-Reset.
2. **`pollRFID()`**: alten VersionReg-Check ersetzt durch **unbedingtes `rfidHardReset()`
   alle `RFID_REINIT_INTERVAL_MS` (10s)** → heilt den „alive-but-not-reading"-Fall.
   Max. Tür-Totzeit nach Glitch = 10s (statt ≥1h40m).
3. **Re-Init nach jeder Motorfahrt** in `runOpenDoor()`/`runCloseDoor()` (EMV-Quelle).
4. **`sendAtmegaHeartbeat()`** alle `ATMEGA_HB_INTERVAL_MS` (5s):
   `ATMDBG:ALIVE n=<loops> up=<s> ver=<hex> tx=<hex> [FAULT]` → im SD-Log als
   `[ATM] ALIVE …`. Liveness + RC522-Registerdiagnose. `FAULT` = ver 00/ff oder Antenne aus.

Neue Settings: `RFID_REINIT_INTERVAL_MS=10000`, `ATMEGA_HB_INTERVAL_MS=5000`
(bewusst verschieden, damit der HB die Register auch vor dem Re-Init samplet).

`analyze_log.py` erweitert: eigene Sektion „ATmega-Heartbeat + RC522-Register" —
zeigt ver/tx-Histogramm, listet `FAULT`-Zeilen und ATmega-HB-Lücken.

### Deployment (vor Ort, ATmega ist NICHT OTA)
```bash
# DIP: SW3+SW4 ON (ATmega flashen), Rest OFF
pio run -e door_01_atmega_usb --target upload
# danach DIP zurück auf Normal-Betrieb: SW1+SW2 ON
```
Für Tür 02: `door_02_atmega_usb`.

### Verifikation nach Flash
Im Telnet/SD-Log müssen jetzt regelmäßig `[ATM] ALIVE … ver=91 tx=83`-Zeilen erscheinen
(ver=91/92, tx mit gesetzten Antennenbits). Taucht künftig ein Ausfall auf, zeigt eine
`ALIVE … FAULT`-Zeile den RC522-Registerzustand direkt — dann wissen wir, ob der
Hard-Reset das Frontend nicht heilt (→ Hardware/Power) oder ob es an etwas anderem liegt.

### Status
- **tuer-01: geflasht & verifiziert (2026-07-02)** — Telnet zeigt `[ATM] ALIVE n≈195
  up=.. ver=92 tx=83` alle 5s, kein FAULT, atmega=OK. RC522 gesund, Heartbeat +
  10s-Re-Init laufen. Baseline `n≈195` Loops/5s = gesunder Idle.
- **tuer-02: noch flashen.**

### Offen / später
- Bewährungsprobe: ob der Ausfall jetzt ausbleibt. Falls doch → `ALIVE … FAULT`-Zeile
  im Log zeigt den RC522-Registerzustand direkt.
- ESP-seitig per OTA: HEALTH-Restart entschärfen (nicht rebooten, wenn nur der Server
  weg ist), WiFi-Signal am Standort verbessern (−78 dBm).

## Maßnahmen, priorisiert

### 1. Sofort, ESP-only, per OTA (kein Reflash) — Observability
- `OK→DEAD`-Übergang als eigenes getimestamptes Event loggen
  („ATMEGA DEAD, letztes PONG vor X s") statt nur als HB-Feld → exakter Ausfallzeitpunkt.
- Rohe, nicht-gematchte ATmega-Zeilen mitloggen statt verwerfen
  (aktuell still verworfen in `processSerial()`, [src_esp/main.cpp:243](src_esp/main.cpp#L243))
  → Bus-Korruption wird sichtbar.
- Deploy: `pio run -e door_01_esp_ota --target upload`
- **Status: noch nicht umgesetzt** (Claude kann das schreiben, wenn gewünscht).

### 2. Messlücke physisch schließen
- Zusätzlich die **ATmega-TX-Leitung** in den Logger abgreifen (Y-Split / 2. Logger).
- Erst damit lässt sich „hängt vs. Draht tot" hardwareseitig trennen
  (Originalworte des ATmega statt nur ESP-Echo).

### 3. ATmega-Selbst-Heartbeat (braucht EINEN Reflash vor Ort)
- `ATMDBG:ALIVE n=<loopcount> up=<ms>` alle ~2 s → „loopt noch" direkt sichtbar,
  trennt A/B sofort.
- Gleichzeitig RC522-Recovery härten: voller Power-Down/Reset statt nur `PCD_Init()`,
  und gelesenen `VersionReg`-Wert mitloggen (Degradation sichtbar).
- Lohnt sich, da Fehler trotz RC522-Healthcheck wiederkam → ein letzter ATmega-Flash.

### 4. Strukturelle Lücke: ESP kann toten ATmega nicht heilen
- ESP **erkennt** `atmega=DEAD`, tut aber nichts. Ein ATmega, der seinen eigenen
  4-s-WDT verhungern lässt, ist remote nicht heilbar.
- Saubere Lösung: **ESP-GPIO → ATmega-RESET** verdrahten (kleine Drahtbrücke;
  ab Werk nicht vorhanden, DIP-Schalter routen nur TXD0/RXD0).
  Dann kann der ESP bei `atmega=DEAD` automatisch hart resetten.
- Das ist die zu treffende Architektur-Entscheidung für echte Selbstheilung.

## Hängt-Kandidaten ATmega (falls Bild A)

- **RC522/SPI-Wedge** (#1 Verdacht): Library-Calls blockieren meist nicht, sondern
  geben `false` → ATmega loopt weiter → wäre eher Bild B. Aber wedged Bus + ggf. Hang.
- **Brownout durch Motorstrom** → Reset (`BOOT reason=BOD`). Wenn Reflexion fehlt = Link-Problem.
- `runCloseDoor()` Reed-Wartung bis 30 s ([src_atmega/main.cpp:290](src_atmega/main.cpp#L290))
  — blockiert, aber mit Timeout; kein Dauer-Hang.
- 64-Byte-UART-RX-Überlauf, wenn ATmega lange blockiert (ESP spammt PING/HB/DBG)
  → verlorene/korrupte Bytes; meist benigne, aber Bus-Korruption möglich.

## Nächster konkreter Schritt

1. **Log auswerten** (Schritt 0) → Bild A oder B festhalten.
2. Je nach Ergebnis: RC522 härten (B) oder ATmega-Hang/Reset jagen (A).
3. Parallel kann Punkt 1 (ESP-Log-Verbesserungen, OTA) sofort umgesetzt werden.

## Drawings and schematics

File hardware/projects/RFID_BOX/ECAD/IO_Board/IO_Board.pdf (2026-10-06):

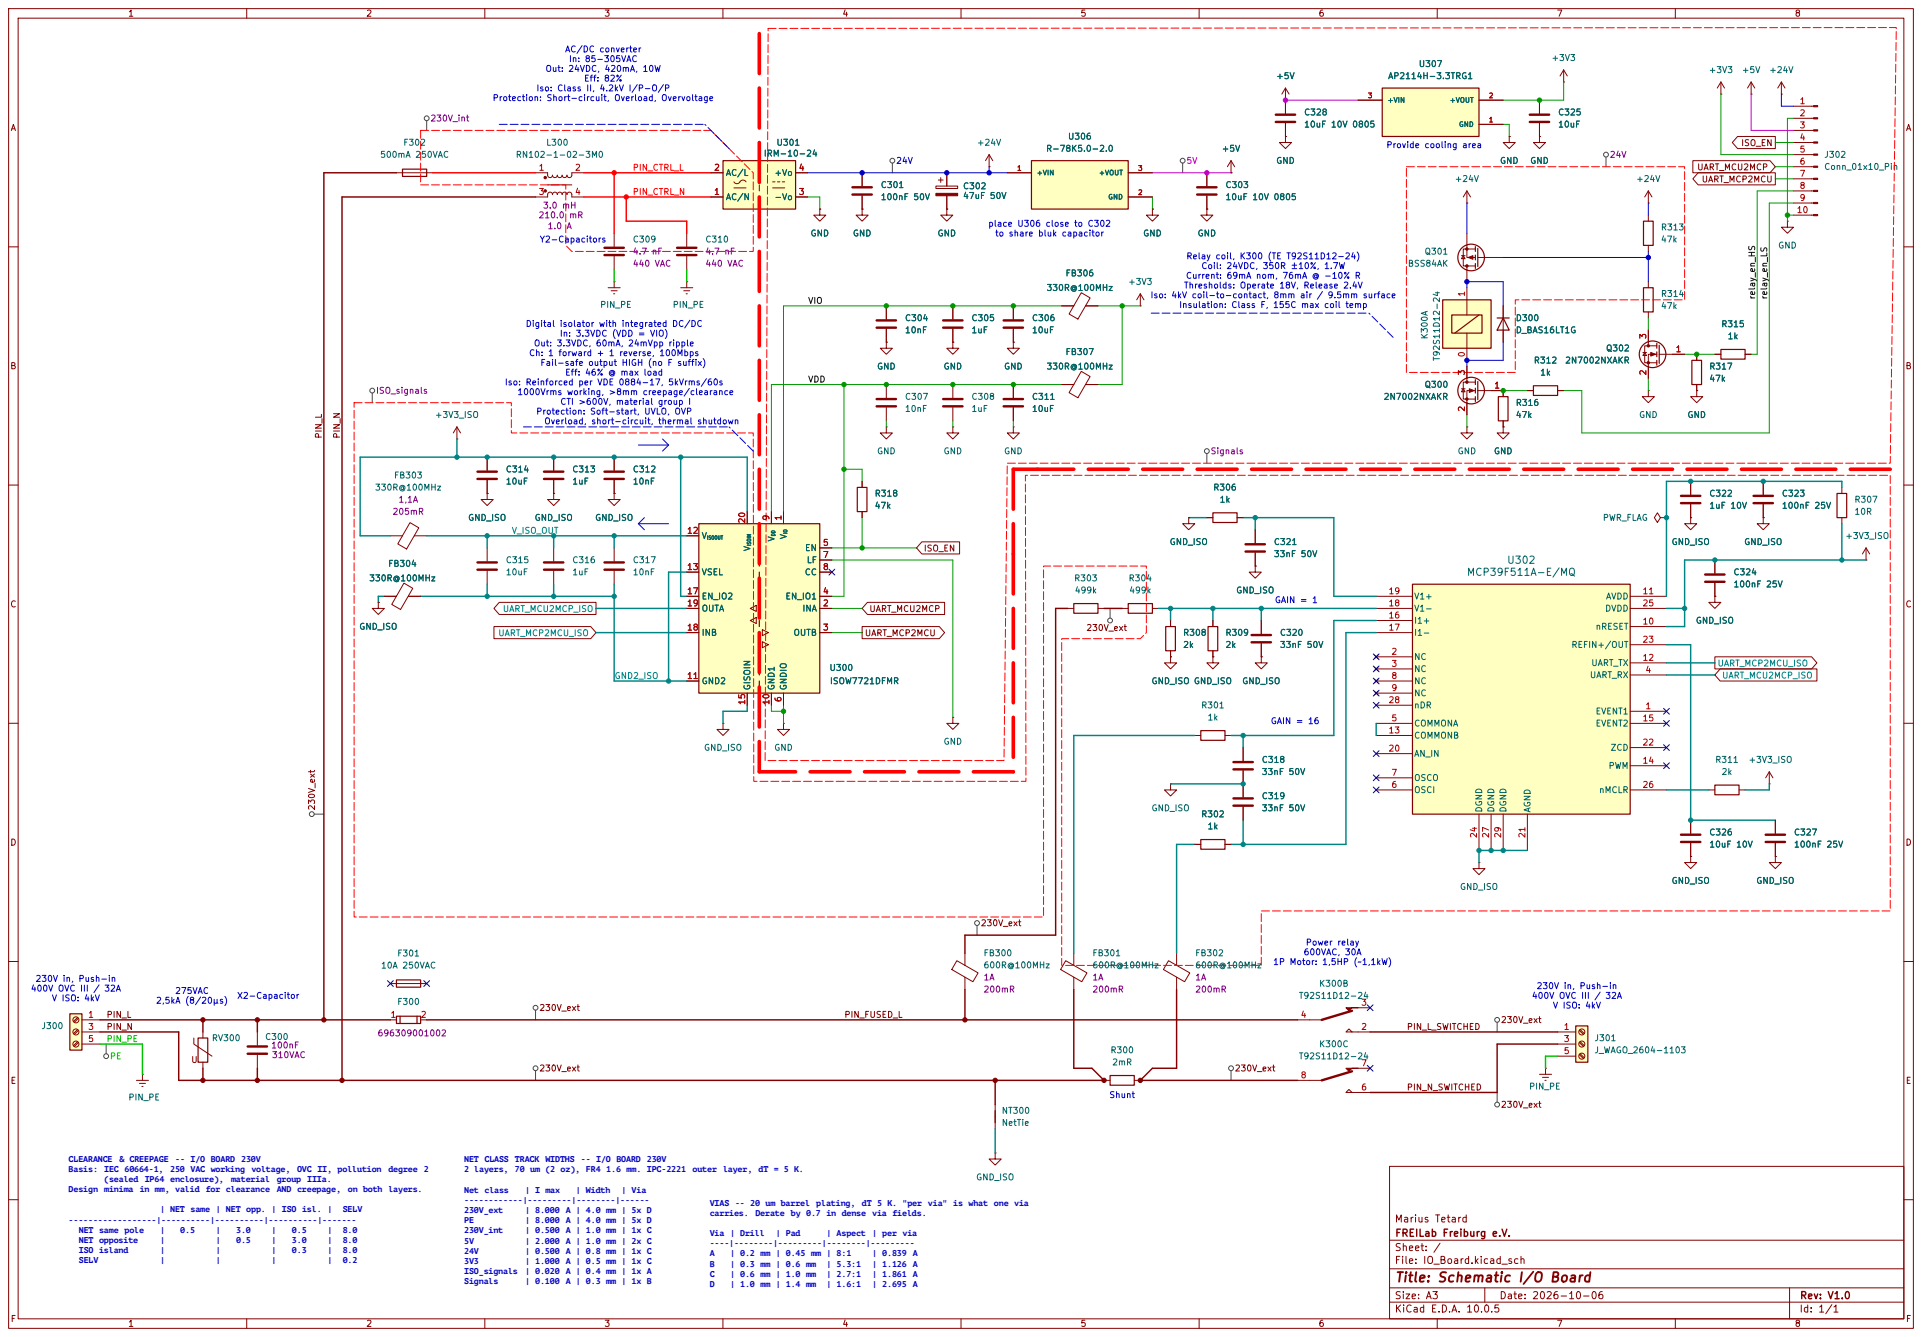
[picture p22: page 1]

place U306 close to C302
to share bluk capacitor

Iso: 4kV coil-to-contact, 8mm air / 9.5mm surface

Insulation: Class F, 155C max coil temp

Digital isolator with integrated DC/DC
In: 3.3VDC (VDD = VIO) Out: 3.3VDC, 60mA, 24mVpp ripple Ch: 1 forward + 1 reverse, 100Mbps Fail-safe output HIGH (no F suffix) Eff: 46% @ max load
ISO_signals 230V_ext

230V in, Push-in 400V OVC III / 32A

CLEARANCE & CREEPAGE -- I/O BOARD 230V
Basis: IEC 60664-1, 250 VAC working voltage, OVC II, pollution degree 2

NET CLASS TRACK WIDTHS -- I/O BOARD 230V
2 layers, 70 um (2 oz), FR4 1.6 mm. IPC-2221 outer layer, dT = 5 K.

(sealed IP64 enclosure), material group IIIa.

Design minima in mm, valid for clearance AND creepage, on both layers.

VIAS -- 20 um barrel plating, dT 5 K. "per via" is what one via
carries. Derate by 0.7 in dense via fields.

NET same | NET opp. | ISO isl. | SELV

Size: A3 | Rev: V1.0 | F Date: 2026-10-06
KiCad E.D.A. 10.0.5 | Id: 1/1

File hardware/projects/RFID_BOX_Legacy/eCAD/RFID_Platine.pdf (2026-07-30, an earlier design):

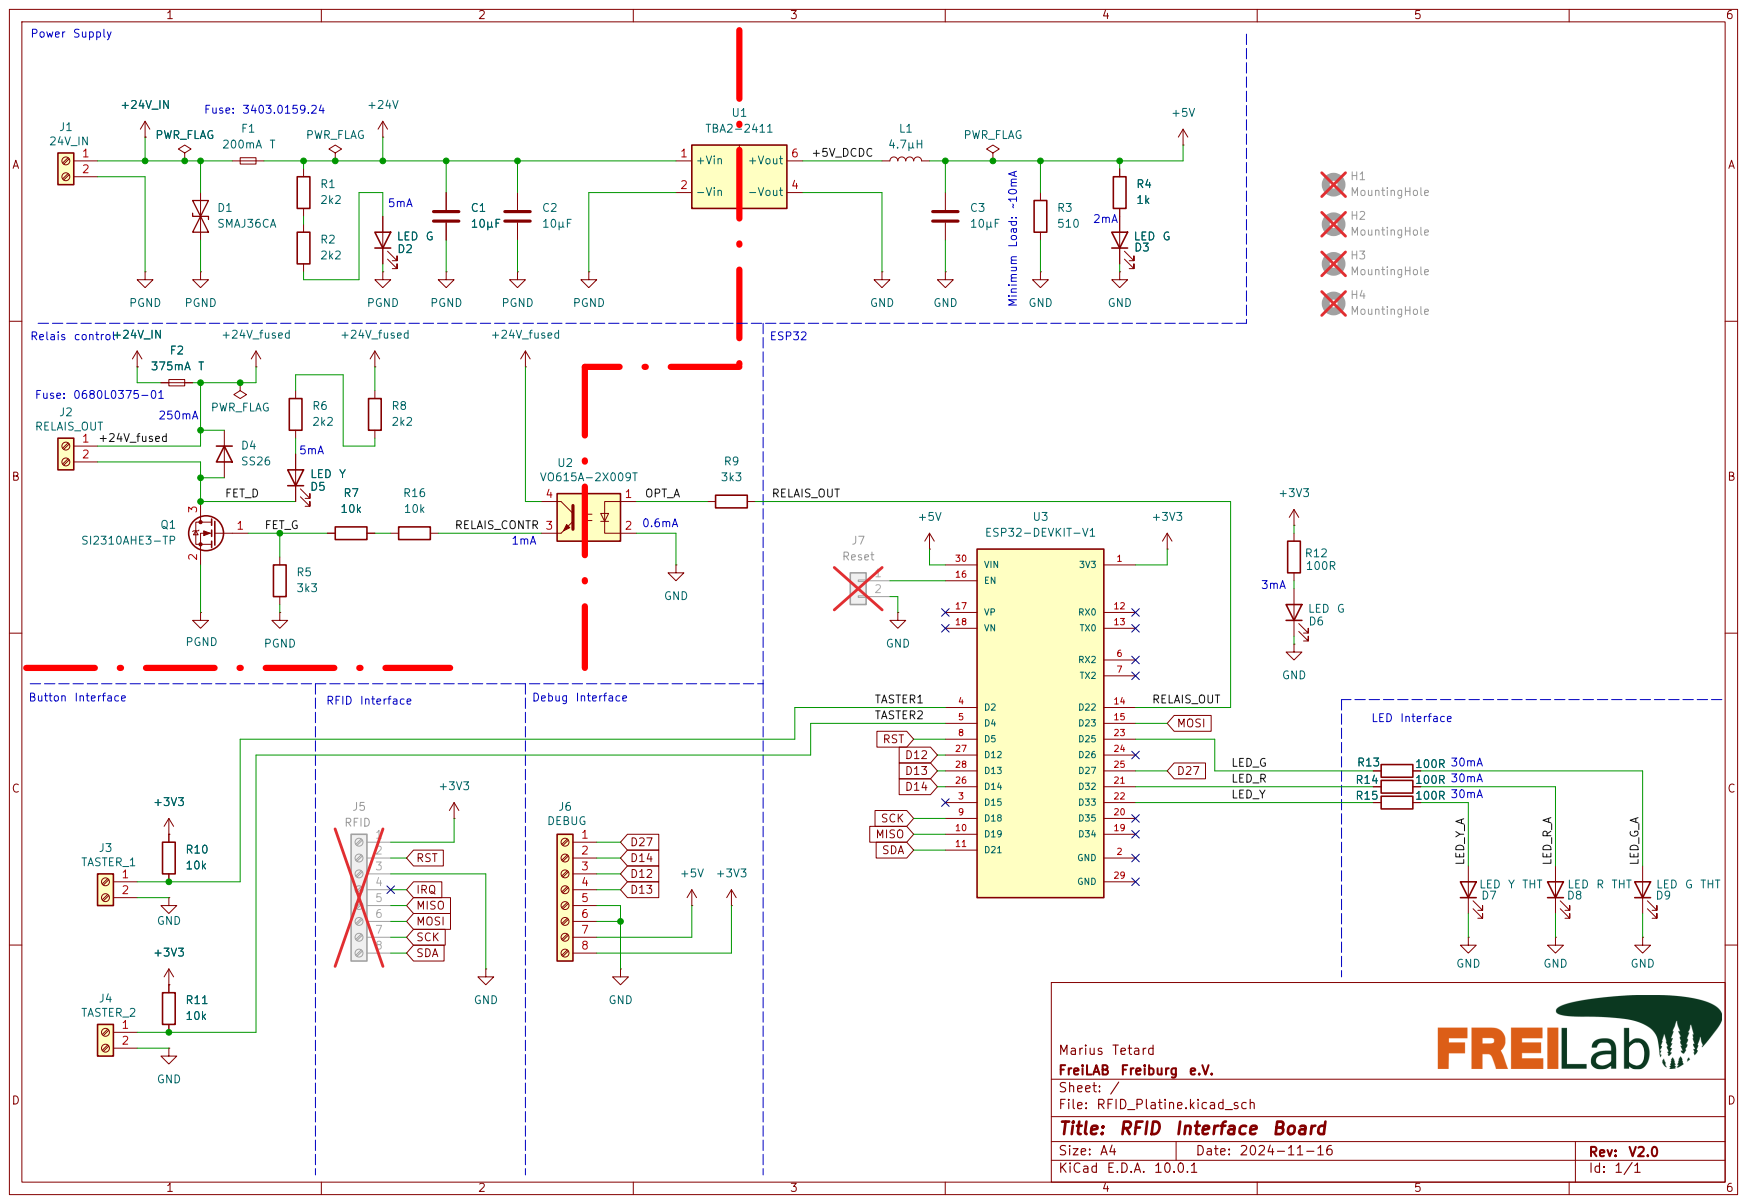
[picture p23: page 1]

Marius Tetard
FreiLAB Freiburg e.V.
Sheet: /
File: RFID_Platine.kicad_sch
Title: RFID Interface Board

Size: A4 | Rev: V2.0
KiCad E.D.A. 10.0.1 | Id: 1/1

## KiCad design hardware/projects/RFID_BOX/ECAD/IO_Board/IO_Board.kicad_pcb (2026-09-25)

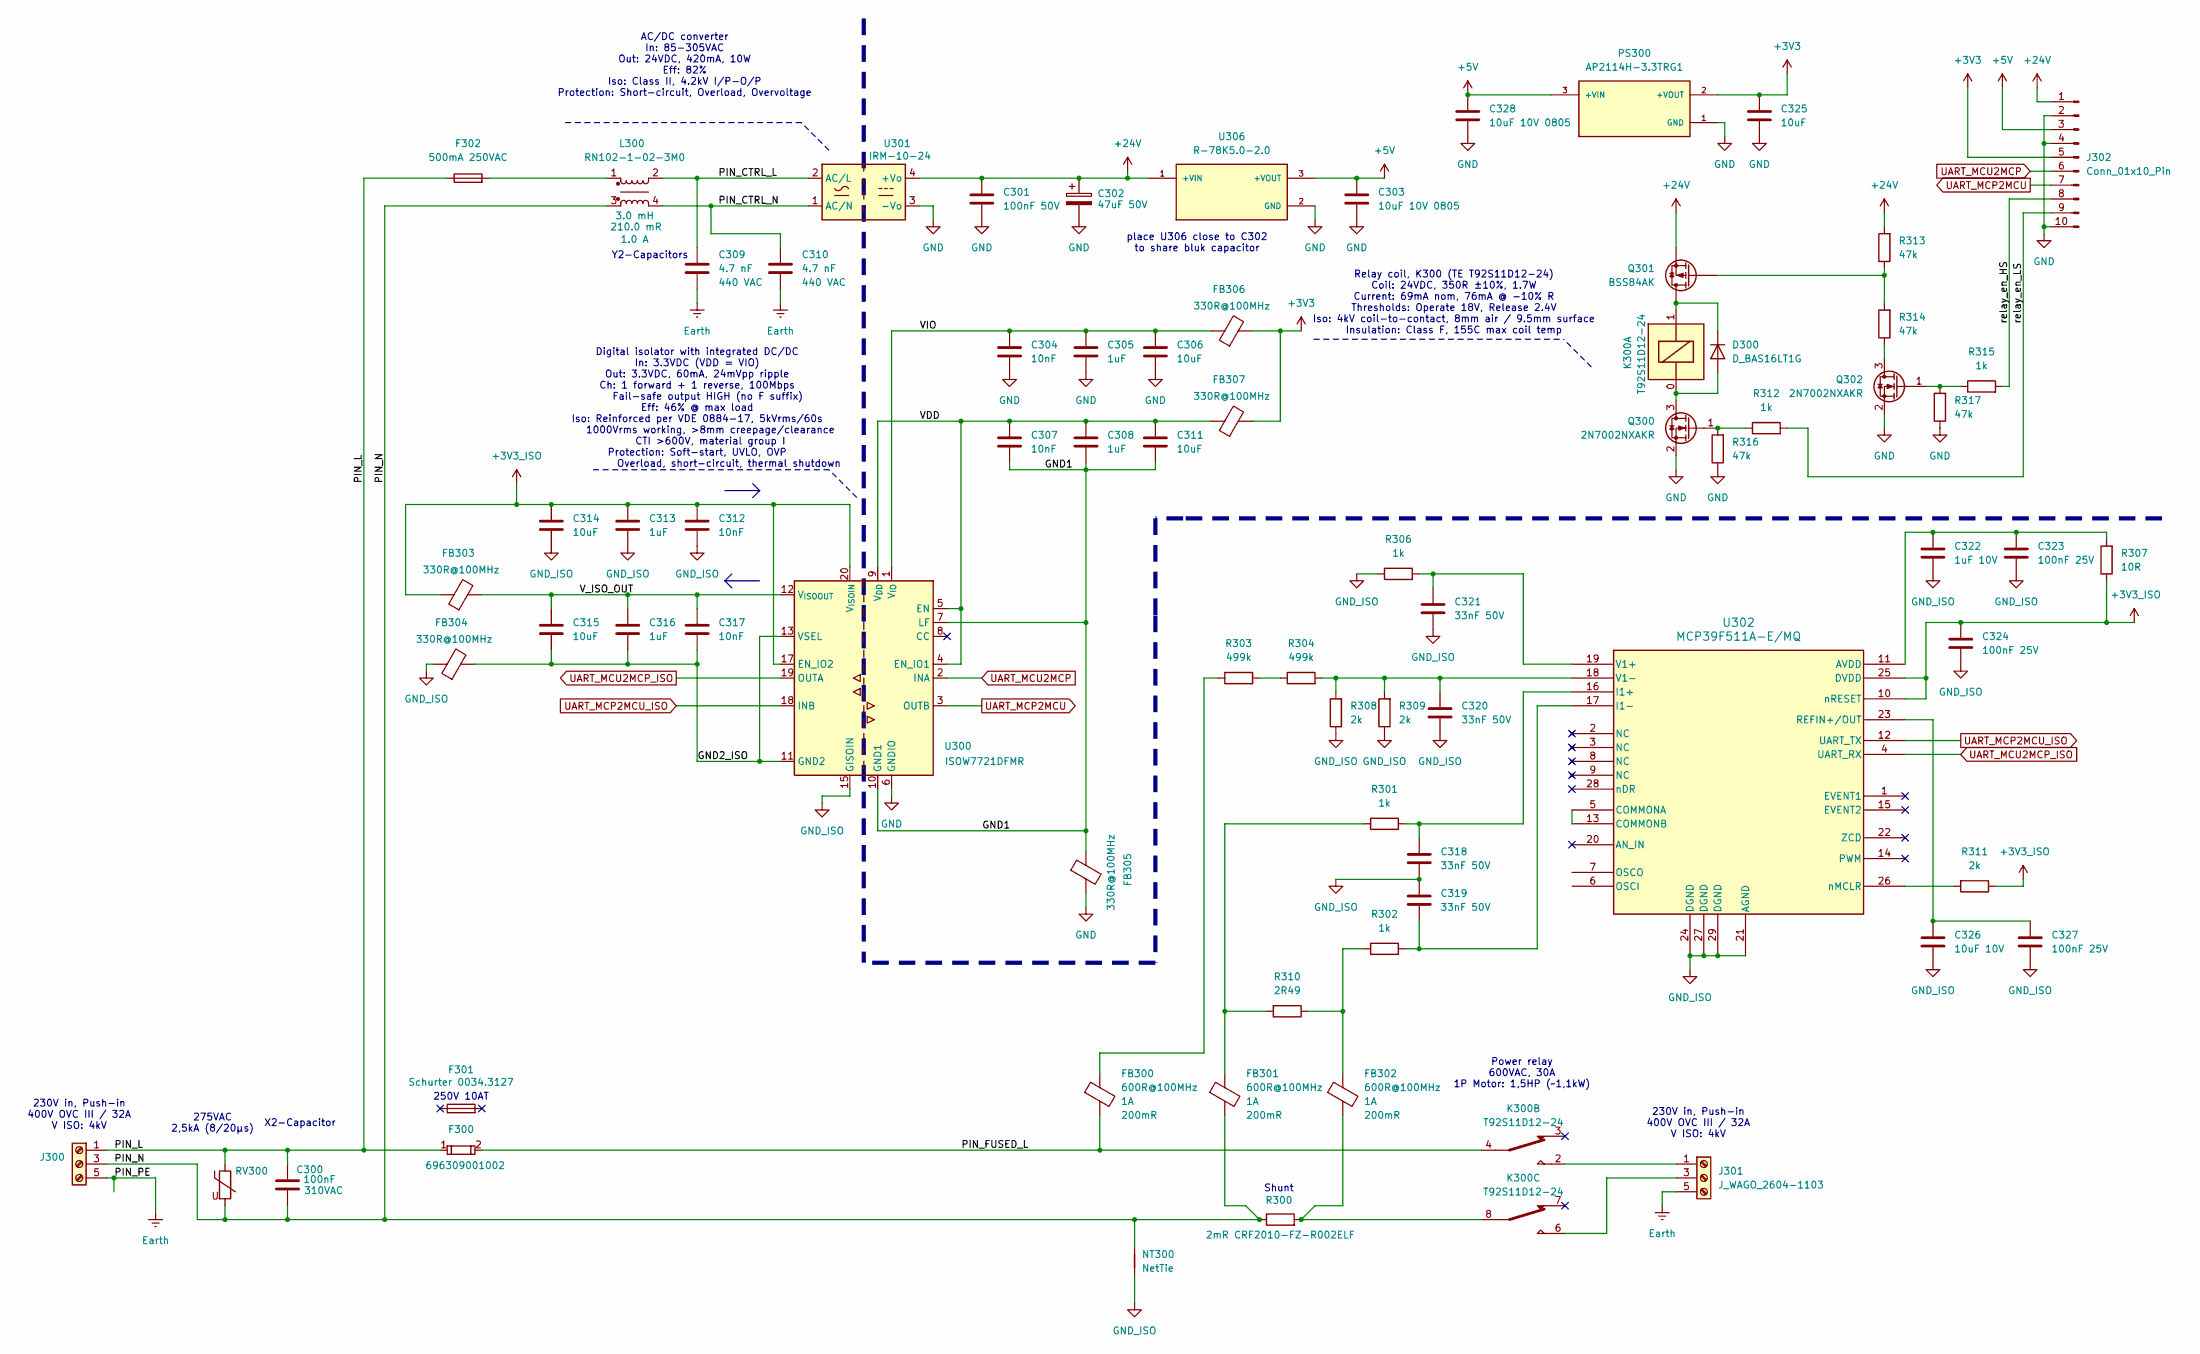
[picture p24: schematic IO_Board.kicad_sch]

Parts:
C300: C_X2_890334023023CS; C_Wurth_WCAP-FTXX-P10L13W7H13; Voltage 310VAC; Manufacturer Part Number 890334023023CS
C301: 100nF 50V; C_0603_1608Metric
C302: 47uF 50V; CP_Radial_D6.3mm_H11.0mm_P2.50mm; Manufacturer Part Number 860010673012
C303, C328: 10uF 10V 0805; C_0805_2012Metric
C304, C307, C312, C317: 10nF; C_0603_1608Metric
C305, C308, C313, C316: 1uF; C_0603_1608Metric
C306, C311, C314, C315, C325: 10uF; C_0603_1608Metric
C309, C310: VY2472M49Y5US63L7; C_Disc_D12.5mm_W5.0mm_P7.50mm; Voltage 440 VAC; Manufacturer Part Number VY2472M49Y5US63L7
C318, C319, C320, C321: 33nF 50V; C_0603_1608Metric
C322: 1uF 10V; C_0603_1608Metric
C323, C324, C327: 100nF 25V; C_0603_1608Metric
C326: 10uF 10V; C_0805_2012Metric
D300: D_BAS16LT1G; SOT-23; Manufacturer Part Number BAS16LT1G
F300: F_696309001002; F_Wurth_WR-FSH_696309001002; Part Number 696309001002
F301: Schurter 0034.3127
F302: 500mA 250VAC; F_MRT_BEL; Manufacturer Part Number MRT 500-BULK
FB300, FB301, FB302: 600R@100MHz; L_0805_2012Metric; Manufacturer Part Number MH2029-601Y
FB303, FB304, FB305, FB306, FB307: 330R@100MHz; L_0805_2012Metric; Manufacturer Part Number MH2029-601Y
J300, J301: J_WAGO_2604-1103; J_2604-1103_WAG; Manufacturer Part Number 2604-1103
J302: Conn_01x10_Pin
K300: T92S11D12-24; K_T92S11D12-24; Manufacturer Part Number T92S11D12-24
L300: RN102-1-02-3M0; L_RN102_SCN; Part Number RN102-1-02-3M0
NT300: NetTie; NetTie-2_SMD_Pad0.5mm
PS300: AP2114H-3.3TRG1; SOT-223-3_TabPin2; Manufacturer Part Number AP2114H-3.3TRG1
Q300, Q302: 2N7002NXAKR; SOT-23; Manufacturer Part Number 2N7002NXAKR
Q301: BSS84AK; SOT-23; Manufacturer Part Number BSS84AK,215
R300: 2mR CRF2010-FZ-R002ELF; R_2010_5025Metric
R301, R302, R306, R312, R315: 1k; R_0603_1608Metric
R303, R304: 499k; R_2010_5025Metric
R307: 10R; R_0603_1608Metric
R308, R309, R311: 2k; R_0603_1608Metric
R310: 2R49; R_0603_1608Metric
R313, R314, R316, R317: 47k; R_0603_1608Metric
RV300: RVAR_B72210S0271K101; RV_Disc_D12mm_W5.1mm_P7.5mm; Manufacturer Part Number B72210S0271K101
U300: ISOW7721DFMR; SOIC-20W_7.5x12.8mm_P1.27mm; Manufacturer Part Number ISOW7721DFMR
U301: IRM-10-24; IC_IRM-10-24_THT; Manufacturer Part Number IRM-10-24
U302: MCP39F511A-E/MQ; IC_QFN28_MQ_MCH; Manufacturer Part Number MCP39F511A-E/MQ
U306: R-78K5.0-2.0; IC_CONV_R-78K5.0-2.0; PARTREV 0/2023

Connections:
+3V3: C325.1, FB306.2, FB307.2, J302.5, PS300.2 (+VOUT)
+3V3_ISO: C312.1, C313.1, C314.1, C324.1, FB303.1, R307.1, R311.1, U300.17 (EN_IO2), U300.20 (V_{ISOIN}), U302.10 (nRESET), U302.25 (DVDD)
+5V: C303.1, C328.1, J302.3, PS300.3 (+VIN), U306.3 (+VOUT)
+24V: C301.1, C302.1, J302.1, Q301.2 (S), R313.2, U301.4 (+Vo), U306.1 (+VIN)
/GND1: C307.2, C308.2, C311.2, FB305.1, U300.7 (LF), U300.10 (GND1)
/GND2_ISO: C315.2, C316.2, C317.2, FB304.2, U300.11 (GND2), U300.13 (VSEL)
/PIN_CTRL_L: C309.1, L300.2, U301.2 (AC/L)
/PIN_CTRL_N: C310.1, L300.4, U301.1 (AC/N)
/PIN_FUSED_L: F300.2, FB300.2, K300.4
/PIN_L: C300.1, F300.1, F302.1, J300.1, J300.2, RV300.1
/PIN_N: C300.2, FB301.2, J300.3, J300.4, L300.3, NT300.2, R300.1, RV300.2
/VDD: C307.1, C308.1, C311.1, FB307.1, U300.4 (EN_IO1), U300.5 (EN), U300.9 (V_{DD})
/VIO: C304.1, C305.1, C306.1, FB306.1, U300.1 (V_{IO})
/V_ISO_OUT: C315.1, C316.1, C317.1, FB303.2, U300.12 (V_{ISOOUT})
Earth: C309.2, C310.2, J300.5, J300.6, J301.5, J301.6
GND: C301.2, C302.2, C303.2, C304.2, C305.2, C306.2, C325.2, C328.2, FB305.2, J302.2, J302.4, J302.10, PS300.1 (GND), Q300.2 (S), Q302.2 (S), R316.1, R317.1, U300.6 (GNDIO), U301.3 (-Vo), U306.2 (GND)
GND_ISO: C312.2, C313.2, C314.2, C318.2, C319.1, C320.2, C321.2, C322.2, C323.2, C324.2, C326.2, C327.2, FB304.1, NT300.1, R306.1, R308.1, R309.1, U300.15 (GISOIN), U302.21 (AGND), U302.24 (DGND), U302.27 (DGND), U302.29 (DGND)
unnamed: D300.1 (A), K300.0, Q300.3 (D)
unnamed: D300.3 (K), K300.1, Q301.3 (D)
unnamed: F302.2, L300.1
unnamed: FB300.1, R303.1
unnamed: FB301.1, R301.1, R310.2
unnamed: FB302.1, R302.1, R310.1
unnamed: FB302.2, K300.8, R300.2
unnamed: J301.1, J301.2, K300.2
unnamed: J301.3, J301.4, K300.6
unnamed: J302.8, R315.2
unnamed: J302.9, R312.2
unnamed: Q300.1 (G), R312.1, R316.2
unnamed: Q301.1 (G), R313.1, R314.2
unnamed: Q302.3 (D), R314.1
unnamed: Q302.1 (G), R315.1, R317.2
unnamed: R303.2, R304.1
unnamed: C322.1, C323.1, R307.2, U302.11 (AVDD)
unnamed: U302.5 (COMMONA), U302.13 (COMMONB)
unnamed: C318.1, R301.2, U302.16 (I1+)
unnamed: C319.2, R302.2, U302.17 (I1-)
unnamed: C326.1, C327.1, U302.23 (REFIN+/OUT)
unnamed: C321.1, R306.2, U302.19 (V1+)
unnamed: C320.1, R304.2, R308.2, R309.2, U302.18 (V1-)
unnamed: R311.2, U302.26 (nMCLR)
UART_MCP2MCU: J302.7, U300.3 (OUTB)
UART_MCP2MCU_ISO: U300.18 (INB), U302.12 (UART_TX)
UART_MCU2MCP: J302.6, U300.2 (INA)
UART_MCU2MCP_ISO: U300.19 (OUTA), U302.4 (UART_RX)

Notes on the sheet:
230V in, Push-in 400V OVC III / 32A V ISO: 4kV
place U306 close to C302 to share bluk capacitor
Y2-Capacitors
AC/DC converter In: 85-305VAC Out: 24VDC, 420mA, 10W Eff: 82% Iso: Class II, 4.2kV I/P-O/P Protection: Short-circuit, Overload, Overvoltage
Power relay 600VAC, 30A 1P Motor: 1,5HP (~1,1kW)
Digital isolator with integrated DC/DC In: 3.3VDC (VDD = VIO) Out: 3.3VDC, 60mA, 24mVpp ripple Ch: 1 forward + 1 reverse, 100Mbps Fail-safe output HIGH (no F suffix) Eff: 46% @ max load Iso: Reinforced per VDE 0884-17, 5kVrms/60s 1000Vrms working, >8mm creepage/clearance CTI >600V, material group I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
275VAC 2,5kA (8/20µs)
Relay coil, K300 (TE T92S11D12-24) Coil: 24VDC, 350R ±10%, 1.7W Current: 69mA nom, 76mA @ -10% R Thresholds: Operate 18V, Release 2.4V Iso: 4kV coil-to-contact, 8mm air / 9.5mm surface Insulation: Class F, 155C max coil temp
Shunt
250V 10AT
X2-Capacitor

Board: 2 copper layers, 71 parts (0 on the bottom side), 41 nets, no tracks yet.

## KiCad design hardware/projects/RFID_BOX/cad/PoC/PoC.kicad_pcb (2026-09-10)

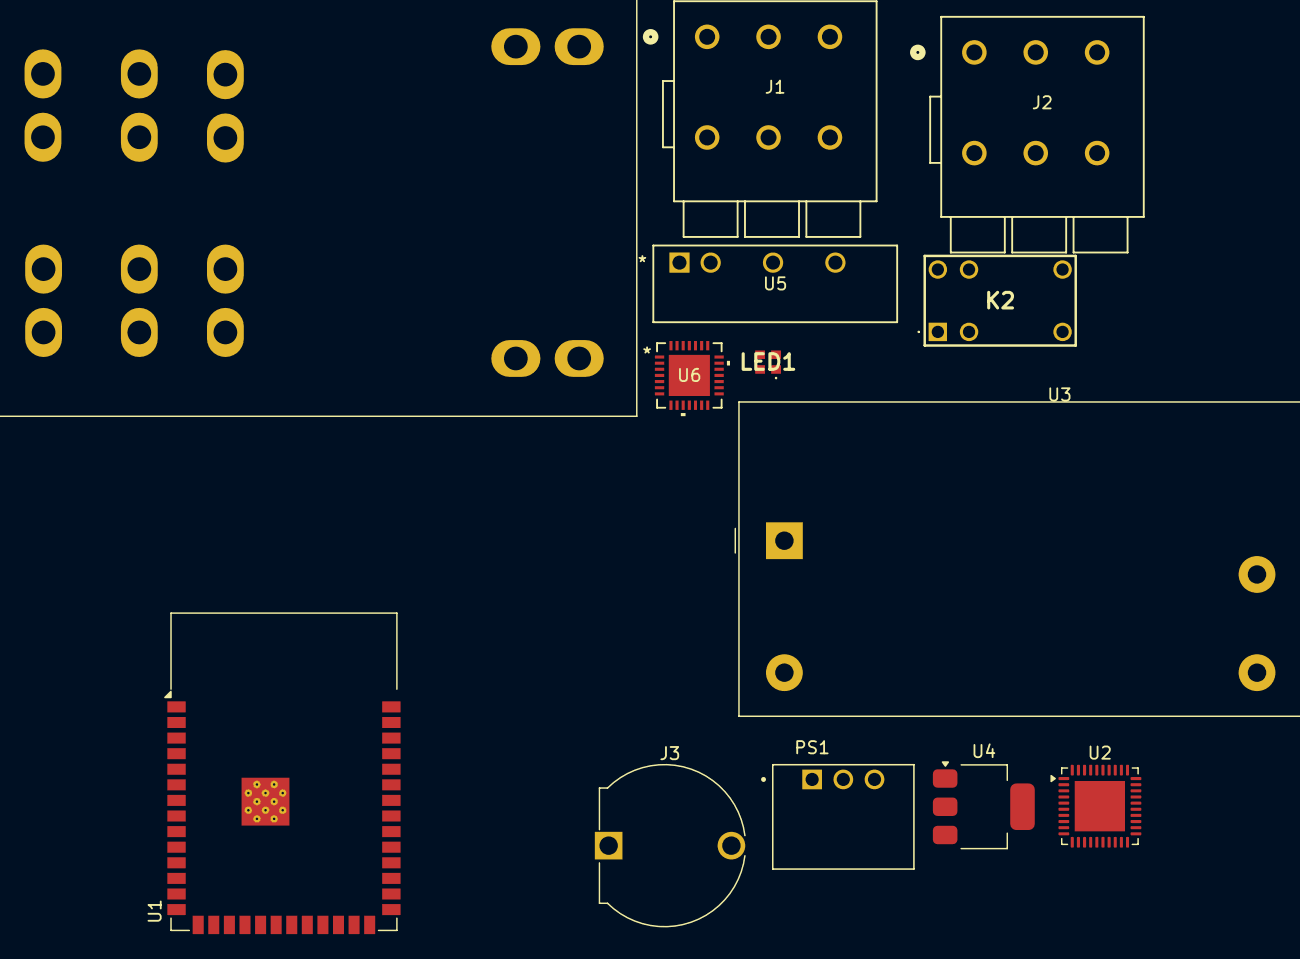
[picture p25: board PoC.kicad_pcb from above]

Board: 2 copper layers, 13 parts (0 on the bottom side), 9 nets, no tracks yet.

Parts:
J1, J2: J_WAGO_2604-1103; J_2604-1103_WAG
J3: F_696309001002; F_Wurth_WR-FSH_696309001002
K1: T92S11D12-24; K_T92S11D12-24
K2: K_G5V-1-2_DC24
LED1: LED_IN-PI20TATPRPGPB; LED_INPI20TATPRPGPB
PS1: IC_R-78K5.0-2.0; IC_CONV_R-78K5.0-2.0
U1: ESP32-S3-WROOM-1
U2: PN5321A3HN_C1xx; HVQFN-40-1EP_6x6mm_P0.5mm_EP4.1x4.1mm
U3: IC_IRM-10-24; IC_IRM-10-24_THT
U4: AMS1117-3.3; SOT-223-3_TabPin2
U5: IC_RFB-0505S
U6: MCP39F511A-E/MQ; IC_QFN28_MQ_MCH

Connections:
unnamed: J1.1, J1.2
unnamed: J1.3, J1.4
unnamed: J1.5, J1.6
unnamed: J2.1, J2.2
unnamed: J2.3, J2.4
unnamed: J2.5, J2.6
unnamed: K2.5, K2.6
unnamed: U1.1 (GND), U1.40 (GND), U1.41 (GND)
unnamed: U2.11 (AVSS), U2.41 (AVSS)

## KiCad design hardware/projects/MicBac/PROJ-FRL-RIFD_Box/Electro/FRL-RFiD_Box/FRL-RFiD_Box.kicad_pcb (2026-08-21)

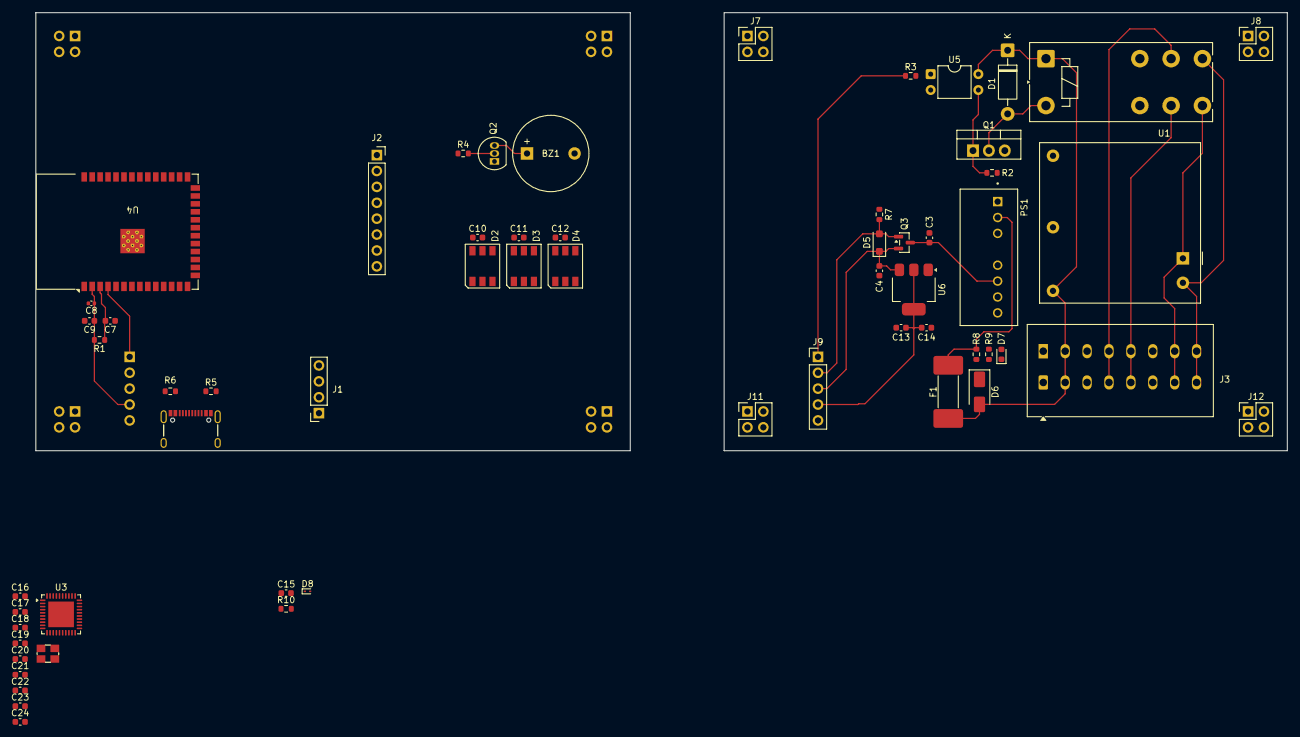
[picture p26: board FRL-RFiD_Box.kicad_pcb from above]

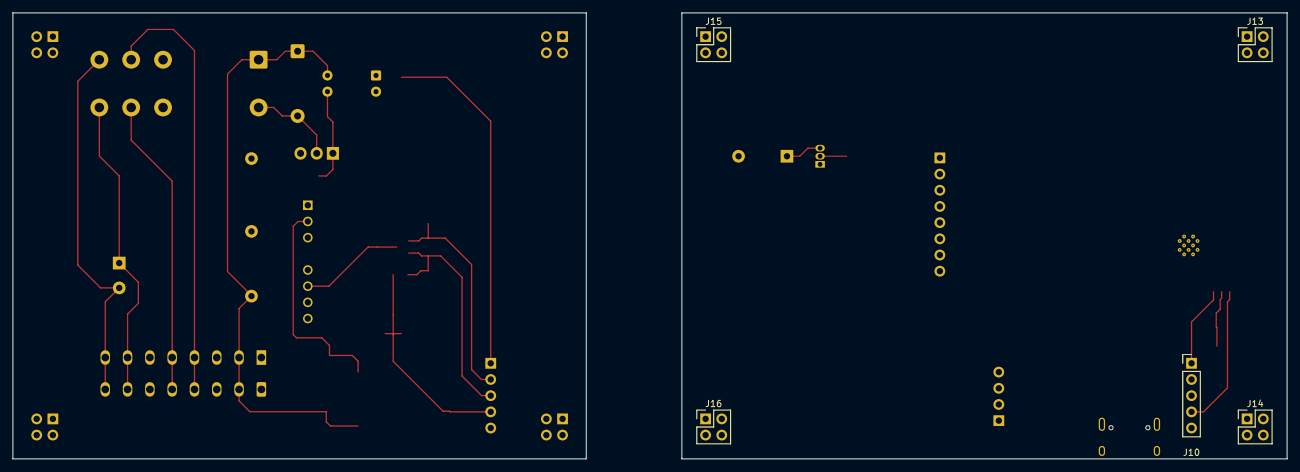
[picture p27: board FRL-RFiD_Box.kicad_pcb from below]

Board: 2 copper layers, 200.0 x 70.0 mm, 65 parts (5 on the bottom side), 44 nets.

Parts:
BZ1: TMB12A05; Buzzer_12x9.5RM7.6
C3, C4, C9, C16, C19: 10u; C_0603_1608Metric
C7, C15: 1u; C_0603_1608Metric
C8: 0.1u; C_0402_1005Metric
C10, C11, C12: 0.1uF; C_0603_1608Metric
C13: 22u Tantal or Elko; C_0603_1608Metric
C14, C17, C18, C20, C21: 100n; C_0603_1608Metric
C22: 4,7u; C_0603_1608Metric
C23, C24: 22p; C_0603_1608Metric
D1: 1N4007; D_DO-41_SOD81_P10.16mm_Horizontal
D2, D3, D4: WS2812; LED_WS2812_PLCC6_5.0x5.0mm_P1.6mm
D5: MBR120VLSF; D_SOD-123F
D6: SMAJ36CA; D_SMA
D7: LED G; LED_0603_1608Metric
D8: ESD9B3.3ST5G; D_SOD-923
F1: 200mA T; Fuse_Schurter_UMZ250
J1: I2C_OLED; PinSocket_1x04_P2.54mm_Vertical
J2: SPI_NFC; PinSocket_1x08_P2.54mm_Vertical
J3: WAGO (230V + 24V); TerminalBlock_WAGO_2601-1108_1x08_P3.50mm_Horizontal
J5: USB_C_Receptacle; USB-C_16
J7, J8, J11, J12, J13, J14, J15, J16: Conn_02x02_Odd_Even; PinHeader_2x02_P2.54mm_Vertical
J9, J10: Conn_01x05; PinHeader_1x05_P2.54mm_Vertical
K1: FINDER-41.52.9.024.4311; Relay_DPDT_Finder_40.52
PS1: RS6-2405S; CONV_RS6-2405S
Q1: IRLZ44N; TO-220-3_Vertical
Q2: BC547; TO-92_Inline
Q3: DMG2305UX; SOT-23
R1, R2, R10: 10k; R_0603_1608Metric
R3: 220; R_0603_1608Metric
R4: 1k; R_0603_1608Metric
R5, R6: 5,1k; R_0603_1608Metric
R7: 22k; R_0603_1608Metric
R8, R9: 2k2; R_0603_1608Metric
U1: RAC05-24SK; Converter_ACDC_RECOM_RAC05-xxSK_THT
U3: PN5321A3HN_C1xx; HVQFN-40-1EP_6x6mm_P0.5mm_EP4.1x4.1mm
U4: ESP32-S3-WROOM-1
U5: PC817; DIP-4_W7.62mm
U6: AMS1117-3.3; SOT-223-3_TabPin2
Y1: 27.12MHz; Crystal_SMD_3.2x2.5mm

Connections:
24_GND: D6.1 (A1), D7.1 (K), J3.1, PS1.1 (-VIN), Q1.3 (S), R2.2, U1.4 (-Vout)
+3V3: C8.1, C9.1, J1.4, J2.5, J10.4, R1.2, R10.2, U4.2 (3V3)
+3V3 Bot: C13.1, C14.1, J9.4, U6.2 (VO)
+5V: C10.2, C11.2, C12.2, D2.3 (VCC), D2.5 (VDD), D3.3 (VCC), D3.5 (VDD), D4.3 (VCC), D4.5 (VDD), J10.3, Q2.1 (C)
+5V Bot: C4.1, D5.1 (K), J9.3, Q3.2 (S), U6.3 (VI)
/230V_AC_FINDER_L (OUT): J3.5, K1.21
/230V_AC_FINDER_N (OUT): J3.4, K1.11
/230V_AC_RAC05_L (IN): J3.7, K1.24, U1.1 (AC(L))
/230V_AC_RAC05_N (IN): J3.8, K1.14, U1.2 (AC(N))
/+5V_RS6-2405S_+VOUT: C3.1, PS1.6 (+VOUT), Q3.3 (D)
/+24V_RAC05_OUT: D1.1 (K), D6.2 (A2), F1.1, J3.2, K1.A1, U1.5 (+Vout), U5.4
/+24V_RS6_+VIN: F1.2, PS1.2 (+VIN), R8.1
/BUZZER: R4.1, U4.33 (IO40)
/EN: C7.1, R1.1, U4.3 (EN)
/ESP_IO_0: C15.1, D8.2 (A2), R10.1, U4.27 (IO0)
/I2C_OLED_SCL: J1.1, U4.17 (IO9)
/I2C_OLED_SDA: J1.2, U4.12 (IO8)
/PC817 (OPT): J10.1, U4.4 (IO4)
/PC817 (OPT) Bot: J9.1, R3.1
/SPI_NFC_IRQ: J2.7, U3.25 (P70_IRQ), U4.18 (IO10)
/SPI_NFC_MISO: J2.2, U3.29 (MISO/P71), U4.21 (IO13)
/SPI_NFC_MOSI: J2.3, U3.28 (MOSI/SDA/HSU_TX), U4.20 (IO12)
/SPI_NFC_SCK: J2.1, U3.30 (SCK/P72), U4.22 (IO14)
/SPI_NFC_SS: J2.4, U3.27 (NSS/P50_SCL/HSU_RX), U4.19 (IO11)
/USB_CC1: J5.A5 (CC1), R6.1
/USB_CC2: J5.B5 (CC2), R5.1
/USB_D+: J5.A6 (D+), J5.B6 (D+), U4.14 (USB_D+)
/USB_D-: J5.A7 (D-), J5.B7 (D-), U4.13 (USB_D-)
/VBUS: C16.1, J5.VBUS, J10.2
/VBUS Bot: D5.2 (A), J9.2, Q3.1 (G), R7.1
/WS2812: D2.2 (DIN), U4.5 (IO5)
GND: BZ1.2 (-), C3.2, C4.2, C7.2, C8.2, C9.2, C10.1, C11.1, C12.1, C13.2, C14.2, C15.2, C16.2, C17.2, C18.2, C19.2, C20.2, C21.2, C22.2, C23.2, C24.2, D2.6 (VSS), D3.6 (VSS), D4.6 (VSS), D8.1 (A1), J1.3, J2.6, J5.GND, J5.S (SHIELD), J9.5, J10.5, PS1.7 (-VOUT), R5.2, R6.2, R7.2, U3.1 (DVSS), U3.3 (TVSS1), U3.7 (TVSS2), U3.11 (AVSS), U3.18 (TESTEN), U3.41 (AVSS), U4.1 (GND), U4.40 (GND), U4.41 (GND), U5.2, U6.1 (GND)
unnamed: BZ1.1 (+), Q2.3 (E)
unnamed: D1.2 (A), K1.A2, Q1.2 (D)
unnamed: D2.1 (DOUT), D3.2 (DIN)
unnamed: D3.1 (DOUT), D4.2 (DIN)
unnamed: D7.2 (A), R9.2
unnamed: Q1.1 (G), R2.1, U5.3
unnamed: Q2.2 (B), R4.2
unnamed: R3.2, U5.1
unnamed: R8.2, R9.1
unnamed: C17.1, C18.1, C19.1, C20.1, C21.1, C22.1, U3.5 (TVDD), U3.8 (AVDD), U3.23 (PVDD), U3.39 (DVDD)
unnamed: C23.1, U3.14 (OSCIN), Y1.1
unnamed: C24.1, U3.15 (OSCOUT), Y1.2

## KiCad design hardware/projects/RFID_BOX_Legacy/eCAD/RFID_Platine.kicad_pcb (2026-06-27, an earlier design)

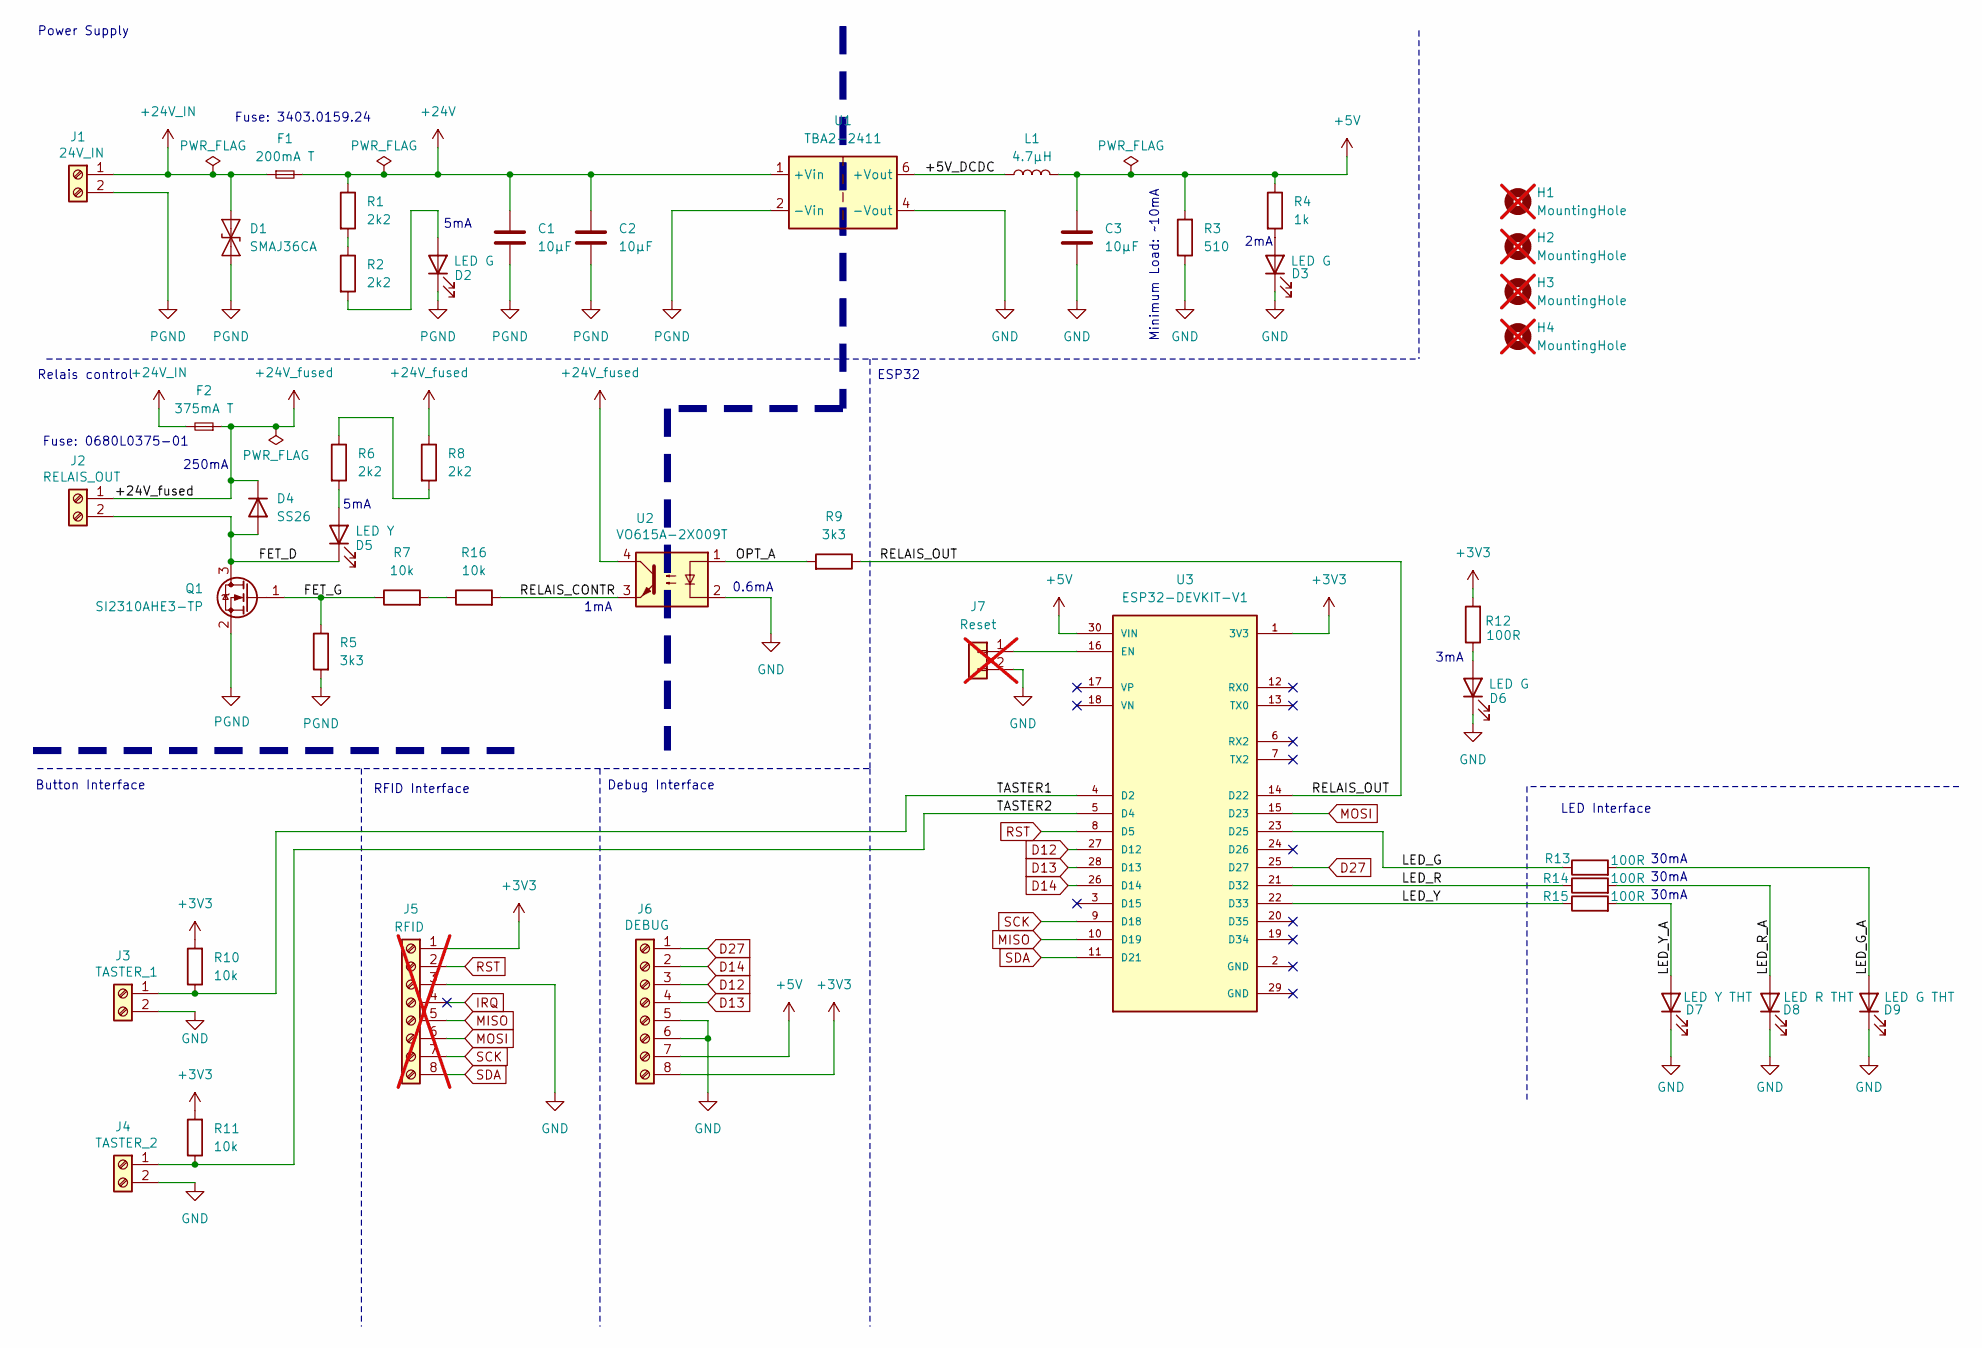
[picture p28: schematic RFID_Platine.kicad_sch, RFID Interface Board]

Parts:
C1, C2, C3: 10µF; C_0805_2012Metric; Voltage Rating 50V; Digikey 490-GRM21BR61H106KE43KCT-ND
D1: SMAJ36CA; D_SMA; Digikey SMAJ36CA-TPMSCT-ND
D2, D3, D6: LED G; LED_0603_1608Metric; Digikey 160-1183-1-ND
D4: SS26; D_SMA; Digikey SS26-LTPMSCT-ND
D5: LED Y; LED_0603_1608Metric; Digikey 160-1448-1-ND
D7: LED Y THT; LED_D5.0mm_Horizontal_O6.35mm_Z15.0mm; Digikey 1516-1362-ND
D8: LED R THT; LED_D5.0mm_Horizontal_O6.35mm_Z15.0mm; Digikey 1516-1359-ND
D9: LED G THT; LED_D5.0mm_Horizontal_O6.35mm_Z15.0mm; Digikey 1516-1364-ND
F1: 200mA T; Fuse_Schurter_UMZ250; Digikey 486-4658-1-ND
F2: 375mA T; Fuse_Littelfuse-NANO2-451_453; Digikey 5923-0680L0375-01CT-ND
H1, H2, H3, H4: MountingHole; MountingHole_4mm; not fitted
J1: 24V_IN; TerminalBlock_Phoenix_PT-1,5-2-3.5-H_1x02_P3.50mm_Horizontal; Digikey 277-1721-ND
J2: RELAIS_OUT; TerminalBlock_Phoenix_PT-1,5-2-3.5-H_1x02_P3.50mm_Horizontal; Digikey 277-1721-ND
J3: TASTER_1; TerminalBlock_Phoenix_PT-1,5-2-3.5-H_1x02_P3.50mm_Horizontal; Digikey 277-1721-ND
J4: TASTER_2; TerminalBlock_Phoenix_PT-1,5-2-3.5-H_1x02_P3.50mm_Horizontal; Digikey 277-1721-ND
J5: RFID; PinHeader_1x08_P2.54mm_Vertical; not fitted
J6: DEBUG; PinHeader_1x08_P2.54mm_Vertical
J7: Reset; PinHeader_1x02_P2.54mm_Vertical; not fitted
L1: 4.7µH; L_Chilisin_BMRB00060650; Digikey 445-174746-1-ND
Q1: SI2310AHE3-TP; SOT-23; Digikey 353-SI2310AHE3-TP-ND
R1, R2, R6, R8: 2k2; R_0603_1608Metric; Power Rating 100mW; Digikey 13-RC0603FR-132K2LCT-ND
R3: 510; R_0603_1608Metric; Power Rating 100mW; Digikey 311-510HRCT-ND
R4: 1k; R_0603_1608Metric; Power Rating 100mW; Digikey 311-1.00KHRCT-ND
R5, R9: 3k3; R_0603_1608Metric; Power Rating 100mW; Digikey 311-3.30KHRCT-ND
R7, R10, R11, R16: 10k; R_0603_1608Metric; Power Rating 100mW; Digikey 311-10.0KHRCT-ND
R12, R13, R14, R15: 100R; R_0805_2012Metric; Power Rating 125mW; Digikey 311-100CRCT-ND
U1: TBA2-2411; Converter_DCDC_TRACO_TBA2-xxxx_Single_THT; Digikey 1951-3441-ND
U2: VO615A-2X009T; DIP-4_W8.89mm_SMDSocket_LongPads; Digikey VO615A-2X009TCT-ND
U3: ESP32-DEVKIT-V1; MODULE_ESP32_DEVKIT_V1; PARTREV N/A

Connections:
+3V3: J5.1, J6.8, R10.2, R11.2, R12.2, U3.1 (3V3)
+5V: C3.1, J6.7, L1.2, R3.2, R4.1, U3.30 (VIN)
+24V: C1.1, C2.1, F1.2, R1.1, U1.1 (+Vin)
+24V_IN: D1.2 (A2), F1.1, F2.2, J1.1
+24V_fused: D4.1 (K), F2.1, J2.1, R8.1, U2.4
/+5V_DCDC: L1.1, U1.6 (+Vout)
/FET_D: D4.2 (A), D5.1 (K), J2.2, Q1.3 (D)
/FET_G: Q1.1 (G), R5.1, R7.1
/LED_G: R13.1, U3.23 (D25)
/LED_G_A: D9.2 (A), R13.2
/LED_R: R14.1, U3.21 (D32)
/LED_R_A: D8.2 (A), R14.2
/LED_Y: R15.1, U3.22 (D33)
/LED_Y_A: D7.2 (A), R15.2
/OPT_A: R9.2, U2.1
/RELAIS_CONTR: R16.2, U2.3
/RELAIS_OUT: R9.1, U3.14 (D22)
/TASTER1: J3.1, R10.1, U3.4 (D2)
/TASTER2: J4.1, R11.1, U3.5 (D4)
D12: J6.3, U3.27 (D12)
D13: J6.4, U3.28 (D13)
D14: J6.2, U3.26 (D14)
D27: J6.1, U3.25 (D27)
GND: C3.2, D3.1 (K), D6.1 (K), D7.1 (K), D8.1 (K), D9.1 (K), J3.2, J4.2, J5.3, J6.5, J6.6, J7.2, R3.1, U1.4 (-Vout), U2.2
IRQ: J5.4
MISO: J5.5, U3.10 (D19)
MOSI: J5.6, U3.15 (D23)
unnamed: D2.2 (A), R2.2
unnamed: D3.2 (A), R4.2
unnamed: D5.2 (A), R6.2
unnamed: D6.2 (A), R12.1
unnamed: J7.1, U3.16 (EN)
unnamed: R1.2, R2.1
unnamed: R6.1, R8.2
unnamed: R7.2, R16.1
PGND: C1.2, C2.2, D1.1 (A1), D2.1 (K), J1.2, Q1.2 (S), R5.2, U1.2 (-Vin)
RST: J5.2, U3.8 (D5)
SCK: J5.7, U3.9 (D18)
SDA: J5.8, U3.11 (D21)

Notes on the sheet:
2mA
30mA
Fuse: 3403.0159.24
RFID Interface
LED Interface
5mA
0.6mA
Relais control
1mA
3mA
Debug Interface
Button Interface
250mA
ESP32
Power Supply
Fuse: 0680L0375-01
Minimum Load: ~10mA

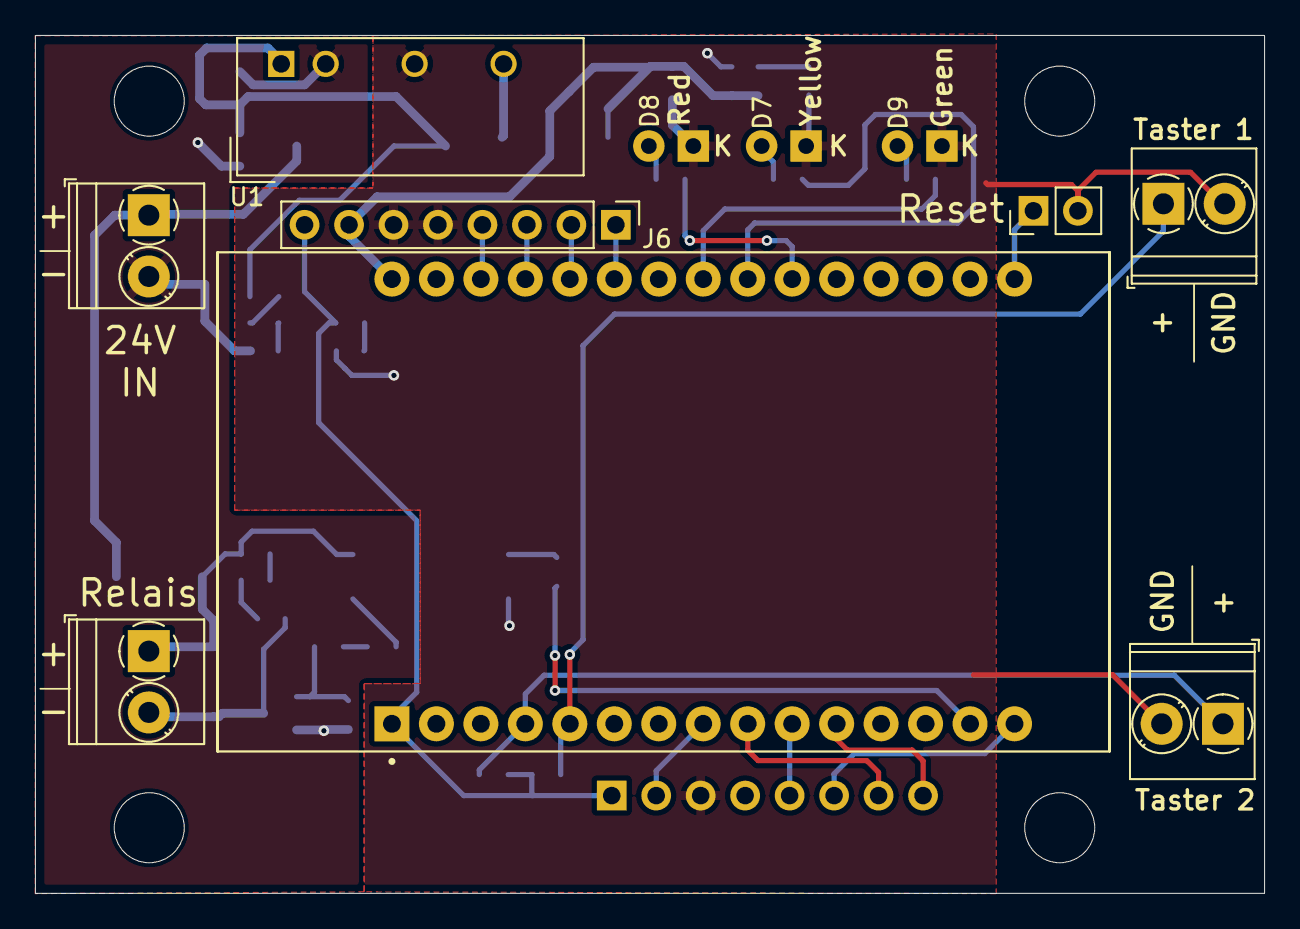
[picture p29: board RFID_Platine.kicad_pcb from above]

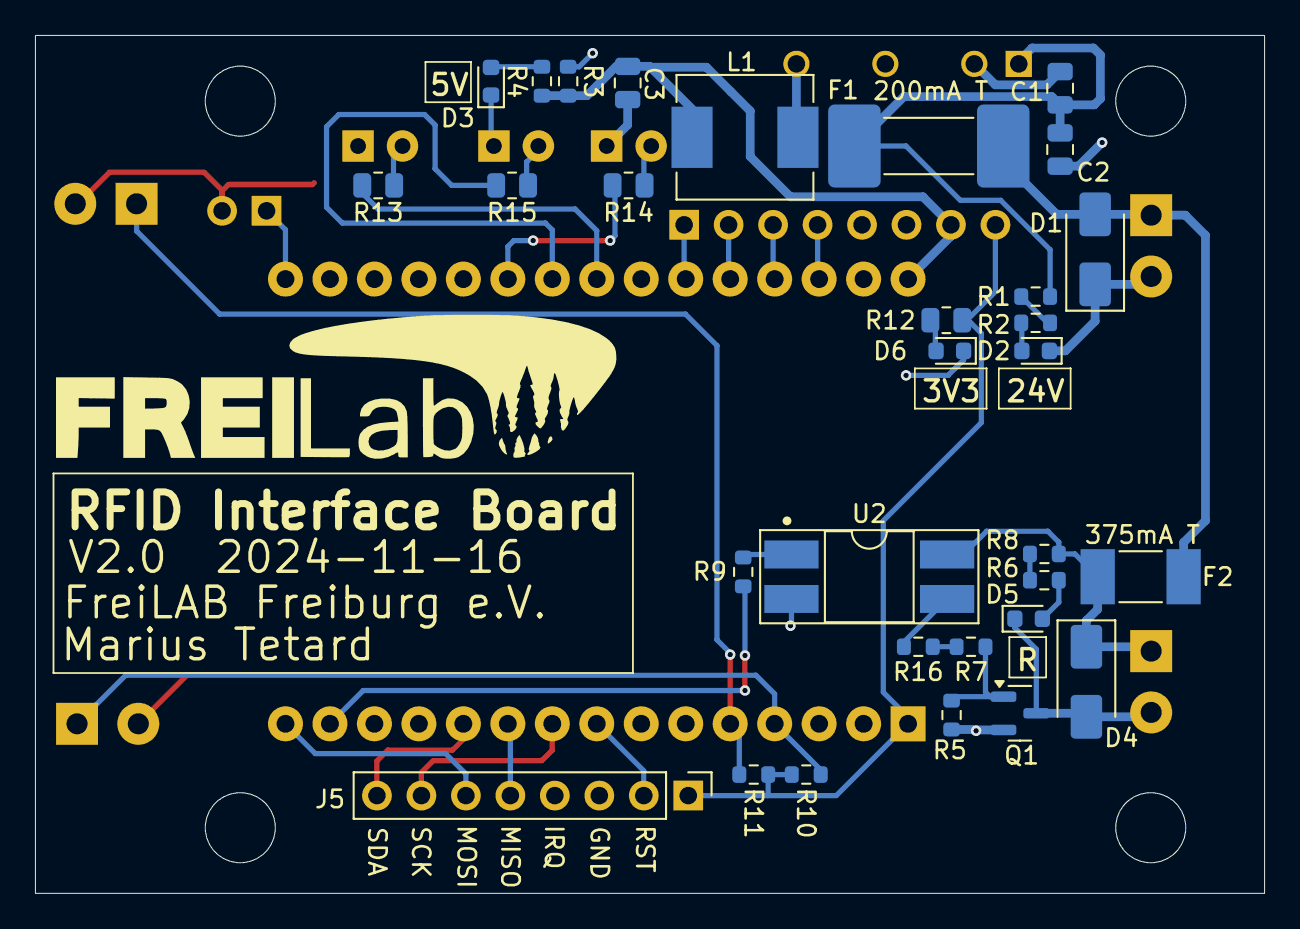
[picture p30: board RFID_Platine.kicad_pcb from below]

Board: 2 copper layers, 70.2 x 49.0 mm, 46 parts (31 on the bottom side), 38 nets.

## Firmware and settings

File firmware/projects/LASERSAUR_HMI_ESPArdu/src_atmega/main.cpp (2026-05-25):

#include <Arduino.h>
#include <EEPROM.h>
#include "ArduinoJson-v5.13.0.h"
#include "myFunctions.h"

uint16_t DisplayErrorScreen = 0;
uint32_t tempTicks = 0;

bool WaterFlowStopped = false;

uint16_t oldAbluftState = LOW;
float oldTemp[4] = {1000.0, 1000.0, 1000.0, 1000.0};

float offsetPres[4] = {0.0, 0.0, 0.0, 0.0};
bool firstStart = true;

unsigned int logCounter = 0;

// Flag wird im ISR gesetzt, Senden passiert im loop()
volatile bool postPending = false;

// Puffer für eingehende ESP-Nachrichten
static char espBuf[16];
static uint8_t espPos = 0;


// ─────────────────────────────────────────────────────────
// JSON-Payload via Serial3 an ESP senden
// ─────────────────────────────────────────────────────────

void sendLogToESP() {
    StaticJsonBuffer<300> jb;
    JsonObject& root = jb.createObject();
    root["WaterBT"]   = MeasurementData.WaterTempBT;
    root["WaterAT"]   = MeasurementData.WaterTempAT;
    root["PresF1"]    = MeasurementData.PresFilter1;
    root["PresF2"]    = MeasurementData.PresFilter2;
    root["PresF3"]    = MeasurementData.PresFilter3;
    root["WaterFlow"] = MeasurementData.WaterFlow;
    root["T1"]        = MeasurementData.Temp1;
    root["T2"]        = MeasurementData.Temp2;
    root["T3"]        = MeasurementData.Temp3;
    root["T4"]        = MeasurementData.Temp4;

    Serial3.print("POST:");
    root.printTo(Serial3);
    Serial3.println();
}

// ─────────────────────────────────────────────────────────
// Eingehende ESP-Nachrichten auswerten (nicht-blockierend)
// ─────────────────────────────────────────────────────────

void processSerial3() {
    while (Serial3.available()) {
        char c = Serial3.read();
        if (c == '\n') {
            espBuf[espPos] = '\0';
            espPos = 0;
            if (strcmp(espBuf, "PING") == 0) {
                Serial3.println("PONG");
            } else if (strncmp(espBuf, "ACK:", 4) == 0) {
                Serial.print("[ESP] ACK: ");
                Serial.println(espBuf + 4);
            } else if (strncmp(espBuf, "NACK:", 5) == 0) {
                Serial.print("[ESP] NACK: ");
                Serial.println(espBuf + 5);
            }
        } else if (c != '\r' && espPos < sizeof(espBuf) - 1) {
            espBuf[espPos++] = c;
        }
    }
}


// ─────────────────────────────────────────────────────────
// Setup
// ─────────────────────────────────────────────────────────

void setup() {
    Serial.begin(115200);   // USB-Debug via CH340 (Serial0)
    Serial3.begin(9600);    // ESP8266-Kommunikation via RXD3/TXD3

    MeasurementData.Temp1 = 0.0;
    MeasurementData.Temp2 = 0.0;
    MeasurementData.Temp3 = 0.0;
    MeasurementData.Temp4 = 0.0;

    configIO();

    Wire.setClock(1000);

    Mux_LCD_init();

    ScanI2CForDevices();    // falls Drucksensoren fehlen, stoppt das System hier

    // Timer0 für ~1kHz Ticker (Display-Rotation + Log-Intervall)
    OCR0A = 0xAF;
    TIMSK0 |= _BV(OCIE0A);

    // Timer1: Input Capture für Wasserfluss-Messung
    TCCR1A = 0x00;
    TCCR1B = 0x05;          // 16MHz / 1024 → TCNT1 inkrementiert alle 64 µs
    Ticks = 0;
    TIMSK1 = _BV(ICIE1) | _BV(TOIE1);

    Mux_LCD_clear();

    MeasurementData.Temp1 = 0.0;
    MeasurementData.Temp2 = 0.0;
    MeasurementData.Temp3 = 0.0;
    MeasurementData.Temp4 = 0.0;
    MeasurementData.Data1Filter.pressure = 0.0;
    MeasurementData.Data2Filter.pressure = 0.0;
    MeasurementData.Data3Filter.pressure = 0.0;
    MeasurementData.Data4Filter.pressure = 0.0;

    Serial.println(EEPROM.read(0x10), DEC);

//  if(EEPROM.read(0x10) == 0xF0)
//      Errors |= ERR_LASERADJUSTMENT;

    Serial.println("[ATmega] Bereit");
}


// ─────────────────────────────────────────────────────────
// Timer0 ISR (~1kHz)
// ─────────────────────────────────────────────────────────

ISR(TIMER0_COMPA_vect)
{
    static int TempCounter = 0;

    if(DisplayCounter < (LCD_TICKER_S * 1000))
        DisplayCounter++;

    // Alle 60 Sekunden: Flag setzen, Senden passiert im loop()
    if(logCounter++ >= 60000)
    {
        postPending = true;
        logCounter = 0;
    }

    if(digitalRead(PIN_CHI_ABLUFT) == HIGH)
        digitalWrite(PIN_RLY_KOMP, HIGH);
    else
        digitalWrite(PIN_RLY_KOMP, LOW);

    if(TempCounter++ >= 1000)
    {
        if(MeasurementData.Temp1 - oldTemp[0] > MAX_TEMPDIFF) tempDiffTooHigh = true;
        if(MeasurementData.Temp2 - oldTemp[1] > MAX_TEMPDIFF) tempDiffTooHigh = true;
        if(MeasurementData.Temp3 - oldTemp[2] > MAX_TEMPDIFF) tempDiffTooHigh = true;
        if(MeasurementData.Temp4 - oldTemp[3] > MAX_TEMPDIFF) tempDiffTooHigh = true;

        oldTemp[0] = MeasurementData.Temp1;
        oldTemp[1] = MeasurementData.Temp2;
        oldTemp[2] = MeasurementData.Temp3;
        oldTemp[3] = MeasurementData.Temp4;

        TempCounter = 0;
    }
}

// ─────────────────────────────────────────────────────────
// Timer1 ISR — Wasserfluss Input Capture
// ─────────────────────────────────────────────────────────

ISR(TIMER1_CAPT_vect) {
    if(bit_is_set(TCCR1B, ICES1)) {    // steigende Flanke
        TCNT1 = 0;
        WaterFlowStopped = false;
    } else {                            // fallende Flanke
        Ticks = ICR1;
    }
    TCCR1B ^= _BV(ICES1);
}

ISR(TIMER1_OVF_vect) {
    WaterFlowStopped = true;
}


// ─────────────────────────────────────────────────────────
// Loop
// ─────────────────────────────────────────────────────────

void loop() {

//  if(digitalRead(PIN_EEPROM_RESET) == LOW)
//  {
//      EEPROM.write(0x10, 0x20);
//      Serial.println(EEPROM.read(0x10),DEC);
//      Errors &= ~ERR_LASERADJUSTMENT;
//  }

    MeasurementData.WaterTempBT = TempLookup(analogRead(ADC_WT_BT));
    MeasurementData.WaterTempAT = TempLookup(analogRead(ADC_WT_AT));
    MeasurementData.Data1Filter = ReadPressureAndTemperature(PRESSURESENSOR1);
    MeasurementData.Data2Filter = ReadPressureAndTemperature(PRESSURESENSOR2);
    MeasurementData.Data3Filter = ReadPressureAndTemperature(PRESSURESENSOR3);
    MeasurementData.Data4Filter = ReadPressureAndTemperature(PRESSURESENSOR4);

    if(firstStart)
    {
        offsetPres[0] = MeasurementData.Data2Filter.pressure - MeasurementData.Data1Filter.pressure;
        offsetPres[1] = MeasurementData.Data3Filter.pressure - MeasurementData.Data2Filter.pressure;
        offsetPres[2] = MeasurementData.Data4Filter.pressure - MeasurementData.Data3Filter.pressure;
        firstStart = false;
    }

    MeasurementData.PresFilter1 = (MeasurementData.Data2Filter.pressure - MeasurementData.Data1Filter.pressure - offsetPres[0]) * 1000;
    MeasurementData.PresFilter2 = (MeasurementData.Data3Filter.pressure - MeasurementData.Data2Filter.pressure - offsetPres[1]) * 1000;
    MeasurementData.PresFilter3 = (MeasurementData.Data4Filter.pressure - MeasurementData.Data3Filter.pressure - offsetPres[2]) * 1000;

    MeasurementData.Temp1 = ReadTemperature(MCP9808_CH1);
    MeasurementData.Temp2 = ReadTemperature(MCP9808_CH2);
    MeasurementData.Temp3 = ReadTemperature(MCP9808_CH3);
    MeasurementData.Temp4 = ReadTemperature(MCP9808_CH4);

    tempTicks = getTick();
    if(tempTicks != 0 && !WaterFlowStopped)
        MeasurementData.WaterFlow = FlowLookup(10000000L / (2 * tempTicks * 64));
    else
        MeasurementData.WaterFlow = 0;

    ErrorHandling();

    // ISR hat postPending gesetzt → jetzt senden (außerhalb ISR-Kontext)
    if(postPending)
    {
        sendLogToESP();
        postPending = false;
    }

    // Eingehende ESP-Antworten verarbeiten (PING → PONG, ACK/NACK loggen)
    processSerial3();

    if(DisplayCounter >= (LCD_TICKER_S * 1000))
    {
        if(Errors == 0)
        {
            if(DisplayScreen < LCD_SCREENS - 1)
                DisplayScreen++;
            else
                DisplayScreen = 0;
        }
        else
        {
            for(int i = 0; i < MAX_ERRORS; i++)
            {
                DisplayScreen = ERR_BASE + (Errors & (1 << DisplayErrorScreen));
                DisplayErrorScreen++;
                if(DisplayErrorScreen == MAX_ERRORS) DisplayErrorScreen = 0;
                if(DisplayScreen != ERR_BASE) break;
            }
        }

        DisplayCounter = 0;
        Mux_LCD_clear();
    }

    LCD_Display();
}

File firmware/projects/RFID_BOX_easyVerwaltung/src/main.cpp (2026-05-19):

/**
 * @file main.cpp
 * @brief ESP32 RFID Login System (PoC - PlatformIO Migration)
 *
 * Diese Datei initialisiert einen ESP32 für RFID-basierte Login-Operationen.
 * Sie verwaltet die WiFi-Verbindung, initialisiert den MFRC522 Reader, liest
 * RFID-Karten und kommuniziert per HTTP GET mit dem Backend.
 *
 * Kontext:
 * - Migriert von Arduino IDE zu PlatformIO.
 * - Konfiguration und Geheimnisse werden aus "secret.h" geladen.
 * - Teil der neuen Architektur (Proof of Concept).
 * - CI/CD Integration via GitHub Actions für automatisierte Builds.
 * - Tags vorbereitet für zukünftige Releases
 *
 * Hardware: ESP32 Dev1
 * Bibliotheken: MFRC522, ArduinoLog, HTTPClient, WiFi.
 */

#include <Arduino.h>
#include "settings.h" // Lokale Maschinen-Konfiguration (ID, Name, Auth-Logik)

// --- GEHEIMNISSE (Secrets) ---
// 1. Lokale secret.h einbinden, falls vorhanden (für lokales Kompilieren)
#if __has_include("secret.h")
  #include "secret.h"
#endif

// 2. Fallbacks für GitHub-Build-Flags
// Diese Makros werden auf GitHub direkt vom Compiler injiziert.
#ifndef WIFI_SSID
  #define WIFI_SSID "NotSet"
#endif
#ifndef WIFI_PASSWORD
  #define WIFI_PASSWORD "NotSet"
#endif
#ifndef SERVER_IP
  #define SERVER_IP "0.0.0.0"
#endif
#ifndef MACHINE_ID
  #define MACHINE_ID "NoID"
#endif
#ifndef AUTHENTICATION_TOKEN
  #define AUTHENTICATION_TOKEN "NoToken"
#endif

// Hier folgen nun deine weiteren Includes
#include <SPI.h>
#include <MFRC522.h>
#include <WiFi.h>
#include <ArduinoLog.h>
extern "C" {
#include "easy_api.h"
}
#include "easy_api_esp32_transport.h"
#ifdef OTA_ENABLED
  #include <ArduinoOTA.h>
#endif

// --- Prototypen (Forward Declarations für C++) ---
void next_State();
void setLED_ryg(bool led_red, bool led_yellow, bool led_green);
void connectToWiFi();
void checkWiFiConnection();
void initRFID();
bool perform_auth_check();
int tryLoginID(String uid);
int tryHeartbeat(String uid);
String readID();
void blinkGreenSubtleSuccess();
void blinkYellowShortWarning();

//------------------------------------------------------------------------------
// State Definitions
//------------------------------------------------------------------------------

/**
 * @enum State
 * @brief Defines the different states of the RFID login system.
 */
enum State {
  STANDBY,         ///< System is idle, waiting for RFID input.
  IDENTIFICATION,  ///< System is verifying RFID credentials.
  RUNNING,         ///< System is active, machine is running.
  RESET            ///< System is resetting to standby state.
};

State currentState = STANDBY;
State nextState = STANDBY;
bool auth_check = true;
unsigned long stateChangeTime = 0;
unsigned long lastContinuousServerCheckMs = 0;
int continuousServerCheckFailCount = 0;

//------------------------------------------------------------------------------
// Pin Definitions
//------------------------------------------------------------------------------

#define MACHINE_RELAY_PIN 22  ///< Pin controlling the machine relay
#define BUTTON_RFID 4         ///< Button to stop machine / Taster 1
#define BUTTON_STOP 13        ///< Button to start machine / Taster 2

#define RFID_RST_PIN 5  ///< Reset pin for the RFID module
#define RFID_SS_PIN 21  ///< SDA pin for the RFID module

#define LED_RED_PIN 32     ///< Pin for red LED
#define LED_YELLOW_PIN 33  ///< Pin for yellow LED
#define LED_GREEN_PIN 26   ///< Pin for green LED

#define BUTTON_PRESSED 0   ///< Buttons active low

//------------------------------------------------------------------------------
// Global Variables and Instances
//------------------------------------------------------------------------------

const int TIME_GLITCH_FILTER_STOP = 100;  ///< 0.1s button debounce time
const int TIME_GLITCH_FILTER_RFID = 3000; ///< 3s button debounce time

MFRC522 mfrc522(RFID_SS_PIN, RFID_RST_PIN);  ///< Instance of the RFID module

String loggedInID = "0";     ///< Currently logged-in RFID card ID
String uid = "";             ///< UID read from an RFID card
bool isHttpRequestInProgress = false; ///< Flag to indicate an ongoing HTTP request

static easy_api_client_t api_client;
static char api_req_buf[512];
static char api_res_buf[2048];
static char session_id[EASY_API_MAX_SESSION_ID_LEN];
static uint32_t heartbeat_interval_ms = 2000;
static uint32_t heartbeat_fail_limit = 40;

//------------------------------------------------------------------------------
// Setup Function
//------------------------------------------------------------------------------

/**
 * @brief Initializes hardware, connects to WiFi, and sets up the RFID module.
 */
void setup() {
  Serial.begin(115200);
  Log.begin(LOG_LEVEL_VERBOSE, &Serial); // Initialize logging

  Log.notice("Starting setup ...\n");

  // Relay control output
  pinMode(MACHINE_RELAY_PIN, OUTPUT);

  // LEDs pins
  pinMode(LED_RED_PIN, OUTPUT);
  pinMode(LED_YELLOW_PIN, OUTPUT);
  pinMode(LED_GREEN_PIN, OUTPUT);

  // RFID card detection button
  pinMode(BUTTON_RFID, INPUT_PULLUP);
  // Logout button
  pinMode(BUTTON_STOP, INPUT_PULLUP);

  // set initial states
  digitalWrite(MACHINE_RELAY_PIN, LOW);  // Ensure machine is off initially
  setLED_ryg(1, 1, 1); // all LEDs on

  delay(1000);  // wait for pullups to get active

  connectToWiFi();

  {
    easy_api_config_t cfg = {};
    cfg.base_url            = "http://" SERVER_IP;
    cfg.service_id          = MACHINE_ID;
    cfg.service_token       = AUTHENTICATION_TOKEN;
    cfg.timeout_ms          = 5000;
    cfg.request_buffer      = api_req_buf;
    cfg.request_buffer_size = sizeof(api_req_buf);
    cfg.response_buffer     = api_res_buf;
    cfg.response_buffer_size = sizeof(api_res_buf);
    cfg.transport           = easy_api_esp32_transport;
    cfg.transport_context   = nullptr;
    easy_api_init(&api_client, &cfg);
  }

  // TODO: Health-Check deaktiviert — Server gibt active:false zurück, serverseitig klären.
  //       Siehe https://github.com/FREILab/easyVerwaltung/issues/60
  Log.warning("[Health] Startup health check skipped (see TODO).\n");

#ifdef OTA_ENABLED
  ArduinoOTA.setHostname(OTA_HOSTNAME);
  ArduinoOTA.begin();
  Log.notice("[OTA] Ready. Hostname: %s\n", OTA_HOSTNAME);
#endif

  initRFID();

  // indicate successful startup
  setLED_ryg(0, 0, 0); 
  delay(100);
  setLED_ryg(0, 0, 1);  // green flicker indicator
  delay(100);
  setLED_ryg(0, 0, 0);

  Log.notice("Setup complete.\n");
}
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

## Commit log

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2026-05-14 Refactor firmware/projects: einheitliche Benennung und neue Struktur
    Umbenennung aller Projektordner auf konsistente Namen:
    - RFIDBOX_PoC → RFID_BOX_legacy
    - RFIDBOX_Easy → RFID_BOX_easyVerwaltung
    - RFID_Door_Poc → DOOR_legacy
    - MachineNodes → MachineNode
    - RFIDBOX_PoC.zip entfernt (Backup-Artefakt)
    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
2026-05-14 Umbenennung aller Projektordner auf konsistente Namen: - RFIDBOX_PoC → RFID_BOX_legacy - RFIDBOX_Easy → RFID_BOX_easyVerwaltung - RFID_Door_Poc → DOOR_legacy - MachineNodes → MachineNode - RFIDBOX_Po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
    Neuer leerer Projektordner DOOR_easyVerwaltung angelegt (Arduino Uno R4
    WiFi, easyVerwaltung-API, steht noch aus).
    secret.h / secret.h.example vereinheitlicht: WiFi-Credentials nur noch
    in platformio.secrets.ini, nicht doppelt in secret.h. SERVER_HOST statt
    SERVER_IP in allen Projekten.
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2026-05-14 Add Sammelplatine firmware projects (legacy import + easyVerwaltung skeleton)
    SAMMELPLATINE_legacy: Legacy-Sketch (Sammelplatine_Software.ino) aus Arduino
    IDE nach PlatformIO migriert. Arduino Mega + Ethernet2-Shield, Sensoren
    MPL3115A2/MCP9808, Monitoring-Board für den Lasersaur-Laserschneider.
    SAMMELPLATINE_easyVerwaltung: leeres Skelett für spätere Migration auf
    easyVerwaltung-API.
2026-05-14 Fix PlatformIO build configs: correct platform IDs and library registry names
    - DOOR_easyVerwaltung: arduino_uno_r4 → renesas-ra, esptool/espota → arduino
    - LASERSAUR_HMI_legacy: Ethernet2 and Adafruit sensor libs via GitHub URLs
    - LASERSAUR_HMI_easyVerwaltung: Adafruit sensor libs via GitHub URLs
2026-05-14 Remove Lasersaur laser cutter from RFID_BOX projects; add HMI to workspace
    The Lasersaur laser is managed by LASERSAUR_HMI_* — pair_laser_cutter
    and its environments are not RFID_BOX territory. xTool laser stays.
    Workspace updated to include LASERSAUR_HMI_legacy and _easyVerwaltung.
2026-05-15 Refactor DOOR project for WiFi support: update platform and board settings, remove Ethernet fallback, and add OTA upload functionality.
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2026-05-17 Add server keepalive functionality and update button pin to resolve conflict
    [main.cpp, settings.h]
2026-05-19 Update OTA Fleet Plan with current status, open issues, and testing roadmap
2026-05-24 Add error JSON files and update WiFi connection logic in main.cpp
    [main.cpp]
2026-05-24 Refactor firmware structure for RobotDyn UNO+WiFi R3: - Update README with hardware details and architecture overview. - Enhance platformio.ini for environment configurations. - Implement main logic 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
2026-05-25 RFID Box: WiFi, OTA und Wireless-Debug (Telnet) eingerichtet
    - TelnetStream auf Port 23 spiegelt Serial-Output über WiFi (MultiPrint)
    - PlatformIO monitor_port auf socket://<hostname>.local:23 gesetzt
    - Debug-Meldungen für Karte erkannt/gezogen, Stop-Taster, Relay an/aus
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2026-05-25 Fix ESP8266 crash-loop on WiFi failure + add Telnet heartbeat
    - TelnetStream.begin() jetzt unconditional in setup() → kein Crash
    mehr wenn WiFi beim Boot nicht erreichbar ist
    - startNetServices() mit Guard-Flag initialisiert MDNS + OTA einmalig
    beim ersten WiFi-Connect (setup oder wifiReconnect)
    - resolve_mdns.py als extra_scripts für beide OTA-Environments
    - Heartbeat alle 5s via Telnet: Uptime, WiFi-IP, State
    POC erfolgreich getestet: RFID-Scan, OTA, Telnet-Monitor.
    [main.cpp, settings.h]
2026-05-25 Add ESP8266 WiFi modem functionality and integrate with ATmega
    - Implemented main functionality for ESP8266 to maintain WiFi connection and handle HTTP POST requests from ATmega.
    - Added Telnet debugging support and OTA updates via mDNS.
    - Created settings header for configurable parameters such as WiFi credentials and heartbeat intervals.
    - Introduced new functions for processing serial input, executing HTTP POST requests, and managing WiFi connections.
    - Added error handling for WiFi connection failures and server response codes.
    - Established communication protocol between ESP8266 and ATmega for heartbeat and data transmission.
    - Created myFunctions.cpp and myFunctions.h to manage sensor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
    [main.cpp, myFunctions.cpp, myFunctions.h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]
2026-05-25 Update README.md: Add details about onboard and external current sensor variants for machine hour tracking
2026-06-05 Enhance network reliability: Implement WiFi stack reset after consecutive connection failures and ensure network services restart on reconnect
    [main.cpp]
2026-06-16 Refactor waitMotorOK function to accept LED state parameters and implement RFID debounce cooldown to prevent duplicate events
    -> läuft stabil und schnell
    [main.cpp, settings.h]
2026-06-27 add old files
    [0680L0375-01.step, 3403.0159.24.STEP, Female2.54MM1x15.step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]
2026-08-06 RFID_BOX_legacy: periodic RC522 hard-reset in STANDBY
    Matches the "alive-but-not-reading" pattern already diagnosed on the
    door project (EMI glitches the RF frontend while VersionReg still
    reads valid). Reset only fires while idle, never during
    IDENTIFICATION/RUNNING/RESET, so an active machine session is never
    interrupted.
    [main.cpp]
2026-08-06 DOOR: tuer-01 Fix-Status dokumentieren
    tuer-01 wurde am 2026-07-02 geflasht und verifiziert, tuer-02 steht noch aus.
2026-08-21 Kicad-Add PN532 (NFC), Change Schematic Power, PCB arrange Power
    [FRL-RFiD_Box.kicad_pcb, FRL-RFiD_Box.kicad_sch, RS6-2405S.step]
2026-09-07 docs: rework machine node board split and fix stop sequencing
    Rename PCB-A/B/C to MCU/I/O/RFID boards; split I/O-Board into two
    exclusive population variants (230V direct switching vs. potential-free
    24V for an external contactor); move NAMUR I/O off the base board into
    a generic, optional Extension Board (NAMUR / Digital-I/O variants); add
    a separate E-Stop Extension Board for machines needing a power-to-release
    brake or a Notaus-loop interrupt (e.g. FKS).
    Fix a safety-relevant bug in the stop sequencing: the hard stop button
    previously cut the main supply (Q1/K2) immediately, bypassing the
    configured run-on/nachlauf time. This has already caused a machine
    damage incident, because the mach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
2026-09-08 Enhance README with OLED example details
    Updated OLED example with additional details on mounting and connection.
2026-09-08 docs: split machine node doc, rewrite README as design overview
    Move the requirements ("Anforderungen aus Blackbox-Sicht", Ziel,
    Changelog) into a separate Anforderungen.md, and rewrite README.md from
    scratch as a landing-page-style design doc: Einleitung (what the RFID
    Node is and does), Aufbau (3D-printed dust-tight housing, cable entry
    order, stop button), and Elektronik (PCB stack: RFID-Board on top,
    MCU-Board in the middle, I/O-Board at the bottom with its two
    population variants). Further design chapters to follow.
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2026-09-08 docs: add EMC protection, PE routing, Signalfluss chapter, 24V relay coil supply
    Power Distribution: add mains-side EMC filter + surge protection, inrush
    current limiting (NTC), and a contact snubber on the load relay to cope
    with a "dirty" workshop mains and inductive loads; add a PE pass-through
    net from mains input to switched output (no bond to the plastic
    enclosure). Rework the control-path supply chain to transformer ->
    rectifier -> REC6K-4824SAW DC/DC module (isolated 24V) -> 5V regulator
    -> 3V3 regulator, since the load relay coil needs 24V rather than 5V;
    the new 24V rail feeds the coil directly.
    Add a new Signalfluss chapter/diagram tracing the control-signal path
    (RFID card -> NF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
2026-09-08 docs: add Bauteilauswahl/TODO chapters, fix diagram inconsistencies
    Add a Bauteilauswahl chapter with concrete part suggestions (small,
    cheap) for every function block introduced so far, including a rough
    per-line price sum with an explicit caveat that it isn't a real BOM
    total (quantities not accounted for).
    Fix issues found in a consistency pass: drop a leftover "PWR" class
    reference with no matching node in the block diagram; correct the
    Signalfluss chapter, where the prose still claimed the stop button
    hardware-interlocks the main relay driver directly (contradicting the
    already-documented stop-sequencing fix) while the diagram was missing
    the E-Stop board's hardware interlock edge enti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
2026-09-08 docs: make load measurement standard for the 230V variant
    Team review of revision 1.1 favored always populating the load
    measurement on the 230V variant (not just optionally): it lays the
    groundwork for future usage-based billing/limits, makes actual
    consumption traceable, and helps size mains connections at new
    locations. Update requirement I4 from optional to a must-requirement
    for the 230V variant, with a short rationale, and bump to revision 1.2
    with a changelog entry.
2026-09-09 docs: split Bauteilauswahl columns, add real distributor data for Q1/Trafo/etc.
    Split the Bauteilauswahl table into separate Hersteller/Herstellerteilenummer
    and Lieferant/Bestellnummer columns instead of one combined "Bauteil" and
    "Bezugsquelle" column, so each part's manufacturer identity and its actual
    sourcing are tracked independently.
    Replace several placeholder/estimated entries with real, distributor-verified
    parts and prices: ESP32-S3-WROOM-1-N16R8 (Mouser), Displaytech DT010ATFT OLED
    (Mouser), MCP39F51A (Farnell), NXP PN5321A3HN/C106 (Mouser), RECOM RFB-0505S
    and REC6K-2424SAW (Mouser), WAGO 2604-1103 (Digikey), and the transformer
    (Signal Transformer 14A-10R-24, Mouser).
    Replace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
2026-09-09 docs: fill Bauteilauswahl with real parts, fix EMV/K2/K3/BR3 consistency
    - EMV-Filter block renamed to EMV Maßnahmen, sub-parts (MOV, Gleichtaktdrossel,
    X2-Kondensator) explained in prose instead of the node label
    - Filled in real distributor parts/prices for shunt, rectifier, 5V regulator,
    3V3 LDO, K2/K3 relays, polyfuses, LED-Ring, buzzer with datasheet-based
    sizing checks; corrected wrong OLED/SMD/package descriptions
    - Reduced K2/K3 contact rating from 24V/1A to the actually needed 24V/100mA
    across README.md and Anforderungen.md (E4, BR1, enclosure labeling), with
    a new changelog entry
    - Corrected README text that wrongly claimed a firmware-independent hardware
    bypass for th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
2026-09-10 docs: optimize I/O-Board footprint (AC/DC module, 2-pole relay, fuse concept)
    - Replace AC/AC transformer + rectifier + DC/DC converter with a single
    isolated Mean Well IRM-10-24 AC/DC module; simplify Power Distribution
    diagram and signal legend accordingly (datasheet-verified: 10W/24V rating,
    4.2kVac isolation, generous I/P-O/P pin spacing)
    - Replace single-pole Finder 62.22 load relay with 2-pole TE T92S11D12-24
    (switches L+N together, addresses unclear N/L wiring in the workshop;
    datasheet-verified contact/isolation ratings)
    - Split the generic fuse BOM line into concrete F1 (soldered device fuse)
    and F2 (socketed load-output fuse + holder + spare); document F1 as an
    explic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
2026-09-10 start design
    [PoC.kicad_pcb, PoC.kicad_sch]
2026-09-12 Konkretisiere EMV-Bauteile und NTC in BOM, verschiebe PoC-KiCad-Projekt nach ECAD/IO_Board
    - EMV Maßnahmen in Bauteilauswahl auf MOV, X2-Kondensator und Gleichtaktdrossel
    mit realen Herstellerteilen und Digikey-Bestellnummern aufgesplittet
    - NTC von 10R/3.5A (zu gering für 8A Lastpfad) auf Bourns BN-LG15Y2R5MYB
    (2.5R/8A) korrigiert
    - cad/PoC KiCad-Projekt nach ECAD/IO_Board umbenannt (laufender Layout-Fortschritt)
    - .gitignore um Backup-Ordner des neuen ECAD-Pfads ergänzt
    [IO_Board.kicad_pcb, IO_Board.kicad_sch]
2026-09-12 Optokoppler auf Vishay VO615A-X017T (verstärkte Isolierung) umgestellt, IO-Board Layout-Fortschritt
    - PC817 durch Vishay VO615A-X017T ersetzt: VDE 0884-5 zertifizierte verstärkte
    Isolierung passend zur restlichen Schutzklasse-II-Auslegung (Relais, IRM-10-24),
    da der Optokoppler die einzige Isolationsbarriere der Lastmessung ist
    - IO_Board KiCad-Projekt: Platzierungs-Fortschritt
    [IO_Board.kicad_pcb, IO_Board.kicad_sch]
2026-09-22 Designator-Umnummerierung IO-Board in README nachziehen, BOM nach Bauteilgruppen gliedern
    - README: alle IO-Board-Designatoren (J300, RV300, C300-C306, L300, F300,
    F302, K300, RT300, R300, U300-U306, U304/U305) in Fließtext, beiden
    Mermaid-Diagrammen und der Bauteilauswahl nachgezogen
    - Fehlende 3V3_ISO-Versorgungsstrecke (U302 -> U300 -> Lastmessung U303) im
    Power-Distribution-Diagramm ergänzt, Signalfluss-Diagramm entsprechend von
    [5V] auf [3V3] korrigiert
    - Neue BOM-Zeilen für bislang nur im Chat recherchierte Stützkondensatoren
    (C301-C306) und den zweiten isolierten 3V3-Regler (U300) ergänzt
    - Bauteilauswahl in 8 Kategorien (ICs & Module, Widerstände, Kondensatoren,
    Ind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
    [IO_Board.kicad_sch, MCU_Board.kicad_pcb, MCU_Board.kicad_sch]
2026-09-22 Layout-Regeln ergänzt, Power Distribution überarbeitet, FMEA aufgenommen
    Neues Kapitel "Leiterbahnbreiten und Abstände": Stackups der drei Boards,
    Breiten- und Via-Tabellen je Board nach IPC-2221 bei ΔT 5 K, Abstandsmatrix
    der vier Domänen (Netz, ISO-Insel, SELV, Feld) und die Auslegung des
    Messnetzteils.
    Vier Korrekturen am I/O-Board, entstanden beim Durchrechnen von Thermik und
    Isolationsbarriere:
    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
    [IO_Board.kicad_sch]
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2026-09-23 Messinsel über isolierten Digitalisolator statt Kondensatornetzteil
    Das Kondensatornetzteil der ISO-Messinsel entfällt. Der ISOW7721 (U300)
    versorgt sie aus der SELV-Seite und führt zugleich die UART über die
    Barriere; er ersetzt damit den LDO U302 und beide Optokoppler U304/U305.
    Auslöser war der X2-Vorschaltkondensator, der im Flächenbudget des
    I/O-Boards nicht unterzubringen war.
    Die 8 mm Luft- und Kriechstrecke kommen jetzt aus dem Bauteil (VDE
    0884-17, UL 1577 5 kVrms) statt aus einer Layoutforderung.
    Schaltplan: U300 mit Abblockung C307–C317 und Ferriten FB300–FB307,
    U302/U304/U305 entfernt.
    README: Abschnitt 4 neu gefasst, Power-Distribution-Diagramm korrigiert
    (Lastmessu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
    [IO_Board.kicad_pcb, IO_Board.kicad_sch]
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2026-09-23 update from lib
    [IO_Board.kicad_sch]
2026-09-24 Relaistreiber bestueckt, README gestrafft
    Treiber des Lastrelais vollstaendig ausgelegt: Low-Side-NMOS Q300 und
    High-Side-PMOS Q301 in Reihe in der Spule, dazu Q302 als Pegelwandler
    fuer den symmetrischen 47k/47k-Gate-Teiler von Q301. Die Symmetrie ist
    zwingend, unsymmetrisch laege Vgs ueber dem Gate-Limit von +/-20V.
    Bauteile: 2N7002NXAKR (Q300, Q302), BSS84AK (Q301), BAS16LT1G (D305).
    D305 bleibt im SOT-23 statt SOD-323 — verdrehsicher und in der
    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
    [IO_Board.kicad_pcb, IO_Board.kicad_sch]
2026-09-24 Datenblattnamen korrigiert
    Nesxperia -> Nexperia (BSS84AK), und der BAS16L ist von onsemi, nicht
    Nexperia. Beide folgen jetzt dem Schema Hersteller_Teilenummer.pdf der
    uebrigen Ordner; die Diode ist nach der bestellten Teilenummer benannt
    statt nach der Dokumentnummer.
2026-09-25 fix some parts
    [IO_Board.csv, IO_Board.kicad_pcb, IO_Board.kicad_sch]
2026-10-06 IO_Board 230V reviewfertig, README nachgezogen
    Schaltplan:
    - PE als ein Netz (PIN_PE) inkl. Y-Mittelabgriff C309/C310
    - FB305 entfernt, GND1/GNDIO/LF von U300 zusammen auf GND (Datenblatt)
    - Ferrite FB303/304/306/307 auf BLM15EX331SN1D 330R 0402
    - R310 entfernt, Stromkanal als reine Kelvin-Messung
    - ISO_EN von U300 Pin 5 auf J302.4, Pull-up R318 47k nach VDD
    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
    [IO_Board.csv, IO_Board.kicad_sch]
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2026-11-01 IO_Board: Symbole aus der Bibliothek aktualisiert
    In KiCad per "Update Symbols from Library", Value bewusst ausgenommen,
    damit die generischen Bauteilwerte erhalten bleiben.
    Raeumt vor allem die SnapEDA-Importreste aus den Instanzen: SnapEDA_Link,
    SNAPEDA_PN, Purchase-URL, Price, Package, PARTREV, MP, STANDARD,
    Manufacturer Number, Part Number. Netto 135 Zeilen weniger.
    Die lib_id zeigen dabei noch auf aa_MyParts, aktualisiert wurde also aus der
    alten Bibliothek - das Umhaengen auf die 0_*-Bibliotheken folgt separat.
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2026-11-01 IO_Board: Bibliotheksinhalt aktualisiert, Power-Feldpositionen zurueckgeholt
    Zwei Dinge in einem Commit, weil sie im Arbeitsbaum zusammen lagen:
    1. "Update Symbols from Library" aus den neuen 0_*-Bibliotheken, in KiCad
    ausgefuehrt, Value erneut ausgenommen. Bringt den kleinen Ferrit (Pins von
    +-3.81 auf +-2.54, Koerperbreite 3.658 statt 5.538) und die neuen
    Parameterfelder an die Instanzen: Current/DCR/FootprintSymbol an den
    Ferriten, Dielectric/Voltage Rating an den Folienkondensatoren,
    Power/Tolerance an den Widerstaenden.
    Nachgeprueft: 0 von 79 Instanz-Values geaendert, die generischen Werte
    sind erhalten. ERC meldet jetzt 0 lib_symbol_mismatch, der Schaltplan ist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
2026-11-02 IO_Board: Textfelder der Power-Symbole auf den Bibliotheksstand
    GND, GND_ISO, Earth, +5V und +24V standen schief: KiCads Autoplacer hatte
    sie nicht nur verschoben, sondern auch (justify left) angehaengt - statt
    zentriert unter dem Symbol stand der Text linksbuendig daneben, und zwar bei
    jeder Instanz anders.
    Mein Restore von gestern hat das nicht behoben, sondern nur auf einen
    frueheren, ebenfalls autoplatzierten Stand zurueckgesetzt. Jetzt wird der
    Property-Block aus der Bibliotheksdefinition neu gebaut: Position aus deren
    Offset, Effects von dort uebernommen, nur Wert und die Flags der Instanz
    bleiben. Damit sieht es aus, als waere das Symbol frisch platziert worden.
    Zur Y-Achse: in Symb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
2026-11-03 RFID-Board: NFC-Seite auf Bibliotheksteile, Quarzlast unbestückt
    Alle zehn Widerstände und siebzehn Kondensatoren tragen jetzt Footprint,
    MPN und beide Bestellnummern — zusammen 1,44 € in der Zehnerstaffel.
    Drei Werte ändern sich dabei:
    - R206/R207 werden 2R49 im 1206. 2,49 Ω ist der E96-Wert zum Rechenwert
    2,51 Ω des Matchings; 1206 muss es sein, weil der Antennenzweig rund
    0,23 A führt und je Widerstand 126 mW anfallen — über den 100 mW eines
    0603 und über der Vorgabe von 0,25 W aus antenna/README.md.
    - C207/C208 im Empfangszweig werden C0G statt X7R. Dieselbe Reihe wie die
    Anpassung, gleicher Preis, kein Drift.
    - C200/C201 werden 8,2 statt 8 pF: die 8,0 pF der Reih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
2026-11-04 RFID_BOX: Bauteile für den Rest der Schaltung, Datenblätter, TODOs
    Zehn Datenblätter abgelegt, dazu die Ordner Crystal, Inductor, Module,
    Logic, Switch, Buzzer, LED und LED_Driver. Die Links kommen von Mouser,
    dessen Dokumente für die Bauteilanlage die brauchbareren sind; wo Mouser
    keinen Link führt, steht der Hersteller.
    Stromsensor U302 auf MCP39F511AT-E/MQ. Die bisherige Bestellnummer ist bei
    Digi-Key bei einem Stück, bei Mouser bei 31; dieselbe Chipvariante als
    Rolle hat Digi-Key 2.671 mal. Netzliste unverändert.
    README: die 3,3 V erzeugt ab jetzt jede Platine selbst — U307 auf dem
    I/O-Board für die Eingangsseite des Isolators, U103 auf dem MCU-Board für
    ESP32, NFC und Displ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
2026-11-04 RFID_BOX: Kostenkapitel überarbeitet, Relais und Klemmen sind gesetzt
    Lastrelais, Feldklemmen und NFC-Frontend stehen jetzt unter „Nicht
    verhandelbar" statt in der Liste. Das Relais war eine lange Suche und die
    Anforderungen dazu sind fix; die Hebelklemme bleibt, weil sie ohne Werkzeug
    bedienbar ist.
    Neu aufgenommen und nach vorn sortiert: Display und Statusliste. Beide
    zeigen denselben Zustand, einer von beiden kann weg — nicht beide, sonst
    bleibt als lokale Anzeige die siebenstellige Leiste, und die kann keinen
    Klarnamen. Das Display ist nirgends bepreist, weil es von EastRising kommt
    und in keiner Distributordatenbank steht; die Zahl fehlt und muss
    beschafft werden. Die Statusliste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
2026-11-09 RFID_BOX: Schaltpläne zur Review – RFID-Board V1.0, I/O-Board V1.3
    - Verbindung RFID-/I/O-Board als FFC 1,0 mm, 14-polig (SFW14S-2STE1LF),
    J302 gespiegelt zu J102; Spannungsteiler V24_SENSE und V3V3_IO_SENSE
    - ESP32-Pinbelegung vollständig verdrahtet (Pinbelegung_ESP32.md)
    - Versorgungssymbole eindeutig: +3V3 auf beiden Boards, +3V3_ISO, GND_ISO,
    PIN_PE mit eigenen Symbolen; Überbrückung der Isolationsbarriere nach
    Symbol-Update behoben
    - WAGO 2604-1103: Pinbelegung passend zum Footprint (L 1/4, N 2/5, PE 3/6)
    - Gate-Pulldown Q302, Schriftfelder RFID-Board, Exporte PDF/CSV
    - Datenblätter nachgetragen; CLEV6630B-Referenzdesign entfernt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

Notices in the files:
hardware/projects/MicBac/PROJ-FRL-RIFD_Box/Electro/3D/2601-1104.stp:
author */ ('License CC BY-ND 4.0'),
